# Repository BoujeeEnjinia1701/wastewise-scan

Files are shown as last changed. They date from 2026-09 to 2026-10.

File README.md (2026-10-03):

# WasteWise Scan

     

**Area:** Circular Materials · **TRL:** 3 of 9 (proof of concept on paper) · **Budget:** USD 150 value-engineering target; constructable prototype USD 167.50 in parts · **Difficulty:** 3 of 5

Handheld near-infrared scanner that identifies common plastic resins (PET, HDPE, PP, PS, PVC) in about a second using a low-cost multispectral sensor, shows the result and a local price grade, and logs scans. It pairs with WasteWise-ml for items the spectrum cannot resolve.

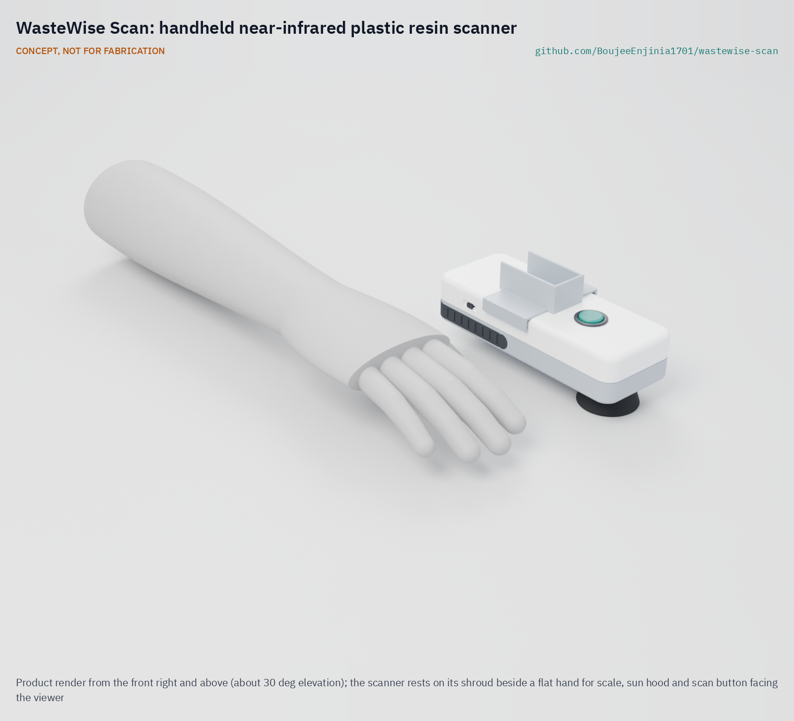
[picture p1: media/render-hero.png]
WasteWise Scan: handheld near-infrared resin scanner, product render


[Exploded render](media/render-exploded.png) · [Interactive 3D model](media/viewer.html) · [Concept blueprint (PDF)](media/concept-blueprint.pdf) · [General arrangement (PDF)](cad/drawings/WSC-DWG-001.pdf) · [Calculations](docs/04-calcs/01-sizing.md) · [Prototype build plan](docs/05-build-plan.md) · [Design decisions](docs/06-design-decisions.md) · [Review note](docs/REVIEW.md)

## Concept rationale

Resin type is a chemical property, so the scanner measures chemistry rather than appearance. Polymers absorb short-wave infrared light at wavelengths set by their C-H bonds, and eight discrete LEDs read against one InGaAs photodiode sample those bands for a small fraction of the cost of a spectrometer. The open Plastic Scanner project from TU Delft showed that this discrete-band approach can separate common resins; WasteWise Scan adds what a waste picker or cooperative needs in the field: a result in a third of a second, a local price grade, a log, and a clear "unknown" when the scanner cannot tell.

The design is open and garage-buildable because the people who would use it most sort plastic far from any service network. Every part is an off-the-shelf module or a 3D print, the price table is edited on the device, and no cloud service is involved. An open design lets cooperatives, universities and repair shops build, fix and adapt it, and lets labeled scan data be shared with Plastic Scanner and WasteWise-ml where licenses allow.

## Burning platform

Only 9 % of plastic waste is successfully recycled worldwide ([OECD, 2022](https://www.oecd.org/en/about/news/press-releases/2022/02/plastic-pollution-is-growing-relentlessly-as-waste-management-and-recycling-fall-short.html)), and the world generated 2.56 billion tonnes of solid waste in 2022, heading for 3.86 billion tonnes by 2050 without action ([World Bank, *What a Waste 3.0*](https://www.worldbank.org/en/publication/what-a-waste)).

Much of the recycling that does happen rests on informal workers. An estimated 15 to 20 million people work as informal waste pickers ([WIEGO, citing ILO data](https://www.wiego.org/informal-economy/occupational-groups/waste-pickers)), and one widely cited model estimates that the informal sector collects about 58 % of the plastic waste collected for recycling worldwide ([Lau et al. 2020, *Science*](https://doi.org/10.1126/science.aba9475), as cited in [ISWA, 2022](https://www.iswa.org/wp-content/uploads/2022/09/A-Seat-at-the-Table.pdf)). These workers sort by eye, touch and burn tests, and a wrong call costs them money or spoils a bale.

## Where it could be used

### By industry

| Industry | Use |
| --- | --- |
| Informal waste picking and cooperatives | Settle doubtful items at the pile and grade them against the local price table |
| Aggregators and small recyclers | Spot-check incoming bales for PVC in PET and other off-resin items before paying |
| Plastic scrap trade and export | Check that a bale is clean, pre-sorted single-polymer scrap before it is declared as such |
| Municipal and extended producer responsibility programs | Audit what collection points and sorting sheds actually recover |
| Training, NGOs and research | Teach resin identification and collect open, labeled spectra for classifiers such as WasteWise-ml |

### By country or region

| Country or region | Why it matters there |
| --- | --- |
| India | A national labour survey counted about 2.2 million waste pickers, as cited by WIEGO ([WIEGO](https://www.wiego.org/informal-economy/occupational-groups/waste-pickers)) |
| Brazil | Over 281,000 people work as waste pickers (catadores), many in cooperatives that grade and sell by material ([WIEGO](https://www.wiego.org/informal-economy/occupational-groups/waste-pickers)) |
| Colombia | Bogotá alone has more than 25,000 waste pickers ([WIEGO](https://www.wiego.org/informal-economy/occupational-groups/waste-pickers)) |
| Sub-Saharan Africa (for example Kenya and Nigeria) | Collection rates are low and waste is mostly disposed of unsafely, so value recovered by informal sorters matters more ([World Bank](https://www.worldbank.org/en/publication/what-a-waste)) |
| European Union | The Packaging and Packaging Waste Regulation, in force since 11 February 2025 and applying from 12 August 2026, aims to raise the use of recycled plastics in packaging, which depends on clean resin streams ([European Commission](https://environment.ec.europa.eu/topics/waste-and-recycling/packaging-waste_en)) |
| United States | Since 1 January 2021 most plastic scrap exports need the importing country's prior written consent unless they are clean, pre-sorted, almost single-polymer scrap ([US EPA](https://www.epa.gov/hwgenerators/new-international-requirements-export-and-import-plastic-recyclables-and-waste)) |

## What sparked the idea

The idea traces back to the Basel Convention's plastic waste amendments, agreed by about 180 governments in Geneva in May 2019 ([UNEP](https://www.unep.org/news-and-stories/press-release/governments-agree-landmark-decisions-protect-people-and-planet)) and in effect from 1 January 2021. Under them, plastic scrap "almost exclusively" of one non-halogenated polymer, or a PE, PP and PET mix destined for separate recycling, that is pre-sorted and clean can move as ordinary scrap (entry B3011), while mixed, contaminated or PVC-containing plastic needs prior written consent (entry Y48) ([US EPA](https://www.epa.gov/hwgenerators/new-international-requirements-export-and-import-plastic-recyclables-and-waste)). The rule turned resin identity into a legal and commercial line, yet the check it relies on happens by eye, at the pile, long before any laboratory. A handheld that tells PET from PP or PVC at the point of sorting is the missing tool that the amendments point at.

## Problem

Cameras cannot reliably tell PET from PP or HDPE, yet resin type sets the price a waste picker or small recycler receives. Commercial near-infrared sorters cost far too much for informal and small-scale operators.

## Concept

Press the soft shroud against an item and press the button. The scanner pulses eight near-infrared bands from 850 to 1,650 nm, reads the reflection with an InGaAs photodiode, and in about 0.33 s (calculated) shows the resin, a confidence mark and the local price grade. Black, dark and low-confidence items read "unknown" and can be passed to WasteWise-ml. A white reference inside the protective cap keeps it calibrated.

The scaffold named an AS7265x-class sensor, but that chip stops at 940 nm, short of the main polymer bands. The design uses discrete LEDs and an InGaAs photodiode instead, following the open Plastic Scanner project (decided by Amish, 2026-09-25).

At TRL 3 the calculations (WSC-CAL-001 v0.4) show the constructable design meets seven of fourteen requirements on paper. The mass requirement (R6, 250 g) is not met since the parts needed to build it were added: about 238 g, 258 g with the cap (8 g over) after the 2.0 mm shell walls decided on 2026-10-02. Following decisions Amish accepted on 2026-09-25 (WSC-DDR-003), clear items in sun are backed with the black calibration cap and the scanner refuses a result when it detects light through an unbacked item, and a clip-on hood shades the screen. Screen legibility in direct sun (R7), resin accuracy near 1,700 nm (R1) and the shared record with WasteWise-ml (R13) are at risk.

Full design precis: [docs/02-concept.md](docs/02-concept.md)

## Key components

- Ring of eight NIR and SWIR LEDs, 850 to 1,650 nm
- InGaAs photodiode with transimpedance amplifier and 24-bit ADC
- ESP32-S3 board with 1.9 in display
- One 18650 Li-ion cell with USB-C charging
- Printed rugged housing with black TPU light shroud
- Black calibration cap with white PTFE reference, also used to back clear items in sun
- Clip-on sun hood over the display
- Printed display frame, cell strap and optical head block; foam gasket and M3 screws into brass inserts

Value-engineering target: USD 150. Estimated cost of the constructable design: USD 167.50 (USD 17.50 over the target), from the priced bill of materials ([bom/bom.csv](bom/bom.csv)).

## Building the prototype

The [prototype build plan](docs/05-build-plan.md) (WSC-BLD-001) shows how to make each of the 21 components and put them together in 13 steps, with a making sketch for every printed or cut part and a picture for every joint and step. Most parts are 3D printed in PETG and TPU; the rest are bought optics, electronics and fixings, joined with M3 screws into brass heat-set inserts. Drawing the plan made the concept physically buildable: the shells, optics, cell and display gained fixings, recorded in [WSC-DDR-004](docs/decisions/0004-design-for-construction.md) for Amish's review. It is a plan; nothing has been built yet.

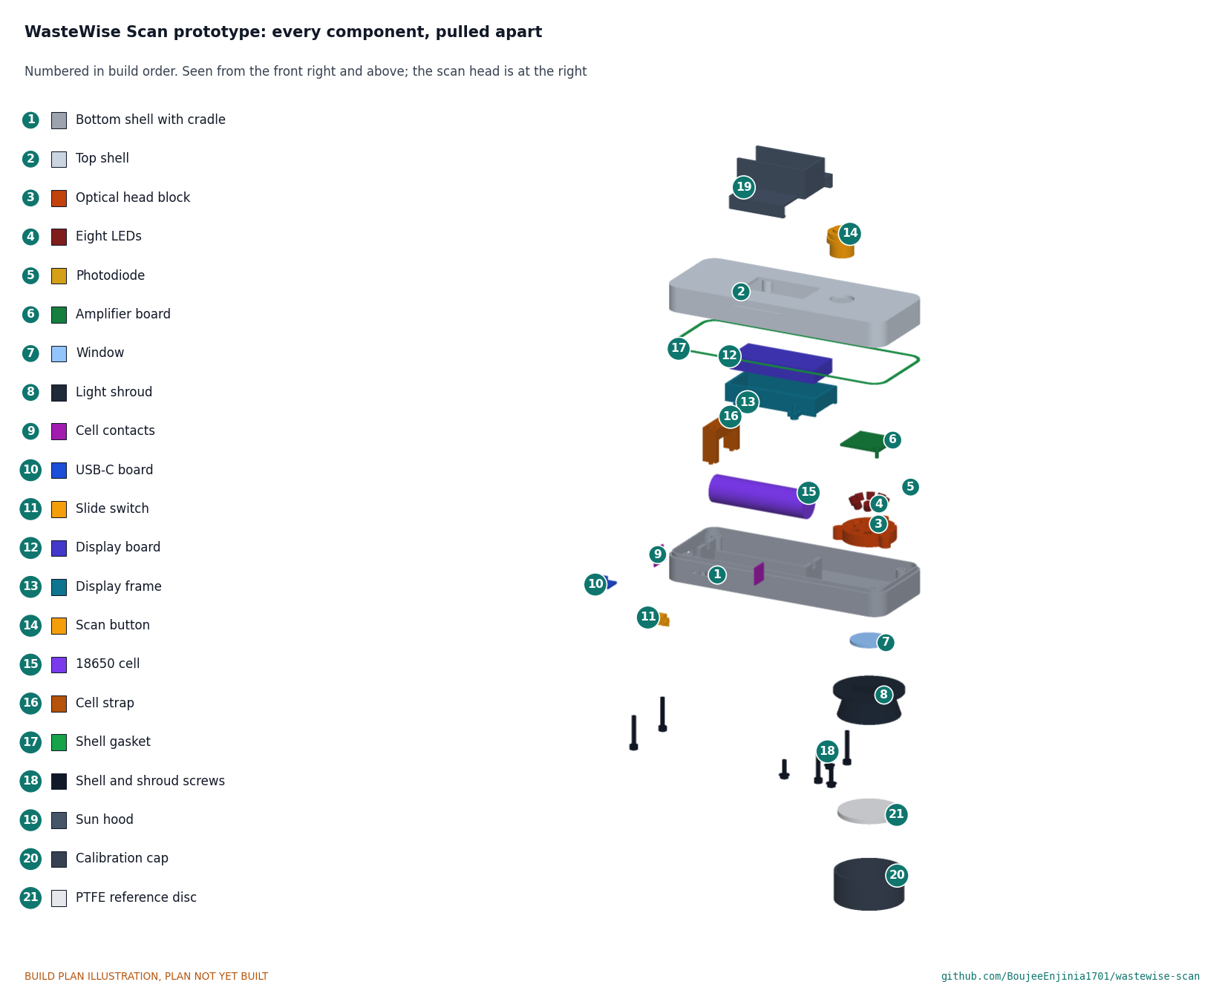
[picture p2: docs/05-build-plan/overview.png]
WasteWise Scan prototype: every component pulled apart and numbered in build order


## Safety

> **Safety:** The scanner identifies plastic resin only. Never use it to judge whether hazardous, medical or chemical waste is safe to handle. Black and dark plastics absorb NIR and read as unknown. The 18650 lithium-ion cell must be a protected cell, charged only with the built-in charger and kept out of heat. The SWIR LEDs are invisible; do not look into the window during a scan, and keep the hardware limit on LED on-time. Do not back sharp, broken or contaminated items with the cap by hand; scan them in shade instead.

## Repository layout

| Folder | Contents |
| --- | --- |
| `docs/` | Problem, concept, requirements, calculations and design decisions |
| `cad/src/` | build123d Python source, the source of truth for all geometry |
| `cad/step/`, `cad/stl/` | Exported models for FreeCAD, other CAD tools and printing |
| `cad/drawings/` | 2D sketches and dimensioned drawings |
| `bom/` | Bill of materials |
| `electronics/` | KiCad schematics and PCB layouts |
| `firmware/` | Microcontroller code |
| `media/` | Renders, perspectives and photos |
| `build-log/` | Dated prototyping notes |

## Documentation

Controlled documents follow the portfolio [documentation standard](.kit/STANDARDS.md). Each carries a document ID (WSC-PRC-001 for the precis), a version and a revision history. Branded PDFs are built with `python .kit/render.py` and attached to GitHub Releases when a document is tagged, for example `WSC-PRC-001/v1.0`.

## Credits

Designed by Amish Chadha. See [CONTRIBUTORS.md](CONTRIBUTORS.md) for roles. To cite this design, use [CITATION.cff](CITATION.cff) (GitHub shows it as "Cite this repository").

AI assistance (Claude) was used to accelerate concept renders, prototype documentation and first-pass sizing calculations. Design direction and all decisions are Amish Chadha's, recorded in this repository's decision records (`docs/decisions/`).

## Licenses

- **Hardware** (CAD, drawings, BOM, electronics): [CERN-OHL-S v2](LICENSE)
- **Software** (firmware, scripts, notebooks): [MIT](LICENSE-SOFTWARE)

A project of the [Design Molecule](https://designmolecule.com) lab.

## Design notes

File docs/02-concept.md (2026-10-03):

---
doc_id: WSC-PRC-001
title: WasteWise Scan design precis
project: WasteWise Scan
doc_type: Design precis
version: "0.7"
status: Draft
date: '2026-10-02'
author: Amish Chadha
license: CERN-OHL-S-2.0
revisions:
- version: "0.1"
  date: '2026-09-24'
  author: Amish Chadha
  change: Initial scaffold
- version: "0.2"
  date: '2026-09-25'
  author: Amish Chadha
  change: Populate to TRL 2 (architecture, first-order numbers, safety, media)
- version: "0.3"
  date: '2026-09-25'
  author: Amish Chadha
  change: TRL 3; decisions of WSC-DDR-001 applied; numbers from WSC-CAL-001; 47 kOhm gain and interleaved dark readings; new findings on sunlight, display and window crosstalk
- version: "0.4"
  date: '2026-09-25'
  author: Amish Chadha
  change: Recommendations accepted by Amish (DDR-002); WSC-DDR-003 applied (black cap as backing, dark-level prompt, sun hood, open-air crosstalk reading, shared record); numbers from WSC-CAL-001 v0.2
- version: "0.5"
  date: '2026-10-02'
  author: Amish Chadha
  change: Constructable design (WSC-DDR-004) and build plan WSC-BLD-001; components, mass and cost from WSC-CAL-001 v0.3; budget as a value-engineering target
- version: "0.6"
  date: '2026-10-02'
  author: Amish Chadha
  change: Open questions answered by Amish's decisions of 2026-10-02 (WSC-DEC-001)
- version: "0.7"
  date: '2026-10-02'
  author: Amish Chadha
  change: Mass restated for 2.0 mm shell walls (238 g, 258 g with cap); paper band study result; numbers from WSC-CAL-001 v0.4
---

# WasteWise Scan design precis

WasteWise Scan is a palm-sized scanner that the user presses against a plastic item. It flashes eight near-infrared bands one after another, reads the reflection with an InGaAs photodiode, and in about 0.33 s shows the resin, a confidence mark and the local price grade. The calculation note WSC-CAL-001 v0.4 shows that it meets the speed, battery, mass, sunlight, logging, calibration, eye-safety and prototype cost requirements on paper. Clear and translucent items are backed with the black calibration cap in sun, and a clip-on sun hood shades the display (decisions accepted by Amish on 2026-09-25, WSC-DDR-003). Direct-sun legibility (R7) is at risk because the hood cannot shade every sun angle, and resin accuracy (R1) remains at risk near 1,700 nm. Value-engineering target: USD 150. Estimated cost of the constructable design: USD 167.50 (USD 17.50 over the target). Since 2026-10-02 the design is constructable (WSC-DDR-004, open for Amish's review): screws, a gasket, an optical head block, a cell cradle and strap, a display frame and clip legs on the hood were added, and the scanner now weighs about 238 g (258 g with the cap) with the 2.0 mm shell walls Amish decided on 2026-10-02, so the 250 g mass requirement (R6) is not met, 8 g over with the cap. The prototype build plan is WSC-BLD-001 ([05-build-plan.md](05-build-plan.md)).

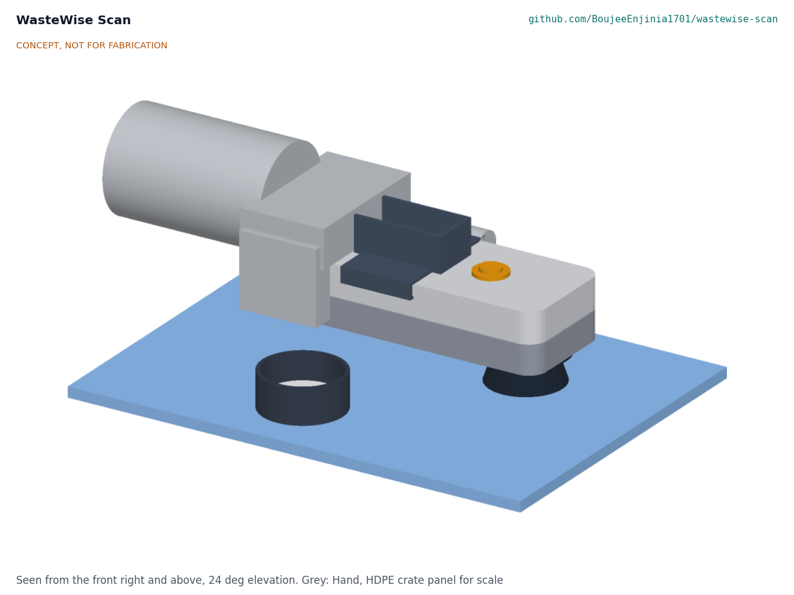
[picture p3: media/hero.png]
Hero render


*Figure 1. Concept render from the parametric model. The grey hand and the blue crate panel are for scale only.*

## The sensor

The scaffold named an 18-channel AS7265x-class sensor. That chip covers about 410 to 940 nm ([SparkFun Triad board](https://www.sparkfun.com/products/15050)), which misses the polymer absorption bands near 1,150 to 1,250 nm and 1,650 to 1,750 nm that NIR sorters rely on (see WSC-PRB-001 and the review by [Neo et al. 2022](https://doi.org/10.1016/j.resconrec.2022.106217)). Amish decided on 2026-09-25 (WSC-DDR-001, D1) to use the approach of the open [Plastic Scanner](https://github.com/Plastic-Scanner) project instead: discrete NIR and short-wave infrared (SWIR) LEDs from 850 to 1,650 nm and one InGaAs photodiode ([Hackaday, 2021](https://hackaday.com/2021/12/13/an-open-source-detector-for-identifying-plastics/)). It is still a low-cost multispectral sensor, so the pitch is unchanged.

## How it works

1. **Press.** The user presses the soft black shroud against a flat or gently curved part of the item. The shroud blocks sunlight falling on the spot and fixes the item 22 mm from the detector.
2. **Illuminate and read.** On a button press the firmware pulses each of eight LEDs in turn (850, 940, 1,050, 1,200, 1,300, 1,450, 1,550 and 1,650 nm; WSC-DDR-001 D4). Each band reading sits between two dark readings, so slow changes in ambient light are subtracted. If the mean dark level exceeds 0.71 times the weakest band reading, which happens when sunlight passes through an unbacked clear item, the scanner shows "shade or back with cap" instead of a result (WSC-DDR-003 D8). The user then holds the black calibration cap behind the item and scans again. A transimpedance amplifier with 47 kΩ feedback and a 24-bit ADC take four conversions per reading. Eight bands and nine darks take about 240 ms.
3. **Normalize.** Readings have the window crosstalk offset from the last open-air reading subtracted (WSC-DDR-003 D11) and are divided by the last white reference taken in the calibration cap, giving a reflectance per band that is independent of LED aging and, to first order, temperature. A board temperature reading flags drift of more than 5 %, which takes about 12.5 °C of change.
4. **Classify.** A small classifier on the ESP32-S3 (linear discriminant analysis or a small decision tree on normalized band ratios; WSC-DDR-001 D5) returns a resin and a confidence. Below the confidence threshold, or when mean reflectance is under about 0.08 (black items), it shows "unknown".
5. **Show and log.** The display shows resin code, name, color and icon, plus the grade from the local price table. Each scan is logged as a 64-byte record for export over USB as CSV or JSON Lines.
6. **Hand off.** Unknown or low-confidence items can be photographed with a phone and passed to WasteWise-ml. The shared record proposed in WSC-DDR-002 lets the two results be joined on a pair ID.

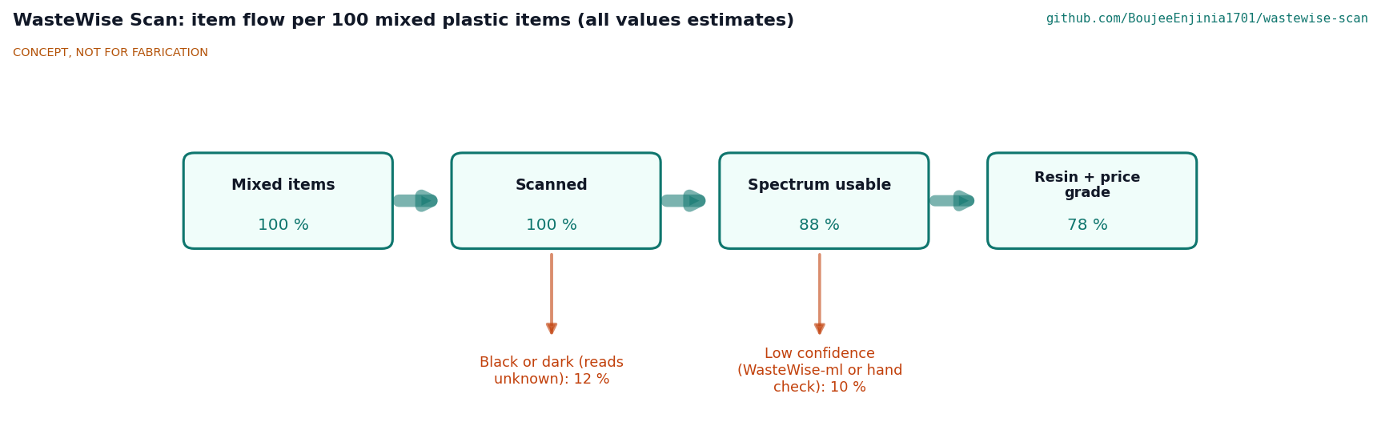
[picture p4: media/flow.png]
Item flow


*Figure 2. Item flow per 100 mixed plastic items. All values are estimates for concept review.*

## Main components

Table 1. Main components. Numbers match the BOM, the exploded view and drawing WSC-DWG-001.

| # | Component | Choice | Notes |
| --- | --- | --- | --- |
| 1 | Top shell | 3D-printed PETG with display window, button hole and eight insert bosses | Four M3 screws from below; foam gasket on the rim; about 51 g |
| 2 | Controller and display | ESP32-S3 board with 1.9 in IPS display and on-board Li-ion charger (LilyGO T-Display-S3 class) | No custom PCB (WSC-DDR-001 D3) |
| 3 | LED ring | Eight LEDs on a 20 mm pitch circle in a printed optical head block, each tilted about 23° so the beams meet on the item | SWIR LEDs dominate cost; the block also seats the photodiode and carries item 5 |
| 4 | Photodiode | InGaAs PIN photodiode, 1 mm, TO-46, about 900 to 1,700 nm, inside a short baffle tube | Standard InGaAs, cutoff near 1,700 nm |
| 5 | Amplifier and ADC | Low-noise op-amp transimpedance stage with 47 kΩ feedback, 24-bit ADC (ADS1220 class), LED switches | On perfboard for the first build |
| 6 | Window | Borosilicate glass disc, 25 mm, 2 mm | Keeps dust out; uncoated |
| 7 | Light shroud | Black TPU cone, 18 mm deep, 42 mm across the rim, 36 mm inside, with a 47 mm clamping flange | Blocks direct light, sets distance; its three screws clamp the window and head block |
| 8 | Battery | One protected 18650 Li-ion cell, 3,000 mAh | WSC-DDR-001 D7 |
| 9 | Cell contacts and USB-C | Spring and flat contacts in a cradle printed with the bottom shell; USB-C power board in the tail wall | A printed strap (item 18) holds the cell against about 550 N on a corner drop |
| 10 | Bottom shell and grip | 3D-printed PETG, textured grip, window hole, cell cradle, screw bosses | About 56 g |
| 11 | Scan button | Large sealed 16 mm push button for gloved hands | |
| 12, 13 | Calibration cap | Printed black PETG cap, 48 mm OD, with a 38 mm white PTFE reference disc; stores over the shroud | White reference (WSC-DDR-001 D6); also the backing for clear items in sun (WSC-DDR-003 D9) |
| 14 | Sun hood | Clip-on printed PETG hood, walls 20 mm high on both sides and at the head end of the display window, open toward the user; legs snap under ribs on the top shell | About 11 g and $1 (WSC-DDR-003 D10, WSC-DDR-004) |
| 17 | Display frame | Printed PETG frame holding the display board under the window | Four M3 screws into the top shell |
| 18 | Cell strap | Printed PETG bridge across the cell | Two M3 screws into floor bosses [J4] |
| 19 | Shell gasket | Closed-cell foam tape on the bottom shell rim | Squeezed to 0.6 mm; the bosses set the squeeze |

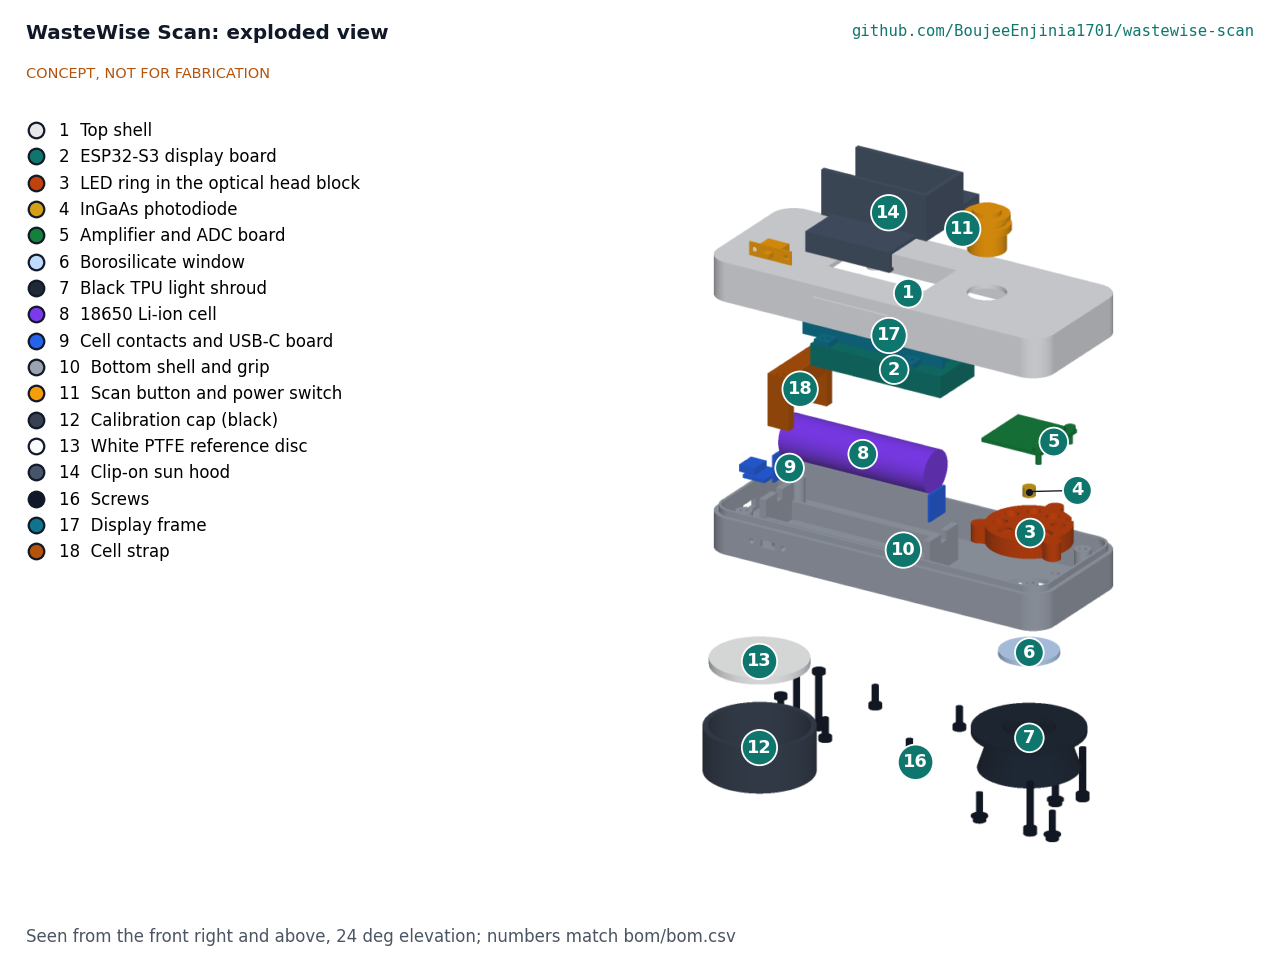
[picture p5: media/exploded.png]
Exploded view


*Figure 3. Exploded view with BOM numbers.*

## Key numbers

All values are from WSC-CAL-001 (tags in brackets) and rest on the assumptions stated there.

Table 2. Key numbers.

| Quantity | Value | Requirement |
| --- | --- | --- |
| Scan time | about 0.33 s [E2] | R2 (1.5 s) met |
| Detected signal on the white reference | 0.35 to 5.2 µW, 10 to 115 mV at 47 kΩ [C2] | |
| Worst signal-to-noise ratio in shade | about 450 (clear item, 1,650 nm) [C4] | R1 needs about 200 |
| Sunlight through a clear item | about 23 µA, about 900 times the weakest signal [D1, D3] | Refused by the dark-level prompt [D7] |
| Ambient error, clear item backed with the cap | 0.36 % of signal [D6] | R4 met by estimate |
| Average power | about 0.39 W [F2] | |
| Battery life | about 22 h [F2] | R5 (8 h) met |
| Log capacity | about 131,000 scans at 64 B [G1] | R9 met |
| Mass | about 238 g, 258 g with cap [A3] | **R6 (250 g) not met**, 8 g over |
| Size | 160 x 62 x 34 mm (6.3 x 2.4 x 1.3 in), 72 mm high with shroud and sun hood, 68 mm wide over the hood legs [A1] | R6 size met |
| Display contrast in 100 klx sun | about 1.6:1 unshaded; 5.2:1 where the hood shades the screen [I1, I3, I4] | **R7 at risk** |
| LED irradiance at 200 mm | 3.9 W/m² against 100 W/m² [H2] | R14 met by estimate |
| Parts cost | USD 167.50 [K2] | USD 17.50 over the USD 150 value-engineering target |

## Key design choices

- **Discrete LEDs and one InGaAs photodiode rather than a spectrometer or a visible-range chip** (WSC-DDR-001 D1). A SWIR spectrometer module costs far more than the budget; a visible-range chip misses the polymer bands. Eight bands are kept: the paper band study (WSC-CAL-001 v0.4, B4) scores a six-band set at 88 % against 89.5 % for eight on approximate reference spectra, which points to the six-band saving, but both are short of 95 % at the assumed item scatter, so the choice waits for measured items.
- **Contact measurement through a shroud.** Pressing on the item fixes the geometry and removes direct light on the spot. It does not stop light passing through clear items, so clear and translucent items in sun are backed with the black cap and the firmware refuses a result when the dark level shows through-light (WSC-DDR-003 D8, D9).
- **Low gain and interleaved darks.** The 47 kΩ gain keeps sunlight through clear items inside the ADC range; interleaved dark readings cancel slow ambient changes. Faster changes are handled by the backing step; LED modulation at 2 kHz was checked on paper and does not remove the need for it (WSC-CAL-001 D8).
- **Say "unknown" rather than guess.** A wrong call can contaminate a bale; the confidence threshold is set for few false results, accepting more unknowns (R3).
- **White reference in the protective cap** (D6). The user calibrates by pressing the scanner into its own cap, at the start of a shift and again when the drift warning shows; the same routine takes an open-air reading to remove window crosstalk. The cap is printed in black so it can also back clear items.
- **Local price table on the device.** Grades are what matter to users, and prices are local and change often. The cooperative edits them; no cloud service is needed.
- **Clip-on sun hood** (WSC-DDR-003 D10). A printed hood shades the display for most sun angles at negligible cost; large color and icon cues stay the primary result.
- **One common 18650 cell** (D7). Available and replaceable in most markets; the board's charger keeps the build simple.

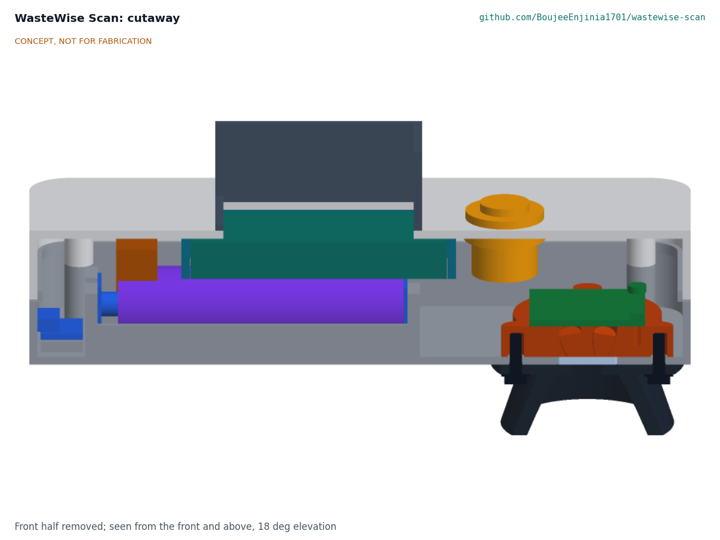
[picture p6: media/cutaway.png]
Cutaway


*Figure 4. Cutaway: LED ring, photodiode, amplifier board and window above the shroud, with the cell and controller behind.*

## Findings from the calculations and decisions taken

- **Clear items in sun (R4, now met by estimate).** Light passing through a clear or translucent item reaches the detector from inside the shroud, and hand movement changes it faster than dark subtraction can follow. Decided (WSC-DDR-003 D8, D9): back such items with the black cap (0.36 % error) and refuse a result when the dark level shows through-light. The classifier needs training data in this backed mode.
- **Display in direct sun (R7, now at risk).** A 400 cd/m² IPS screen washes out in 100 klx sun. Decided (D10): a clip-on sun hood, which gives about 5.2:1 on the shaded part but cannot shade the screen with the sun near its normal or over the open side.
- **Window crosstalk.** LED light reflected by the window's outer surface reaches the detector at about the same level as the item signal. Decided (D11): an open-air reading in the calibration routine subtracts it. Because a 10 % change from window dirt would leave about 10 % error, the fallback of a baffle extended through the glass (option (b)) is probably needed; that needs measurement at TRL 4.
- **PE versus PP (R1 at risk).** The 1,650 nm band is clipped by the detector cutoff and only samples the short edge of the 1,650 to 1,750 nm region. Decided by Amish, 2026-10-02: keep eight bands, and add an extended InGaAs band only if the paper band study shows PE and PP cannot be told apart to R1 with eight (WSC-DEC-001). The study is done: PE against PP is 93 % with eight bands at the assumed item scatter, above 98 % at 1.0 % scatter, so it neither shows nor rules out the problem and the extended band is not added (WSC-CAL-001 v0.4, B5 to B7).

## Safety

> **Safety:** The scanner identifies plastic resin only. It must never be used to judge whether an item is safe to handle, or to classify hazardous, medical, chemical or pesticide containers. Waste handling carries cut, needle-stick and chemical risks: wear gloves and follow local guidance.

> **Safety:** Backing a clear item with the calibration cap puts the user's hand close to the item. Do not back sharp, broken or contaminated items by hand; scan them in shade instead.

> **Safety:** The 18650 lithium-ion cell stores about 11 Wh. Use a protected cell from a known supplier, charge with the board's charger only, do not charge in direct sun or above 45 °C, and stop using a cell that is dented, swollen or wet. The cradle must hold the cell firmly in a drop. Do not leave the device on hot surfaces or in closed vehicles.

> **Safety:** The SWIR LEDs are invisible to the eye, so a user cannot tell when they are on. In normal use they fire for about 14 ms each per scan, which keeps emission far inside the IEC 62471 exempt group by estimate (WSC-CAL-001, H). An LED stuck on at the shroud rim could exceed the corneal limit over long exposures, so the LED drivers need a hardware limit on on-time that firmware cannot override. Do not look into the window during a scan.

- Black and dark items read "unknown". Users must not treat "unknown" as any particular resin.
- The result is advice for sorting, not a certificate of material grade for sale.

## Open questions

1. **First users and region** for co-design and the first price table. Decided by Amish, 2026-10-02: a member-owned waste picker cooperative that already sells sorted plastics to scrap buyers; the first candidate to approach is SWaCH in Pune, India, the partner chosen for WasteWise-ml, with Pune scrap prices as the first price table (WSC-DEC-001).
2. **Who the $150 volume target is for:** decided by Amish, 2026-10-02: cooperatives, buying a shared scanner (WSC-DEC-001).
3. **Extended InGaAs band.** Decided by Amish, 2026-10-02: eight bands; the band study comes first (WSC-DEC-001). The paper band study is done and is inconclusive; the extended band is not added and is raised as a proposal.
4. **Scan record format.** One shared record with a `pair_id` join was decided on this side on 2026-09-25 (WSC-DDR-002 v0.2, WSC-DDR-003 D12); WasteWise-ml has still to adopt it, and the pair ID is shown as a QR code on the scanner screen for the phone to scan, with digits as a fallback (decided by Amish, 2026-10-02, WSC-DEC-001).
5. **Band study.** A paper study on published reference spectra to confirm the band set and whether six bands suffice (WSC-DDR-001 D2, D4). Not yet done.

Concept media: [blueprint sheet](../media/concept-blueprint.pdf), [interactive 3D model](../media/viewer.html). General arrangement: [WSC-DWG-001](../cad/drawings/WSC-DWG-001.pdf).

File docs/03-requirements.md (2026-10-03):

---
doc_id: WSC-REQ-001
title: WasteWise Scan requirements
project: WasteWise Scan
doc_type: Requirements
version: "0.7"
status: Draft
date: '2026-10-02'
author: Amish Chadha
license: CERN-OHL-S-2.0
revisions:
- version: "0.1"
  date: '2026-09-24'
  author: Amish Chadha
  change: Initial scaffold
- version: "0.2"
  date: '2026-09-25'
  author: Amish Chadha
  change: First measurable requirements for TRL 2
- version: "0.3"
  date: '2026-09-25'
  author: Amish Chadha
  change: TRL 3 status from WSC-CAL-001; R12 redefined per WSC-DDR-001 D2; R13 points to the draft record in WSC-DDR-002
- version: "0.4"
  date: '2026-09-25'
  author: Amish Chadha
  change: Recommendations accepted by Amish (DDR-002); R4, R6, R11 and R12 restated per WSC-DDR-003; status from WSC-CAL-001 v0.2
- version: "0.5"
  date: '2026-10-02'
  author: Amish Chadha
  change: Status from WSC-CAL-001 v0.3 for the constructable design (WSC-DDR-004); R6 not met; R12 reported against the value-engineering target
- version: "0.6"
  date: '2026-10-02'
  author: Amish Chadha
  change: R6 and R13 status notes record Amish's decisions of 2026-10-02 (WSC-DEC-001); no status changed
- version: "0.7"
  date: '2026-10-02'
  author: Amish Chadha
  change: R6 restated for 2.0 mm shell walls (238 g, 258 g with cap); R1 note carries the paper band study; no status changed
---

# WasteWise Scan requirements

These are the requirements for the TRL 3 design. Status is from the calculation note WSC-CAL-001 v0.4 (tags in brackets), for the constructable design of WSC-DDR-004. R6 (mass) is not met on paper since the parts needed to build the scanner were added; R1, R7 and R13 are at risk, and R3 and R10 cannot be verified at TRL 3. R12 is reported against the USD 150 value-engineering target. Targets stay proposals for co-design with users. R12 was redefined by Amish's decision of 2026-09-25 (WSC-DDR-001, D2). At this revision R4, R6, R11 and R12 are restated to carry the decisions Amish accepted on 2026-09-25 (WSC-DDR-003): the backing step for clear items, the clip-on sun hood and the open-air calibration reading.

Table 1. Requirements.

| ID | Requirement | Target | Status at TRL 3 (WSC-CAL-001) | Verification (TRL 3 or later) |
| --- | --- | --- | --- | --- |
| R1 | Identify common resins | PET, HDPE, PP, PS and PVC, plus "other" and "unknown"; 95 % or more correct on clean, dry, non-black items of 1 mm wall or more | **At risk.** The 1,650 nm band reaches only the short edge of the 1,650 to 1,750 nm region on standard InGaAs (centroid about 1,628 nm) [B2]; signal-to-noise ratio of 450 or more in shade [C4] | Paper band study on approximate published reference spectra done (WSC-CAL-001 v0.4): 89 % correct with eight bands, 93 % for PE against PP, short of 95 % at the assumed item scatter and sensitive to it [B4 to B7]; a labeled item set of 200 or more settles it |
| R2 | Fast result | 1.5 s or less from button press to result | Met: about 0.33 s [E2] | Timing budget |
| R3 | Fail safe on unreadable items | Black, dark, wet or very thin items read "unknown"; wrong resin shown for 2 % or fewer of all scans | Not verifiable at TRL 3. Black items fall well below the 0.08 reflectance threshold [C6]; the wrong-result rate needs item data | Confidence threshold study; later item test |
| R4 | Work in sunlight | Same result indoors and in direct sun up to 100 klx when the shroud is pressed to the item; clear and translucent items are backed with the calibration cap, and the scanner refuses a result ("shade or back with cap") when its dark level shows light through an unbacked item (WSC-DDR-003 D8, D9) | Met by estimate: ambient error 0.13 % of signal on opaque items [D5] and 0.36 % on backed clear items [D6]; unbacked clear items in sun are refused [D7] | Stray light estimate; later indoor and sun test |
| R5 | Last a shift | 8 h or more at 4 scans per minute on one charge; USB-C charging | Met: about 22 h [F2] | Power budget |
| R6 | One-handed and light | 250 g or less including the sun hood; body no larger than 170 x 65 x 40 mm (6.7 x 2.6 x 1.6 in) plus shroud and clip-on sun hood | **Not met:** about 238 g, 258 g with cap (8 g over), after the parts added for construction (was 209 g) and the 2.0 mm shell walls decided by Amish on 2026-10-02 (254 g and 274 g before); 160 x 62 x 34 mm [A1, A3]. Weighed at TRL 4 (WSC-DEC-001) | Parametric model, then weighing |
| R7 | Readable by anyone | Result as resin code, name, color and icon, legible at arm's length in direct sun; local language; no reading needed to use | **At risk.** With the clip-on sun hood (WSC-DDR-003 D10), about 5.2:1 where the hood shades the screen, fully shaded with the sun 50° or more off the screen normal on a side; about 1.6:1 with the sun near the normal or over the open side [I3, I4] | Contrast estimate; design review with users |
| R8 | Local price grade | Shows a price grade from a table the user or cooperative edits on the device; works offline | Met by design | Design review |
| R9 | Log scans | 10,000 or more scans stored on the device with time, result, confidence and spectrum; export as CSV over USB; no cloud needed | Met: about 131,000 scans in an 8 MB partition [G1] | Storage calculation |
| R10 | Rugged | Survives 1.2 m (4 ft) drop onto concrete; IP54 target; 0 to 45 °C | Not verifiable at TRL 3. Corner drop about 1,200 g; the cell strap holds the cell against about 550 N with a margin of 1.3 [J1, J2, J4]; foam gasket between screwed shells; the drop case with 2.0 mm shell walls is checked at TRL 4 | Design review, later drop and spray tests |
| R11 | Stay calibrated | White reference check and an open-air window-crosstalk reading in 10 s or less using the calibration cap; warns when a check is overdue or drift exceeds 5 % | Met by design; 5 % drift after about 12.5 °C of temperature change [J3]. The crosstalk offset must stay within 0.5 % of itself between checks, which window dirt is likely to exceed [C7] | Design review |
| R12 | Low cost | $150 or less per unit is the volume target; the first prototype is accepted at about $164 in parts (the $163 accepted in WSC-DDR-001 D2 plus the $1 sun hood of WSC-DDR-003 D10); no custom PCB for the first build | USD 167.50 [K2]: USD 17.50 over the USD 150 value-engineering target, USD 3.50 above the prototype figure accepted on 2026-09-25 | Priced BOM |
| R13 | Work with WasteWise-ml | Low-confidence scans hand off to WasteWise-ml; scan records use a shared, documented format | **At risk.** Hand-off designed; one shared record with a `pair_id` join decided on this side (WSC-DDR-002 v0.2, WSC-DDR-003 D12); not yet adopted by WasteWise-ml. Pair ID by QR code on the screen and consented spectra terms decided by Amish, 2026-10-02 (WSC-DEC-001) | Interface note with WasteWise-ml |
| R14 | Eye-safe illumination | LED emission in the IEC 62471 exempt group; LEDs pulse only during a scan | Met by estimate: 3.9 W/m² at 200 mm against 100 W/m²; retinal 3.8 % of the limit [H2, H3] | Emission estimate, then datasheet values |

## Assumptions

- "Clean and dry" means rinsed or wiped items without labels over the scan spot. Real waste is dirtier; the classifier must reject rather than guess.
- About 10 to 15 % of items in a mixed post-consumer stream are black or very dark (estimate; varies strongly by region and should be measured with users).
- The first prototype's accepted cost of about $164 covers one scanner with its cap and sun hood; the $150 volume target assumes quantity prices for LEDs and the photodiode (WSC-DDR-001, D2).
- Four scans per minute is a busy spot-check pace, not every item: most items are sorted by eye and the scanner settles doubtful ones.
- Resin prices vary by city and season; the device stores grades (for example A, B, C, reject) and a local price list, not global prices.

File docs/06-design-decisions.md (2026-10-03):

---
doc_id: WSC-DEC-001
title: WasteWise Scan design decisions register
project: WasteWise Scan
doc_type: Design decisions register
version: "0.3"
status: Draft
date: '2026-10-02'
author: Amish Chadha
license: CERN-OHL-S-2.0
revisions:
- version: "0.1"
  date: '2026-10-02'
  author: Amish Chadha
  change: Register opened with the build plan; budget treated as a value-engineering target
- version: "0.2"
  date: '2026-10-02'
  author: Amish Chadha
  change: Amish approved the recommendations for open items 1 to 7 on 2026-10-02 (WSC-DDR-004 accepted, R6 by thinner walls, SWaCH as first candidate partner, cooperative price, eight bands, QR pair ID, consented spectra terms); moved to decisions made
- version: "0.3"
  date: '2026-10-02'
  author: Amish Chadha
  change: "Decisions carried out: 2.0 mm walls in the model (R6 238 g, 258 g with the cap); paper band study result raised as an open decision on the extended InGaAs band"
---

# WasteWise Scan design decisions register

Every design decision still to be made, and every decision made, in one place. Each decision is argued in full in its decision record under `docs/decisions/`; this register is the index Amish works from. The build plan (`docs/05-build-plan.md`) describes the design as it stands and does not list open decisions.

## Open decisions

| # | Decision | Options | Recommendation | Source |
| --- | --- | --- | --- | --- |
| 1 | Whether to add the extended InGaAs band now. The paper band study (WSC-CAL-001 v0.4, B4 to B7) gave 89.5 % correct with eight bands and 93 % for PE against PP at the assumed item scatter, above 98 % at 1.0 % scatter, so it neither shows nor rules out the problem that would trigger it. | (a) keep eight bands and settle it with the first labeled item set at TRL 4; (b) add a 1,700 to 1,750 nm band and an extended InGaAs photodiode now (extra cost not yet quoted; extended InGaAs photodiodes cost more than the USD 30 standard part). | (a): the result turns on item scatter, which only measured items can fix. | WSC-DDR-001, O3 |

## To confirm when parts are bought

| # | What to confirm | Why it matters | Source |
| --- | --- | --- | --- |
| 1 | The protected cell's length (the cradle allows 69 mm) and the contact pair's thickness and spring travel | The cradle end walls are 75 mm apart for a 69 mm cell, a 1 mm flat contact and a spring compressed to 4 mm plus its 1 mm plate | WSC-DDR-004, P6 |
| 2 | The display board's real outline (about 62 x 26 x 9.5 mm is assumed), its connector positions and its battery input | The display frame and the 0.25 mm gap to the ceiling are set from the assumed outline; the slide switch is wired in the battery lead | WSC-DDR-004, P8 |
| 3 | Whether the board charges the cell with the switch in the battery lead, and from its 5 V pin | Charging needs the switch on; if the board cannot charge through its 5 V pin, the USB-C board wiring changes | Build plan, wiring |
| 4 | The button's bezel (19 mm or less), its depth under the panel (14 mm or less) and its nut (20 mm or less across) | They set the button hole and its clearance to the display frame and the amplifier board | WSC-DDR-004, P9 |
| 5 | The slide switch's mounting hole pitch (15 mm) and body size (10 x 6 x 6 mm) | The wall slot and holes are printed into the bottom shell | WSC-DDR-004, P10 |
| 6 | Each LED's package: TO-46 (5.4 mm) or 5 mm lens LED (5.8 mm rim) | The head block pockets are 5.6 mm, for TO-46 cans | WSC-DDR-004, P4 |
| 7 | The foam gasket squeezes to about 0.6 mm with the bosses touching | The bosses stop the squeeze at 0.6 mm; a harder foam will not seal | WSC-DDR-004, P1 |
| 8 | The photodiode's responsivity curve near 1,700 nm | It decides how much of the 1,650 nm band is seen (R1) | BOM line 4; WSC-CAL-001 B |

## Value engineering

Value-engineering target: USD 150 (a hypothetical control target, not a limit). Estimated cost of the constructable design: USD 167.50 (USD 17.50 over the target). Main cost drivers and savings worth trying:

- The largest lines are the eight LEDs with their drivers (USD 62; the six short-wave infrared LEDs cost about USD 8 to 15 each), the InGaAs photodiode (USD 30) and the display board (USD 20). Optics are 55 % of the cost.
- Making the design constructable added USD 3.50 net: the display frame, cell strap and gasket (lines 17 to 19) and more fixings; the bought cell holder became contacts in a printed cradle, which saved USD 1.
- Savings worth trying: the six-band option (dropping 1,050 and 1,300 nm saves about USD 18) if measured items show six bands suffice (WSC-DDR-001 D2; the paper band study scores six bands at 88 % against 89.5 % for eight, WSC-CAL-001 v0.4 B4); buying the LEDs as a set from one maker; a second source for the photodiode; at volume, a bare ESP32-S3 module and display in place of the display board.

## Decisions made

| Date | Decision | Decided by | Record |
| --- | --- | --- | --- |
| 2026-09-25 | D1 to D7: discrete LEDs with an InGaAs photodiode; USD 150 kept as the volume target with about USD 163 accepted for the prototype; T-Display-S3 class board; the eight-band set; a small on-device classifier with shared data; PTFE white reference in the cap; one protected 18650 cell | Amish: "proceed with all of your recommendations across all batches. Make sure we don't proceed to TRL 4 on any of them." | WSC-DDR-001 |
| 2026-09-25 | D8 to D12: back clear items in sun with the black cap and refuse a result on through-light; black calibration cap; clip-on sun hood; open-air crosstalk reading in calibration; one shared scan record with a pair ID join | Amish: "i accept all your recommendations, go with them across all repos." | WSC-DDR-003, WSC-DDR-002 |
| 2026-09-26 | WasteWise Scan chosen as the pilot for product-grade renders; every drawing names the project and its repository | Amish | `docs/REVIEW.md`, session 2026-09-26 |
| 2026-09-30 | Make the design physically buildable while drawing the build plan; outstanding decisions go in this register, not the build plan | Amish: "If you are realising that the design cannot be built as per concept - fix the design assumptions to match and be physically feasible as you draw the illustrations." | WSC-DDR-004 (changes open for review, item 1 above) |
| 2026-10-01 | `budget_usd` is a value-engineering target, not a limit | Amish: "the budgets are a hypothethical control target to ensure we are thinking along a value engineering lens." | This register, Value engineering |
| 2026-10-02 | Design for construction accepted: the changes P1 to P12 of WSC-DDR-004, as made | Amish: "APPROVED: The open decisions from the last wave (TremorTrace to ZeerBox) came in after the review and aren't on the page either." | WSC-DDR-004, A2 |
| 2026-10-02 | Mass (R6): 2.0 mm shell walls, keeping the bosses and ribs, with the drop case checked at TRL 4; R6 stays not met until the first prototype is weighed (carried into the model 2026-10-02: 238 g, 258 g with the cap, 8 g over, since the shells saved 17 g rather than about 20 g), and the cap stays counted because it is carried for backing clear items | Amish: "APPROVED: The open decisions from the last wave (TremorTrace to ZeerBox) came in after the review and aren't on the page either." | WSC-DDR-004, A1; WSC-CAL-001 [A3] |
| 2026-10-02 | First partner and region: a member-owned waste picker cooperative that already sells sorted plastics to scrap buyers; the first candidate to approach is SWaCH in Pune, India, the partner chosen for WasteWise-ml, with Pune scrap prices as the first price table | Amish: "APPROVED: The open decisions from the last wave (TremorTrace to ZeerBox) came in after the review and aren't on the page either." | WSC-DDR-001, O1 |
| 2026-10-02 | Value-engineering target: the USD 150 value-engineering target is the price a cooperative pays for a shared scanner, not an individual picker | Amish: "APPROVED: The open decisions from the last wave (TremorTrace to ZeerBox) came in after the review and aren't on the page either." | WSC-DDR-001, O2 |
| 2026-10-02 | Extended InGaAs band: eight bands for the prototype; the paper band study on published reference spectra comes first, and the extended InGaAs band is added only if that study shows PE and PP cannot be told apart to R1 with eight | Amish: "APPROVED: The open decisions from the last wave (TremorTrace to ZeerBox) came in after the review and aren't on the page either." | WSC-DDR-001, O3 |
| 2026-10-02 | Pair ID in the field: the scanner creates the pair ID and shows it as a QR code on its screen for the phone to scan, with the same short code in digits as a typed fallback | Amish: "APPROVED: The open decisions from the last wave (TremorTrace to ZeerBox) came in after the review and aren't on the page either." | WSC-DDR-002, question 2 |
| 2026-10-02 | Consented spectra: consented spectra join the WasteWise-ml field dataset on the same terms as field photos: opt-in per scan, co-owned by the pickers' organization, and published under CC BY 4.0 only with that organization's agreement | Amish: "APPROVED: The open decisions from the last wave (TremorTrace to ZeerBox) came in after the review and aren't on the page either." | WSC-DDR-002, question 3 |

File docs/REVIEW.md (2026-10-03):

# Review note: WasteWise Scan

## Session 2026-09-25: /populate to a strong TRL 2 (overnight batch)

### What was done

- `docs/01-problem.md` (WSC-PRB-001 v0.2): problem, prior work (Plastic Scanner, AS7265x, commercial NIR sorters and handhelds, black plastics), users and context, constraints, out of scope, open questions; co-design checklist kept.
- `docs/03-requirements.md` (WSC-REQ-001 v0.2): 14 measurable requirements (R1 to R14) with targets, concept status and planned verification; assumptions.
- `docs/02-concept.md` (WSC-PRC-001 v0.2): key sensor finding, how it works, numbered components, first-order numbers, design choices, safety, open questions.
- `cad/src/concept_media.py`: massing model of the handheld (shells, display board, LED ring, photodiode, amplifier board, window, shroud, 18650 cell, charger, button, calibration cap and PTFE disc), with a hand and an HDPE crate panel as context parts for scale.
- `media/`: `hero.png`, `concept-blueprint.png`, `.pdf` and `.svg`, `cutaway.png` (optical axis), `exploded.png` (callouts 1 to 13 matching the BOM), `flow.png` (item flow per 100 items, all values estimates), `model.glb` and `viewer.html`.
- `bom/bom.csv`: 15 lines with indicative prices, items 1 to 13 numbered to match the exploded view; `bom/bom-notes.md` with cost groups.
- `README.md`: hero image and links line before "## Problem"; Concept, Key components and Safety updated to the proposed concept.
- `docs/pdf/`: branded PDFs of the three controlled documents.

### Key results (estimates, to be checked at TRL 3)

| Quantity | Estimate | Requirement |
| --- | --- | --- |
| Scan time | about 0.6 s | R2 met |
| Battery life, one 3,000 mAh 18650 | about 17 h at about 0.5 W | R5 met |
| Mass | about 170 g (195 g with cap) | R6 met |
| Size | 160 x 62 x 34 mm plus 18 mm shroud | R6 met |
| Log capacity | 10,000 scans under 1 MB | R9 met |
| Items identified per 100 mixed items | about 78 (12 black, 10 low confidence) | R3 intent |
| Parts cost | about $163 | **R12 not met, 9 % over** |

Requirements not met or not shown:

- **R12 (cost) not met:** about $163 against $150. SWIR LEDs (about $62) and the InGaAs photodiode (about $30) are most of the cost.
- **R1 (resin accuracy) not shown:** plausible from Plastic Scanner prior work, but PE versus PP relies on features near 1,700 nm, at the edge of standard InGaAs.
- **R3, R4 on curved items, R7 sunlight legibility, R10 ruggedness: unverified.**

### Proposed, awaiting Amish

1. **Sensor approach (affects the scaffold's component list, not the pitch).** A: discrete NIR and SWIR LEDs with an InGaAs photodiode (covers the polymer bands). B: AS7265x only, as scaffolded (about 410 to 940 nm, misses the main bands, unlikely to meet R1). C: A plus AS7265x for color (about $70 more). Recommendation: A. The pitch still reads true ("low-cost multispectral sensor", "about a second"), so `project.yaml` pitch and problem are unchanged. Decided by Amish, 2026-09-25: go with recommendation. (WSC-DDR-001 D1)
2. **Budget.** (a) Raise `budget_usd` to $175; (b) cut to six bands (drop 1,050 and 1,300 nm, saving about $18, to about $145) at some accuracy risk; (c) keep $150 as a volume target and accept about $163 for the prototype. Recommendation: (c) for now, then (b) if the band study at TRL 3 shows six bands suffice. `budget_usd` is unchanged. Decided by Amish, 2026-09-25: go with recommendation. (WSC-DDR-001 D2)
3. Controller: LilyGO T-Display-S3-class board (no custom PCB) rather than a bare ESP32-S3 with a separate display. Decided by Amish, 2026-09-25: go with recommendation. (D3)
4. Band set: 850, 940, 1,050, 1,200, 1,300, 1,450, 1,550 and 1,650 nm, to be confirmed on reference spectra. Decided by Amish, 2026-09-25: go with recommendation. (D4)
5. Classifier: linear discriminant analysis or a small decision tree on the device first; share labeled data with Plastic Scanner and WasteWise-ml where licenses allow. Decided by Amish, 2026-09-25: go with recommendation. (D5)
6. White PTFE reference in the storage cap as the calibration method. Decided by Amish, 2026-09-25: go with recommendation. (D6)
7. One protected 18650 cell rather than a flat LiPo pouch. Decided by Amish, 2026-09-25: go with recommendation. (D7)
8. First partner and region for co-design and the first price table. No recommendation; still proposed, awaiting Amish.

### Safety concerns

- Misuse on hazardous, medical or chemical waste: the documents say the scanner must never be used to judge safety; keep this in any user-facing material and on the device's start screen.
- 18650 lithium-ion cell (about 11 Wh) used outdoors in heat: protected cell, no charging above 45 °C or in direct sun.
- Invisible SWIR LEDs: low power and short pulses, estimated IEC 62471 exempt group; confirm from datasheets.
- Wrong results can cost users money or contaminate bales: the design prefers "unknown" to a guess.

### Problems and notes

- **Sources were not checked live.** Web search and page fetches were unavailable in this session (search budget exhausted; fetches needed approval), so the inline citations in WSC-PRB-001 and WSC-PRC-001 were written from known references (Lau et al. 2020; Neo et al. 2023; Plastic Scanner; SparkFun AS7265x board; trinamiX; WRAP; WIEGO; ASTM D7611). Check each link and figure before release, especially the 58 % statistic, the trinamiX wavelength range and the ASTM URL.
- SWIR LED prices are the least certain number in the BOM.
- The legacy `cad/src/model.py` placeholder is untouched (TRL 3 work).
- The sibling repos WasteWise-ml and ReflowEconomy were read for context and not modified. The shared scan record format (R13) needs a joint note with WasteWise-ml.
- SwapCell is not used; a handheld does not need a 48 V pack.

### Recommended next step

Review this note and the media, then decide items 1 and 2. If approved, run `/advance-trl3` to select the band set on published reference spectra, estimate signal-to-noise and stray light, confirm the power and eye-safety numbers by calculation, and produce the parametric model and drawing sheet.

## Session 2026-09-25: TRL 3

Amish approved all TRL 2 recommendations on 2026-09-25 ("proceed with all of your recommendations across all batches. Make sure we don't proceed to TRL 4 on any of them."). This session advanced WasteWise Scan to TRL 3 and stopped there.

### What was done

- `docs/decisions/0001-trl2-review-decisions.md` (WSC-DDR-001 v0.1): D1 to D7 recorded as "Decided by Amish, 2026-09-25: go with recommendation"; O1 to O4 left open.
- `docs/decisions/0002-scan-record-format.md` (WSC-DDR-002 v0.1): proposed shared scan record for joint review with WasteWise-ml (field list, CSV and JSON Lines export, 64-byte on-device record). Written in this repo only; WasteWise-ml was read, not modified.
- `docs/01-problem.md`, `docs/02-concept.md`, `docs/03-requirements.md` revised to v0.3: cost constraint and R12 redefined per D2, design choices no longer "proposed", numbers replaced by WSC-CAL-001 values, citations corrected.
- `docs/04-calcs/01-sizing.md` (WSC-CAL-001 v0.1) and `docs/04-calcs/sizing.py`: mass, band coverage, signal and noise, window crosstalk, sunlight, timing, power, logging, eye safety, display contrast, drop and drift, cost; a status for every requirement. The script imports the model and reads the BOM and budget.
- `cad/src/model.py`: parametric build123d model (shells, shroud, window, LED holder with eight tilted LEDs, photodiode and baffle, amplifier board, display board, cell and cradle, button, calibration cap) exporting `cad/step/wastewise-scan-{assembly,top-shell,bottom-shell,shroud,led-holder,cal-cap}.step` and matching STL files for the printed parts.
- `cad/src/sheets.py` and `cad/drawings/WSC-DWG-001.{svg,pdf,png}`: general arrangement at Rev P1 (top and front views at 1:1, section A-A on the optical axis at 2:1, isometric, interface notes), marked "CONCEPT, NOT FOR FABRICATION" and "PRELIMINARY, NOT FOR FABRICATION". The concept sheet stays WSC-DWG-010, so DWG-001 was free.
- `bom/bom.csv`: 15 lines, all priced with a supplier or supplier type; item 5 now specifies the 47 kΩ gain. `bom/bom-notes.md` updated. Total $163.00 against `budget_usd` $150 (volume target).
- `cad/src/concept_media.py` now builds from `model.py`; all media re-rendered and checked (hero, blueprint, cutaway, exploded, flow, GLB and viewer). No `_views` folders remain.
- `project.yaml`: `trl: 3`, `trl_target: 3`, `trl_evidence` lists the docs, DDRs, CAL note and script, model, STEP and STL, drawing and BOM. Pitch and problem unchanged (REVIEW item 1 recommended no change). `README.md` matches.

### Requirements at TRL 3 (WSC-CAL-001, Table 2)

Two not met, two at risk, two not verifiable at TRL 3, eight met.

| Status | Requirements |
| --- | --- |
| Not met | **R4** (sunlight through clear or translucent items reaches the detector at about 900 times the weakest band signal; a 1 % change in ambient per 10 ms from hand movement leaves about 7.5 mV of error against 1.14 mV of signal; opaque items are fine at 0.13 %); **R7** (about 1.6:1 display contrast in 100 klx sun against about 3:1 needed; 5.2:1 shaded) |
| At risk | R1 (1,650 nm band clipped by the InGaAs cutoff: centroid about 1,628 nm, 31 % of its signal at 1,650 nm or above; PE versus PP unproven); R13 (record format drafted, not agreed) |
| Not verifiable at TRL 3 | R3 (wrong-result rate needs item data; black items fall well below the threshold); R10 (drop, IP54, temperature; corner drop about 1,200 g, cell cradle needs about 550 N) |
| Met | R2 (0.33 s), R5 (22.1 h), R6 (202 g, 222 g with cap), R8, R9 (about 131,000 scans), R11, R12 ($163.00 prototype), R14 (3.9 W/m² at 200 mm) |

Key numbers: signal-to-noise ratio 450 or more in shade on every band; 0.39 W average draw; 42 mJ of LED energy per scan; window crosstalk of the same order as the signal.

Changes forced by the calculations: transimpedance gain from 1 MΩ to 47 kΩ (sunlight through clear items would saturate 1 MΩ at about 23 V); each band reading between two dark readings; a short baffle tube around the photodiode. Mass rose from about 170 g to 202 g (shells from model volumes); scan time fell from about 0.6 s to 0.33 s; battery life rose from about 17 h to 22 h.

### Decisions recorded

D1 to D7 in WSC-DDR-001: discrete LEDs with an InGaAs photodiode (sensor option A); budget option (c), `budget_usd` kept at $150 as the volume target with about $163 accepted for the prototype and R12 redefined (six bands only if a band study shows they suffice; not yet shown, so eight bands stay); T-Display-S3 class controller; eight-band set; LDA or small decision tree classifier with shared data; PTFE white reference in the cap; one protected 18650 cell. The SwapCell interface v0.3 items and shared-pack pricing do not apply: WasteWise Scan uses no SwapCell pack.

### Proposed, awaiting Amish

1. **First partner and region (O1).** No recommendation; partners are picked per area later.
2. **Who the $150 volume target is for (O2).** No recommendation.
3. **Extended InGaAs band for PE versus PP (O3).** No recommendation yet; the next step is a band study on published reference spectra.
4. **Shared scan record (O4, WSC-DDR-002).** Recommendation: one shared record with a `pair_id` join; needs a joint review with the WasteWise-ml side. Decided by Amish, 2026-09-25: go with recommendation. (WSC-DDR-003 D12; WasteWise-ml adoption is a cross-repo action)
5. **Clear items in sun (R4, new).** Options: (a) modulate the LEDs at about 2 kHz and demodulate synchronously, which rejects ambient changes but needs a faster ADC or an analog demodulator (a few dollars more); (b) instruct users to back clear items with the calibration cap or scan them in shade; (c) restate R4 to cover opaque items only. Recommendation: (b) for the first prototype and (a) studied on paper before any build; (c) only if (a) fails. This changes the R4 target or the user workflow, so it is Amish's. Decided by Amish, 2026-09-25: go with recommendation. (WSC-DDR-003 D8, D9)
6. **Display in direct sun (R7, new).** Options: (a) a printed visor over the display (about 5.2:1 when shaded, negligible cost); (b) a sunlight-readable reflective display such as a memory LCD (about $20 to $40 more, over budget); (c) restate R7 to "legible when shaded by the hand or visor". Recommendation: (a), keeping large color and icon cues. Decided by Amish, 2026-09-25: go with recommendation. (WSC-DDR-003 D10)
7. **Window crosstalk (new).** Options: (a) an open-air reading in the calibration routine to subtract the crosstalk offset (firmware only); (b) extend the baffle through the glass with separate LED and detector windows (mechanical change); (c) an anti-reflection coated window (cost). Recommendation: (a) now, and (b) if the offset proves unstable with window dirt. Decided by Amish, 2026-09-25: go with recommendation. (WSC-DDR-003 D11)

### Safety concerns

- Misuse on hazardous, medical or chemical waste: the scanner identifies resin only; keep this on the start screen and in all user material.
- 18650 lithium-ion cell (about 11 Wh) outdoors in heat, and about 550 N on the cell in a corner drop: protected cell, a firm cradle, no charging above 45 °C or in direct sun.
- Invisible SWIR LEDs: exempt by a wide margin in normal use (3.9 W/m² at 200 mm), but a stuck LED at the shroud rim could exceed 100 W/m² over long exposures; a hardware on-time limit is required.
- Wrong results can cost users money or contaminate bales, especially on clear items in sun (R4): the design prefers "unknown" to a guess.

### Other notes

- **Citations checked** with web search and fetch in this session: Lau et al. 2020 58 % figure confirmed through the ISWA report that cites it (the primary text was not readable); Neo et al. is 2022, not 2023 (corrected); the WIEGO page does not say waste pickers are "among the lowest-paid", so the sentence was reworded to what the page says; the ASTM link now points to the store page and the title was confirmed; the WRAP link returned 404 and was replaced by a WRAP page confirming that carbon black prevents NIR sorting; the trinamiX 1,450 to 2,450 nm range was confirmed from a fact sheet (its price level is still an estimate); Plastic Scanner's LED range, InGaAs detector and TU Delft origin were confirmed. The polymer band positions (1,150 to 1,250 and 1,650 to 1,750 nm) were not confirmed from Neo et al., which is paywalled; they remain to be checked against a reference spectrum source.
- LED powers, detector responsivity, display brightness and item reflectances are assumptions; they drive R1, R4 and R7.
- No existing TRL 4 material was found: `build-log/` holds only its README, and `electronics/` and `firmware/` are empty. Nothing was added to them.

### Recommended next step

Decide items 5 to 7 above, and name a partner and region when ready. Then a paper-only follow-up within TRL 3: a band study on published reference spectra (R1, O3, and whether six bands suffice) and the joint review of WSC-DDR-002 with WasteWise-ml. **TRL 4 is on hold by Amish's instruction**, and no TRL 4 work was started. For reference only, TRL 4 would need: measured LED spectra and powers and the photodiode's responsivity curve; a lab test article of the optical head scanning labeled resin chips, indoors and in sun; a display legibility check outdoors; a drop and spray check of printed shells; a test report (TST, `environment: lab`) and build log entries.

## Session 2026-09-25: recommendations accepted

On 2026-09-25 Amish wrote: "i accept all your recommendations, go with them across all repos." Every open item that carried a recommendation is now "Decided by Amish, 2026-09-25: go with recommendation". The record is `docs/decisions/0003-recommendations-accepted.md` (WSC-DDR-003 v0.1). It is numbered 0003, not 0002, because WSC-DDR-002 was already the shared scan record.

### Decisions applied and what changed

| # | Decision | Before | After |
| --- | --- | --- | --- |
| D8 | Clear items in sun: back them with the cap or scan in shade; LED modulation checked on paper | R4 not met; error 6.6 times the 1,650 nm signal on a clear item in sun | R4 met by estimate: 0.36 % of signal on backed clear items, 0.13 % on opaque items; firmware prompt "shade or back with cap" when the dark level exceeds 0.71 times the weakest band reading. Modulation at 2 kHz still leaves 23 % on an unbacked clear item, so it does not replace the backing step |
| D9 | Calibration cap printed in black PETG so it can back clear items | White-reference cap only | BOM item 12 respecified, cost unchanged; safety note on backing sharp items added |
| D10 | Clip-on sun hood over the display | R7 not met, 1.6:1 in direct sun; mass 202 g; parts $163.00 | R7 at risk: 5.2:1 where the hood shades the screen (fully shaded with the sun 50° or more off the normal on a side, 67° on the head end); 1.6:1 with the sun near the normal or over the open side. Mass 209 g (229 g with cap); parts $164.00; new BOM item 14 at $1.00 |
| D11 | Open-air crosstalk reading in the calibration routine; extended baffle if unstable | Crosstalk about equal to the signal, not handled | Offset subtracted at each calibration; WSC-CAL-001 C7 shows it must stay within 0.5 % of itself, so the extended baffle is probably needed (proof needs measurement, TRL 4) |
| D12 | One shared scan record with a `pair_id` join (WSC-DDR-002 option 1) | Proposed | Decided for WasteWise Scan; R13 stays at risk until WasteWise-ml adopts it |

Budget: `budget_usd` stays $150 (volume target, WSC-DDR-001 D2). The accepted prototype figure moves from about $163 to about $164 with the hood; R12 text updated.

Files changed: WSC-PRC-001 v0.3 to v0.4, WSC-REQ-001 v0.3 to v0.4 (R4, R6, R11, R12 restated; R7 and R13 status), WSC-CAL-001 v0.1 to v0.2 and `docs/04-calcs/sizing.py` (new lines C7, D6 to D8, I3, I4), WSC-DDR-001 v0.1 to v0.2 (O4 decided), WSC-DDR-002 v0.1 to v0.2, new WSC-DDR-003 v0.1; `cad/src/model.py` (sun hood; STEP and STL for it exported), `cad/src/sheets.py` and WSC-DWG-001 Rev P1 to P2; `cad/src/concept_media.py` and all media regenerated (hood is callout 14); `bom/bom.csv` (16 lines) and `bom/bom-notes.md`; `project.yaml` (DDR-003 in `trl_evidence`; pitch, problem and budget unchanged); `README.md` (Concept rationale, Burning platform, Where it could be used, What sparked the idea; budget, concept, components and safety updated). All PDFs re-rendered with the designmolecule.com footer.

The new "What sparked the idea" section traces the design to the Basel Convention plastic waste amendments (May 2019, in effect 1 January 2021), which split clean single-polymer scrap (B3011) from mixed or PVC-containing plastic (Y48). Sources checked by web fetch: UNEP press release, US EPA overview, OECD 2022 press release, World Bank *What a Waste 3.0* page, WIEGO waste pickers page, European Commission packaging page.

### Requirement status (WSC-CAL-001 v0.2)

| Status | Requirements |
| --- | --- |
| Not met | None (R4 and R7 were not met before this session) |
| At risk | R1 (1,650 nm band clipped by the InGaAs cutoff), R7 (hood cannot shade every sun angle), R13 (record not yet adopted by WasteWise-ml) |
| Not verifiable at TRL 3 | R3, R10 |
| Met | R2, R4 (estimate), R5, R6, R8, R9, R11, R12, R14 |

### Still awaiting Amish (no recommendation was made)

1. First partner and region for co-design and the first price table (O1).
2. Who the $150 volume target is for (O2).
3. Extended InGaAs band for PE versus PP (O3); a paper band study on published reference spectra comes first.
4. How `pair_id` is created in the field (WSC-DDR-002, question 2).
5. Whether consented spectra join the WasteWise-ml dataset, and on what terms (WSC-DDR-002, question 3).

### Cross-repo actions

- **WasteWise-ml:** adopt the shared scan record fields and the `pair_id` join of WSC-DDR-002 v0.2 in its own repo (D12). Not edited from here.

### Safety

- New: backing a clear item with the cap puts the hand near the item; sharp, broken or contaminated items are to be scanned in shade instead. Added to WSC-PRC-001 and the README.
- Unchanged: resin only, never a safety judgment; protected 18650 cell; hardware limit on LED on-time.

### TRL 4

TRL 4 remains on hold by Amish's instruction. Decided but on hold: measuring cap opacity and window crosstalk stability, an indoor and sun test of the backing step, an outdoor legibility check of the hood, the extended baffle if needed, and firmware beyond a sketch. `trl: 3` and `trl_target: 3` are unchanged.

## Session 2026-09-26: product appearance model and photoreal renders (pilot)

Amish chose WasteWise Scan as the pilot for product-grade renders on 2026-09-26 and asked that every drawing name the project and its repository.

### What was done

- `cad/src/product_model.py` (new): appearance model for renders only. It adds filleted two-part shells with a parting groove, a TPU grip overmold with ribs, a recessed display with cover glass and a lit screen, the 16 mm scan button with a collar, a slide power switch, a USB-C port, four M3 screw heads, a lanyard tab, the shroud, window, LED ring and photodiode, the internals (18650 cell, cradle, ESP32-S3 board, amplifier and ADC board) and the calibration cap and PTFE disc as accessories. All main dimensions come from `cad/src/model.py`; the design model, BOM and calculation note are unchanged.
- `media/render-hero.png` and `media/render-exploded.png` (new): Blender Cycles renders from `.kit/photoreal.py` in product-studio mode, captioned with the project, the repository and the viewing direction. The README now leads with the hero render.
- `cad/src/sheets.py`: the title names the device ("Handheld near-infrared resin scanner: general arrangement"); each view label states its scale and viewing direction; the isometric line view is replaced by a product render inset (`media/render-hero-plain.png`); the duplicate "PRELIMINARY" line is removed (the concept label stays).
- Kit 1.4.0: every sheet and render names the project and `github.com/BoujeeEnjinia1701/wastewise-scan` (from `repo:` in `project.yaml`).

### Differences between the appearance model and model.py (for review, not yet in the design model)

- Button hole 16.8 mm in the appearance model so the 16 mm cap clears the shell; model.py has 13 mm, which makes the cap overlap the shell. Proposed, awaiting Amish: carry 16.8 mm into model.py.
- USB-C socket block 6 mm long, inside the tail wall; in model.py it overlaps the tail wall. Proposed, awaiting Amish: move it in model.py.
- Screw bosses at (±68, ±20) mm and a shroud mounting flange are appearance details only.

### TRL

Appearance detail only; no fabrication detail, tolerances or TRL 4 work. `trl: 3` and `trl_target: 3` are unchanged. TRL 4 remains on hold.

## Session 2026-09-27: kit 1.5.0 and image quality

- Kit 1.5.0 synced: STANDARDS v1.5 (sections 12 to 15: product renders, storefront images and image quality, public release, authorship and signing), `.kit/cards.py`, `.kit/image_qc.py`, `.kit/release_gate.py`, issue templates, and the `/render-product` and `/release` commands. `CLAUDE.md` now matches `.kit/CLAUDE.md`.
- Every `media/render-*.png` recaptioned from its original render with the new layout: the title, concept label and repository sit in a band above the render and the view note in a band below it, each line wrapped to the image width, so no text overlaps other text or the render or runs off the image. `media/card.png` and `media/social-preview.png` regenerated with the same rules.
- `python .kit/image_qc.py` and `python .kit/release_gate.py` pass. trl stays 3.

## Session 2026-10-02: kit 1.7.0, constructable design and build plan

Amish approved the build plan format on 2026-09-30 and asked for it in every repo, with outstanding decisions kept in a separate design decisions register. This session installed kit 1.7.0 and followed `/build-plan` and STANDARDS section 18 for WasteWise Scan. Nothing was built; `trl: 3` is unchanged.

### What was done

- Kit 1.7.0 installed (`.kit/`, `.claude/commands/`); `CLAUDE.md` now matches `.kit/CLAUDE.md`.
- `cad/src/model.py` made constructable and given `python cad/src/model.py --check`: 312 constructability checks (no overlaps among 25 components, 25 required contacts, 11 clearances), all passing. STEP and STL regenerated in `cad/step/` and `cad/stl/` (new: display frame and cell strap).
- `docs/decisions/0004-design-for-construction.md` (WSC-DDR-004 v0.1, Draft): every change, made under Amish's 2026-09-30 instruction to make the design physically buildable; open for his review.
- `docs/05-build-plan.md` (WSC-BLD-001 v0.1) with pictures from `cad/src/build_plan_media.py`: overview, 9 making sketches (`cad/drawings/WSC-DWG-101` to `109`), 8 joint close-ups, 13 step pictures and a wiring diagram in `docs/05-build-plan/`.
- `docs/06-design-decisions.md` (WSC-DEC-001 v0.1): 7 open decisions, 8 items to confirm when parts are bought, value engineering, and the decisions made.
- WSC-CAL-001 v0.3 and `docs/04-calcs/sizing.py` (masses from the new model, 25 g fixings allowance, new J4 cell strap check, K2 cost against the value-engineering target); WSC-REQ-001 v0.5; WSC-PRC-001 v0.5; `bom/bom.csv` (19 lines) and `bom/bom-notes.md`; WSC-DWG-001 Rev P4 (`cad/src/sheets.py`); concept media regenerated (`media/hero.png`, `concept-blueprint`, `cutaway.png`, `exploded.png` now with callouts 16 to 18, `flow.png`, `model.glb`, `viewer.html`).
- `project.yaml`: `design_state: constructable`; WSC-DDR-004, the build plan, the register and `cad/src/build_plan_media.py` in `trl_evidence`. `README.md`: links line, budget line, "Building the prototype" section with the overview picture.

### Design changes made for construction (WSC-DDR-004)

1. Shells: four M3 screws from below into heat-set inserts; bosses that meet and stop the squeeze; 1.5 mm foam gasket squeezed to 0.6 mm (top shell rim raised 0.6 mm, body still 34 mm); 1.2 mm locating tongue.
2. Window: pinched between the shroud flange lip and the baffle tube (it had no seat).
3. Shroud: 47 mm flange with three M3 screws into the head block (it had no fixing); now a replaceable wear part.
4. Optical head block replaces the floating LED holder: stands on the floor, carries LEDs, photodiode and amplifier board (which also floated); three insert lugs, two board screws.
5. Photodiode seat: a step and 4 mm aperture (the 5.6 mm baffle bore let the 5.4 mm can fall through); detector plane unchanged.
6. Cell: cradle printed with the bottom shell for a 69 mm protected cell (was sized for 65 mm, with no contacts or retention); spring and flat contacts in the end walls; printed strap on two M3 screws (38 MPa, margin 1.3, [J4]); cell moved 6 mm toward the head.
7. USB-C: power board on a printed seat (the socket overlapped the tail wall; noted 2026-09-26).
8. Display board: printed frame with lips and four M3 screws (it had no fixing).
9. Button hole 16.2 mm for a panel-mount 16 mm button with nut (was 13 mm; noted 2026-09-26).
10. Slide power switch added to the model in the right-hand wall (it was only in the BOM).
11. Sun hood: clip legs that snap under ribs on the top shell (it had nothing to clip to); width over the legs 68.4 mm.
12. Calibration cap: 41.6 mm bore that grips the rim, 20 mm tall, 41 mm PTFE disc, so the rim rests on the disc (the cap was loose and the rim never touched the disc).

### Key results and requirements

- Mass 254 g, 274 g with the cap (was 209 g and 229 g). **R6 (250 g) is now not met**, 24 g over with the cap.
- Value-engineering target: USD 150. Estimated cost of the constructable design: USD 167.50 (USD 17.50 over the target; USD 3.50 added for construction).
- Requirement status (WSC-CAL-001 v0.3): 1 not met (R6), 3 at risk (R1, R7, R13), 2 not verifiable at TRL 3 (R3, R10), 7 met; R12 reported against the value-engineering target. Optics, power, timing, sunlight and display results unchanged.

### Proposed, awaiting Amish

1. Accept the design-for-construction changes 1 to 12 (WSC-DDR-004, A2). Recommendation: accept.
2. R6 mass (WSC-DDR-004, A1): (a) 2.0 mm shell walls, about 20 g lighter, drop case checked at TRL 4; (b) count R6 without the cap; (c) accept about 275 g. Recommendation: (a).
3. Still open from earlier records: O1 partner and region, O2 who the USD 150 target is for, O3 extended InGaAs band, and the two WSC-DDR-002 field questions. All are in WSC-DEC-001.

### Safety

- New hazards in the build: a 230 °C iron for heat-set inserts; the build plan safety stops S1 to S6 cover the cell, first power, the LED on-time limit, first charge and scanning real waste.
- Unchanged: resin only, never a safety judgment; protected 18650 cell; hardware limit on LED on-time.

### Stale images (to regenerate on Amish's Mac)

`media/render-hero.png`, `media/render-exploded.png`, `media/render-hero-plain.png` (none are in this cloud copy), `media/card.png` and `media/social-preview.png` are to be made again on Amish's Mac from the render scenes exported on 2026-10-02 (see "Approved follow-ups carried out" below); `cad/src/product_model.py` now takes the hood, ribs, cap and shell walls from `model.py`.

### Recommended next step

Amish reviews WSC-DDR-004 and the register, decides the R6 option, and the photoreal renders are regenerated. TRL 4 (building to this plan) stays on hold.

## Session 2026-10-02: open decisions decided

Amish, 2026-10-02: "APPROVED: The open decisions from the last wave (TremorTrace to ZeerBox) came in after the review and aren't on the page either." This approves the recommendation written for each open decision in the design decisions register (WSC-DEC-001), as he did for the other 555 open decisions ("i approve your recommendations for all 555 open decisions."). trl stays 3; no build or test work was done, and the model, BOM quantities and prices, and pictures are unchanged.

### Decisions recorded

Seven decisions, all moved to Decisions made in WSC-DEC-001, dated 2026-10-02:

1. Design for construction accepted: the changes P1 to P12 of WSC-DDR-004, as made.
2. Mass (R6): 2.0 mm shell walls, keeping the bosses and ribs, with the drop case checked at TRL 4; R6 stays not met (about 254 g with the cap, 4 g over) until the first prototype is weighed, and the cap stays counted because it is carried for backing clear items.
3. First partner and region: a member-owned waste picker cooperative that already sells sorted plastics to scrap buyers; the first candidate to approach is SWaCH in Pune, India, the partner chosen for WasteWise-ml, with Pune scrap prices as the first price table.
4. Value-engineering target: the USD 150 value-engineering target is the price a cooperative pays for a shared scanner, not an individual picker.
5. Extended InGaAs band: eight bands for the prototype; the paper band study on published reference spectra comes first, and the extended InGaAs band is added only if that study shows PE and PP cannot be told apart to R1 with eight.
6. Pair ID in the field: the scanner creates the pair ID and shows it as a QR code on its screen for the phone to scan, with the same short code in digits as a typed fallback.
7. Consented spectra: consented spectra join the WasteWise-ml field dataset on the same terms as field photos: opt-in per scan, co-owned by the pickers' organization, and published under CC BY 4.0 only with that organization's agreement.

### Documents changed

- `docs/06-design-decisions.md` (WSC-DEC-001 v0.2): open decisions moved to Decisions made.
- `docs/decisions/0004-design-for-construction.md` (WSC-DDR-004 v0.2): acceptance recorded in the status line; A1 and A2 decided (record stays Draft).
- `docs/decisions/0001-trl2-review-decisions.md` (WSC-DDR-001 v0.3): O1 to O3 recorded as decided.
- `docs/decisions/0002-scan-record-format.md` (WSC-DDR-002 v0.3): field questions 2 and 3 recorded as decided.
- `docs/decisions/0003-recommendations-accepted.md` (WSC-DDR-003 v0.2): open items recorded as decided.
- `docs/01-problem.md` (WSC-PRB-001 v0.4): partner, region and price-target questions answered.
- `docs/02-concept.md` (WSC-PRC-001 v0.6): open questions and the PE versus PP note answered.
- `docs/03-requirements.md` (WSC-REQ-001 v0.6): R6 and R13 notes record the decisions; no status changed.

### Follow-up actions to carry approved decisions into the design

1. Decision 2 (model): Set both shell walls to 2.0 mm in the model, keeping the bosses, ribs and tongue, rerun the constructability checks and regenerate STEP and STL.
2. Decision 2 (drawings): Revise WSC-DWG-001 and the making sketches of both shells for the 2.0 mm walls.
3. Decision 2 (calculations): Recompute the shell masses and R6 in WSC-CAL-001 (expected about 234 g, 254 g with the cap) and note the drop case R10 for TRL 4.
4. Decision 2 (pictures): Regenerate the build plan pictures of the shells if the wall change is visible.
5. Decision 5 (calculations): Run the paper band study on published PE and PP reference spectra and report whether eight bands meet R1.
6. Decision 6 (docs): Add the QR pair ID screen and its digit fallback to the firmware sketch notes and the WSC-DDR-002 record fields.
7. Decisions 3, 4 and 7 (docs): Approach SWaCH in Pune, jointly with WasteWise-ml, for the price table, the cooperative price and the consent terms for spectra.

### Points found in the review

- Option (a) for R6 saves about 20 g, which leaves the scanner at about 254 g with the cap, still 4 g over 250 g; the register's recommendation implied (a) would meet R6 but it does not on its own.
- WSC-DDR-004's status line says 'proposed' while the record is Draft; the acceptance should be recorded with the record kept Draft.

## Session 2026-10-02: approved follow-ups carried out

Amish approved on 2026-10-02 that every follow-up action from the open-decision sign-off be carried out. `trl: 3` is unchanged; no build or test work was done.

### Follow-ups

1. Done. Decision 2, model: both shell walls 2.0 mm in `cad/src/model.py`; bosses, ribs, tongue kept; two new checks (wall at least 1.6 mm, tongue fits inside it), 314 constructability checks, 0 failed; STEP and STL regenerated in `cad/step/` and `cad/stl/`.
2. Done. Decision 2, drawings: WSC-DWG-001 Rev P5 (revision row, mass 238 g and 258 g with the cap, section callouts moved clear of the longer revision table); making sketches WSC-DWG-101 to 109 regenerated (101 and 102 name 2.0 mm walls and five perimeters; 105 shows the 12 mm frame).
3. Done. Decision 2, calculations: WSC-CAL-001 v0.4 and `sizing.py`. Shell masses 42 g and 47 g (were 51 g and 56 g); scanner 238 g, 258 g with the cap. R6 stays **not met**, 8 g over, not the 4 g the decision expected: the shells saved 17 g, not about 20 g, and the head block, frame and strap gained about 1 g. Drop energy 2.8 J; the cell load (about 550 N) is unchanged, and the thinner shell corners are noted for the drop test at TRL 4 (R10, not verifiable at TRL 3).
4. Done. Decision 2, pictures: overview, 8 joint pictures and 13 step pictures regenerated from the model; concept media regenerated (`media/hero.png`, concept blueprint, cutaway, exploded, flow, `model.glb`, `viewer.html`).
5. Done. Decision 5, band study: `sizing.py` B4 to B7 and WSC-CAL-001 section B. Reference spectra are built from published near-infrared band positions with approximate depths (not digitized spectra), so this is an indication only. Eight bands: 89.5 % correct on five resins, PE against PP 93 %; without the 1,650 nm band 72 %; six bands 88 %. At 1.0 % band scatter eight bands reach 96.7 %. Result: eight bands do not meet 95 % at the assumed scatter, and the study cannot show they never will. The decision adds the extended InGaAs band only if the study shows PE and PP cannot be told apart, which is not shown either way, so it is **not added**.
6. Done. Decision 6, docs: WSC-DDR-002 v0.4 has the QR pair ID screen and its digit fallback (nine digits, QR text, screen size check, `pair_via` field). The repo has no firmware sketch (TRL cap), so the firmware notes live in that record.
7. Not done: decisions 3, 4 and 7, approach SWaCH in Pune with WasteWise-ml for the price table, cooperative price and consent terms; this is outreach by Amish.

### Other changes

- BOM: lines 1 and 10 respecified (2.0 mm walls, about 33 cm3 and 37 cm3, about 42 g and 47 g); prices unchanged at USD 3.00 and USD 5.00 because filament (about USD 1 a shell at about USD 25 per kg) is a small part of each line. Total USD 167.50.
- Value-engineering target: USD 150. Estimated cost of the constructable design: USD 167.50 (USD 17.50 over the target). `budget_usd` unchanged.
- Requirement status changes: none (R6 still not met at 258 g with the cap; R1 still at risk).
- Appearance model (`cad/src/product_model.py`): it already took walls from `model.py`; added the missing `TITLE` and `RENDER_VIEWS` (hero, exploded, detail), the hood clip ribs, and a clay hand for scale in the hero view. Render scenes exported to `/home/claude/renders/wastewise-scan` (hero, exploded, detail, with `wastewise-scan__jobs.json`). Photoreal renders, `media/card.png` and `media/social-preview.png` are for Amish's Mac.

### Proposed, awaiting Amish

- Extended InGaAs band now or after the first labeled item set (WSC-DEC-001, open decision 1). Recommendation: after the item set.
- R6 remains 8 g over. Options if it matters before the prototype is weighed: count R6 without the cap (238 g) or thin the display frame and head block; neither is done.

### Cross-repo actions

- WasteWise-ml: adopt the QR pair ID (nine digits, `WWS1-<digits>-<device_id>` text, `pair_via` field) and the consented spectra terms in WSC-DDR-002; WasteWise-ml and SWaCH outreach is Amish's.

### Documents changed

WSC-CAL-001 v0.4, WSC-REQ-001 v0.7, WSC-PRC-001 v0.7, WSC-DDR-001 v0.4, WSC-DDR-002 v0.4, WSC-DDR-004 v0.3, WSC-DEC-001 v0.3, WSC-BLD-001 v0.2, README, `bom/bom.csv`, `bom/bom-notes.md`, WSC-DWG-001 Rev P5.

## 2026-10-02: photoreal renders redone on the constructable design

Rendered with Blender Cycles on Amish's Mac from the updated appearance model; captioned with `.kit/photo_caption.py`; `media/card.png` and `media/social-preview.png` regenerated with `.kit/cards.py`. Views: hero, exploded, detail. image_qc passes. Appearance deviations are those logged above as proposed, awaiting Amish.

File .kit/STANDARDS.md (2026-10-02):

---
doc_id: OHP-STD-001
title: Documentation and drawing standard
project: Open Hardware Portfolio
doc_type: Standard
version: "1.7"
status: Released
date: 2026-09-30
author: Amish Chadha
license: CC-BY-SA-4.0
revisions:
  - version: "1.0"
    date: 2026-09-24
    author: Amish Chadha
    change: First release of the standard
  - version: "1.1"
    date: 2026-09-24
    author: Amish Chadha
    change: Adopt Technology Readiness Levels (section 9) for project maturity
  - version: "1.2"
    date: 2026-09-24
    author: Amish Chadha
    change: Portfolio phase cap (section 10), concept media standard (section 11), CLAUDE.md guardrails
  - version: "1.3"
    date: 2026-09-24
    author: Amish Chadha
    change: Scale figure, interactive 3D viewer and flow diagrams added to concept media; session slash commands
  - version: "1.4"
    date: 2026-09-26
    author: Amish Chadha
    change: Every sheet and render names the project and its GitHub repository; overall dimensions, ISO centre lines and 300 dpi PNG on sheets; titles name the device and view labels state the viewing direction; optional photoreal renders with Blender
  - version: "1.5"
    date: 2026-09-27
    author: Amish Chadha
    change: Product renders (section 12), storefront images and image quality check (section 13), public release and release gate (section 14), authorship, citation and commit signing (section 15)
  - version: "1.6"
    date: 2026-09-29
    author: Amish Chadha
    change: Licensing metadata with REUSE (section 16), Zenodo DOI and Software Heritage archiving (section 17), release gate checks REUSE and a single CITATION.cff license, archive.py
  - version: "1.7"
    date: 2026-09-30
    author: Amish Chadha
    change: Concept and constructable design states; design decisions register (DEC) kept apart from the build plan; prototype build plan (BLD, section 18) with pictures by component is required TRL 3 evidence; every repo targets TRL 3 during the populate phase; build_views.py; /to-trl3 and /build-plan commands
---

# Documentation and drawing standard

Every project in the portfolio uses this standard, so that each precis, write-up and sketch looks the same and carries its own version history. The standard ships as a kit in each repo's `.kit/` folder. The kit version is in `.kit/KIT_VERSION`.

## 1. Document types and IDs

Every controlled document has a unique ID in the form `PRJ-TYP-NNN`.

- `PRJ` is the three-letter project code listed in section 7.
- `TYP` is the document type code from the table below.
- `NNN` is a sequence number within that project and type, starting at 001.

| Code | Type | Typical file |
| --- | --- | --- |
| PRC | Design precis | `docs/02-concept.md` |
| PRB | Problem statement | `docs/01-problem.md` |
| REQ | Requirements | `docs/03-requirements.md` |
| CAL | Calculation or sizing note | `docs/04-calcs/*.md` |
| DDR | Design decision record | `docs/decisions/*.md` |
| BOM | Bill of materials | `bom/bom.csv` |
| DWG | Drawing or sketch sheet | `cad/drawings/*.svg` |
| BLD | Prototype build plan (section 18) | `docs/05-build-plan.md` |
| DEC | Design decisions register (section 18) | `docs/06-design-decisions.md` |
| TST | Test plan or test report (front matter adds `environment: lab` or `relevant`) | `docs/05-tests/*.md` |

Example: `TBK-PRC-001` is the ThermaBrick design precis.

## 2. Revision scheme

| Artifact | While in draft | When released | Change after release |
| --- | --- | --- | --- |
| Documents | 0.1, 0.2, 0.3 ... | 1.0 | 1.1 for minor edits, 2.0 for a design change |
| Drawings | Rev P1, P2 ... (preliminary) | Rev A | Rev B, C ... |

- Every change to a controlled document adds a row to its revision history before the commit.
- The `version` field in front matter always equals the newest row in `revisions`. The renderer rejects a document where they differ.
- Status is one of `Draft`, `In review`, `Released` or `Superseded`. Draft and In review documents print with a status band on every page.
- Every release is tagged in Git as `<doc_id>/v<version>`, for example `TBK-PRC-001/v1.0`. Drawings are tagged `TBK-DWG-001/revA`.
- Git history is the full audit trail. The in-document revision table is the human-readable summary.

## 3. Document front matter

Every Markdown document under version control starts with this block:

```yaml
---
doc_id: TBK-PRC-001
title: ThermaBrick design precis
project: ThermaBrick
doc_type: Precis
version: "0.1"
status: Draft
date: 2026-09-24
author: Amish Chadha
license: CERN-OHL-S-2.0
revisions:
  - version: "0.1"
    date: 2026-09-24
    author: Amish Chadha
    change: Initial draft
---
```

Quote version numbers so YAML keeps `1.0` as text instead of turning it into a number. List revisions newest last.

## 4. Writing style

- Chicago Manual of Style.
- No em dashes. Restructure the sentence instead.
- Lead each section with its conclusion, then support it.
- SI units throughout, in the form `12 kW`, `450 °C`, `3.2 m`. Imperial values may follow in parentheses.
- Number every figure and table ("Figure 2", "Table 1") and give each a caption.
- State every assumption in the calculation that depends on it.
- Put safety notes in a blockquote starting with **Safety:**.

## 5. Visual identity

| Element | Specification |
| --- | --- |
| Typeface | IBM Plex Sans for text, IBM Plex Mono for code and values (SIL Open Font License, bundled in `.kit/fonts`) |
| Ink | `#111827` |
| Secondary text | `#4B5563` |
| Rules and grid | `#D1D5DB` |
| Accent (one only) | `#0F766E` teal |
| Document page | US Letter, 20 mm margins |
| Drawing sheet | ANSI B landscape (431.8 x 279.4 mm) |
| Footer | Document ID, version, status, license and designmolecule.com on every page |

## 6. Drawing and sketch conventions

- Units are millimeters unless the title block says otherwise.
- Third-angle projection, marked with the symbol in the title block.
- Line weights: visible outlines 0.5 mm, hidden lines 0.25 mm dashed, center lines 0.18 mm chain.
- The title block contains the project, title, drawing number, revision, scale, units, projection, sheet, author, date, material or notes, and license.
- Every sheet and every render names the project and its GitHub repository (from `repo:` in `project.yaml`), at the top of the sheet and in the title block, so a printed or forwarded sheet is never anonymous.
- The drawing title names the device, not only the drawing type (for example "Handheld near-infrared resin scanner: general arrangement").
- Every view label states its scale and viewing direction (for example "Scale 1:1; side elevation looking along +Y"), and every isometric or render states where it is seen from.
- Orthographic views generated with `add_ortho` carry overall dimensions (length and depth on the top view, height on the front view) and ISO 128 centre lines on cylinders; hidden lines are dashed. Tolerances are not shown before TRL 4.
- Sheets are exported as SVG, PDF and a 300 dpi PNG.
- The revision table in the top right of the sheet lists every revision.
- Concept sketches use the same sheet and title block and carry the label "CONCEPT, NOT FOR FABRICATION".
- Geometry comes from `cad/src/*.py` (build123d). Sheets are generated by `.kit/drawing.py` and never edited by hand.

## 7. Project codes

| Code | Project | Code | Project | Code | Project |
| --- | --- | --- | --- | --- | --- |
| TBK | ThermaBrick | PCF | PicoFlow | HLT | HelioLite |
| CCB | CharCube | DRN | DustRunner | TRT | TremorTrace |
| STC | StepCue | FXH | FlexHand | CPD | ColdPod |
| SCL | SunClave | STR | SteamRoot | GGD | GrainGuard |
| SDL | SeedLine | ZBX | ZeerBox | RMS | RootMesh |
| DWD | DewDrive | SSK | StillStack | PPR | PotPress |
| WWT | WaterWatch | LMF | LumaFlow | FCL | FieldCell |
| CNP | ConePro | CVC | CulvertCrawl | EGD | EmberGuard |
| SNF | SnapFrame | CGM | CargoMule | SCM | StepClimber |
| SWC | SwapCell | PLP | PalletPilot | FTK | FlatTrike |
| WWK | WaterWalker | GRR | GrowRider | SSP | SunSpoke |
| SGN | StepGen | PBX | PowerBox | WML | WasteWise-ml |
| WSC | WasteWise Scan | RFE | ReflowEconomy | | |
| OHP | Portfolio-wide | | | | |

## 8. Build and publish

- `python .kit/render.py` checks every controlled document and renders it to `docs/pdf/<doc_id>_v<version>.pdf`.
- `python .kit/drawing.py` (called from each project's `cad/src/sheets.py`) builds drawing sheets as SVG and PDF in `cad/drawings/`.
- The GitHub Action in `.github/workflows/docs.yml` runs the checks on every push and attaches PDFs to a GitHub Release whenever a release tag is pushed.
- Public releases follow section 14: `python .kit/release_gate.py` must pass, and the release tag is `v0.<TRL>.0` (for example `v0.3.0` at TRL 3).

## 9. Technology Readiness Level (TRL)

Each project states its maturity as a Technology Readiness Level on the NASA and US DOE 1 to 9 scale. The TRL rates this specific design, not the underlying technology. A sand battery is commercial elsewhere, but a new sand battery design starts at TRL 2 until evidence shows otherwise.

| TRL | Definition | Evidence the repo must contain |
| --- | --- | --- |
| 1 | Basic principles observed | Problem statement (PRB) |
| 2 | Technology concept formulated | Draft precis (PRC) and requirements (REQ) |
| 3 | Analytical or experimental proof of concept | Calculation note (CAL), working build123d model with STEP export, drawing sheet (DWG), priced BOM with every unit cost filled in, prototype build plan (BLD) with pictures, `design_state: constructable` |
| 4 | Components validated in the lab | Test report (TST) with `environment: lab`, build log entries |
| 5 | Validated in a relevant environment | Test report (TST) with `environment: relevant` |
| 6 | System prototype demonstrated in a relevant environment | Precis at version 1.0 or later with status Released, a drawing at a lettered revision (Rev A or later), and a system-level TST with `environment: relevant` |
| 7 to 9 | Operational demonstration through proven in service | Beyond portfolio scope; claim only with a named deployment partner and evidence |

Rules:

- `project.yaml` records `trl` (current level), `trl_target` (the level the current effort aims for) and `trl_evidence` (the files that support the claim).
- `python .kit/render.py --check` fails if the evidence for the claimed TRL is missing. CI runs this check on every push.
- Documentation alone cannot go past TRL 3. TRL 4 and above require hardware and a test report.
- TRL and visibility are independent. A repo can be public at TRL 3 as a documented design ready to build.
- A change of TRL is recorded in the build log with the date and the evidence that justified it.

## 10. Portfolio phase and TRL cap

`.kit/PHASE.yaml` sets the current phase. During the **populate** phase every repo is capped at **TRL 3**: `trl` and `trl_target` may not exceed 3, and the check fails if they do. Every repo targets the cap: `trl_target` must equal 3, so a new repo is taken all the way to TRL 3 (scaffold, populate and advance, see `/to-trl3`). Work that belongs to TRL 4 or later (building or testing hardware, test articles, test plans and reports, build-log entries, purchasing lists, PCB layouts) must not be started. The prototype build plan (BLD, section 18) is TRL 3 paper work and is required. Where it already exists it is kept, flagged in the check output, and not extended. Only Amish changes `PHASE.yaml`.

Every repo carries a `CLAUDE.md` with the working rules for AI sessions: the TRL cap, decision rights (nothing is recorded as decided unless Amish decided it), one step per session, and a mandatory `docs/REVIEW.md` before stopping.

## 11. Concept media

Every repo at TRL 2 or above explains its idea visually. Media are generated from a build123d massing model with `.kit/concept.py`, never drawn by hand, so they stay in step with the design.

| File | Required | Purpose |
| --- | --- | --- |
| `media/hero.png` | TRL 2+ | Shaded isometric render with a 1.75 m person for scale; the website card image |
| `media/concept-blueprint.png` and `.pdf` | TRL 2+ | Blueprint concept sheet: orthographic and isometric views, scale, key figures, title block |
| `media/model.glb` and `media/viewer.html` | TRL 2+ | Interactive 3D viewer (glTF plus model-viewer) for the website |
| `media/cutaway.png` | When the inside matters | Section view showing internal parts |
| `media/exploded.png` | Recommended | Exploded view with numbered callouts matching the BOM |
| `media/flow.png` | When energy or material moves | System, energy or material flow diagram with losses |

Session commands in `.claude/commands/` (`/populate`, `/advance-trl3`, `/rein-in`, `/refresh-media`) carry the standard prompts, so every Claude Code session starts from the same instructions.

At TRL 2 a massing model is enough: correct overall proportions and main components. All concept media carry "CONCEPT, NOT FOR FABRICATION". The check warns when required media are missing at TRL 2 and fails at TRL 3.

## 12. Product renders

Every repo at TRL 3 shows the product as it would look, not only as a massing model.

- `cad/src/product_model.py` is the appearance model. It defines `product_parts()` (named parts with a shape and a material), `TITLE` ("Name: what it is") and `RENDER_VIEWS`. It is for renders only: every main dimension comes from `cad/src/model.py`, never typed in again.
- Where the appearance model departs from `model.py` (a chamfer, a label, a fastener drawn for realism), record the deviation in `docs/REVIEW.md` as "Proposed, awaiting Amish".
- Scale comes from context, not from a floating figure: a hand or forearm for handheld objects, and the posed mannequin (`mannequin()` in `.kit/context_parts.py`: stand, walk, push, ride, sit, reach) for anything a person uses at body scale.
- Renders are made with `.kit/export_views.py` (one scene per view) and `.kit/photoreal.py` (Blender Cycles), then captioned with `.kit/photo_caption.py`. Files are `media/render-<view>.png`; `media/render-hero.png` is required.
- Every caption names the project, the repository and the viewing direction, and carries "CONCEPT, NOT FOR FABRICATION".
- Captions never sit on the render. `.kit/photo_caption.py` adds a header band (title, concept label, repository) above the render and a footer band (view note) below it, wraps every line to the image width, and steps the font down to a floor before adding a line.
- The README opens with `media/render-hero.png`.
- Software-only and scene repositories (no single product) may use a scene render as the hero instead of a product model.

## 13. Storefront images

Two images, both made from `media/render-hero.png` by `python .kit/cards.py .`:

| File | Size | Purpose |
| --- | --- | --- |
| `media/card.png` | 800 x 800 | Square thumbnail for the organization profile page |
| `media/social-preview.png` | 1280 x 640, under 1 MB | GitHub social preview, shown when a repository link is shared |

- The social preview shows the area, name, one-line description, the first sentence of the pitch, the brand line and the repository address. Design Molecule repos read "Design Molecule · open hardware concept, TRL n"; OpenRatio repos read "OpenRatio · research and educational prototype, TRL n".
- GitHub has no API for the social preview. Upload it under the repository's Settings, Social preview, on release day.
- Regenerate both images whenever `render-hero.png` changes.

### Image quality

Every render, card and social preview must be clear and readable. `python .kit/image_qc.py` checks each one, and the release gate blocks on any failure:

| Check | Rule |
| --- | --- |
| Layout | Made by the current `photo_caption.py` or `cards.py`, which store the text layout in the PNG |
| Text inside the image | Every line at least 1.2 % of the image width from each edge; nothing runs off the side |
| No overlap | No line of text touches another line, and no caption text sits on the render |
| Text size | Render captions at least 1.05 % of the image width in pixel height (17 px at 1600 px); social preview text at least 16 px |
| Resolution | Renders at least 1200 px wide; card 800 x 800; social preview 1280 x 640 and under 1 MB |
| Sharpness | The render is not blurred or upscaled (edge sharpness at least 15 on the `image_qc.py` scale) |

Long titles and notes wrap to more lines rather than shrinking below the floor. The social preview shortens the pitch sentence with an ellipsis only if it cannot fit at the smallest size.

## 14. Public release

A repository goes public only when Amish approves it, and only after `python .kit/release_gate.py` passes. The gate checks:

1. `render.py --check` passes (document control, TRL cap, concept media).
2. Storefront: hero render, card, social preview under 1 MB, README leading with the hero, and every image passing the image quality check (section 13).
3. Issue templates in `.github/ISSUE_TEMPLATE/`: question, build report, design suggestion. The build report template restates that the design is a TRL 3 concept, not released for fabrication (OpenRatio: a research and educational prototype, not a medical device).
4. `CITATION.cff` valid, with an author ORCID.
5. License files match `project.yaml`.
6. No em dashes in the repository's own text.
7. BioMedical and OpenRatio repos use soft, non-clinical wording: "research and educational prototype, not a medical device".
8. No secrets anywhere in the history (gitleaks).
9. No links to sibling repositories that are still private.
10. REUSE files present (`REUSE.toml`, `LICENSES/`, `.github/workflows/reuse.yml`) and `reuse lint` passes (section 16).
11. `CITATION.cff` names exactly one license, because Zenodo rejects a list (section 17).

It warns, without blocking, when the README lacks a Safety heading or a "not for fabrication" statement, when `CITATION.cff` has no DOI yet, and when the README lacks the Zenodo DOI, REUSE or Software Heritage badge, so a person can confirm.

On release day, per repository:

- A signed, annotated tag `v0.<TRL>.0` on `main`.
- A GitHub release with short notes (what it is, TRL, status, licenses, how to cite) and a design pack, `<repo>-v0.<TRL>.0-design-pack.zip`, holding `cad/step`, `cad/drawings`, `docs/pdf`, `bom`, README, licenses and `CITATION.cff`.
- Description from the first sentences of `pitch` (350 characters at most), website `https://designmolecule.com` (OpenRatio: `https://openratio.ai`), topics from `project.yaml`.
- Before the first release, the repository is switched on in Zenodo (section 17), so the release is archived and gets a DOI.
- Visibility switched to public last, after the release exists.
- The social preview uploaded and the organization profile updated with the new cards.
- After the release: the concept DOI written to `CITATION.cff` and a Software Heritage save requested (section 17).

The internal working files (`CLAUDE.md`, `.kit/CLAUDE.md`, `.claude/commands/`, `docs/REVIEW.md`) stay public, and open "Proposed, awaiting Amish" items stay visible as open questions (Amish, 2026-09-27).

## 15. Authorship, citation and signing

- Amish Chadha is the author of every design, ORCID 0009-0000-8079-7141. Commits are authored as Amish Chadha <amish@designmolecule.com>.
- `CITATION.cff` lists Amish (with ORCID) first, then any credited contributors; `CONTRIBUTORS.md` and the README Credits section agree with it.
- `CITATION.cff` names one license: the hardware license (CERN-OHL-S-2.0), or the software license in a software-only repository. The full split between hardware and software licenses lives in `REUSE.toml` and the README. Once the repository is archived, `CITATION.cff` carries the concept DOI in `doi:`.
- Work done with Claude carries the trailer `Co-Authored-By: Claude <noreply@anthropic.com>` (with the model name), and the README Credits section says designs are developed with AI assistance.
- Every commit and tag pushed to GitHub is signed with Amish's SSH signing key, so GitHub shows it as Verified. Commits prepared elsewhere are re-signed on Amish's Mac before they are pushed.
- Once a repository is public, its history is never rewritten.

## 16. Licensing metadata (REUSE)

Every file states its copyright and license in a machine-readable way, following the REUSE Specification 3.3 (https://reuse.software). A repository is set up with:

```
python .kit/archive.py reuse
```

This writes three things and adds the REUSE and Software Heritage badges to the README badge line:

- `REUSE.toml`, built from the licenses in `project.yaml`. Everything is under the hardware license by default. Scripts, firmware, notebooks, web viewers, workflows and agent commands are under the software license. `cad/` and `electronics/` stay under the hardware license even where they are written as Python. The bundled IBM Plex fonts are OFL-1.1 (IBM Corp.). Copyright is "<first commit year> Amish Chadha".
- `LICENSES/`, with the full text of each license used (`reuse download`). The root `LICENSE` and `LICENSE-SOFTWARE` files stay for GitHub's license detection.
- `.github/workflows/reuse.yml`, which runs the REUSE check (fsfe/reuse-action) on every push and drives the README badge.

A new kind of file that falls outside these rules gets a new annotation in `REUSE.toml` rather than a header comment. `reuse lint` must pass before every commit that adds files, and the release gate enforces it.

## 17. Archiving and DOI (Zenodo and Software Heritage)

Every public repository is archived twice, so the design stays citable and retrievable if GitHub changes.

Zenodo (a citable DOI for each release):

1. Amish's Zenodo account is linked to GitHub. Before the first release, Amish switches the repository on in Zenodo (Account, GitHub). Only Amish changes Zenodo or GitHub settings.
2. Run `python .kit/archive.py zenodo`: it makes sure `CITATION.cff` names one license and adds the Zenodo DOI badge, which uses the GitHub repository ID and always points at the latest version. Zenodo reads its metadata (title, authors with ORCID, license, keywords) from `CITATION.cff`, and rejects the whole archive when that file lists several licenses.
3. Publish the GitHub release (section 14). Zenodo archives it within minutes and mints two DOIs: a version DOI for that release and a concept DOI that stands for all versions.
4. Check the Zenodo record: title, author and ORCID, license, keywords. If Zenodo shows "Citation metadata load failed", fix `CITATION.cff`, validate it with cffconvert and publish a new patch release (for example `v0.3.2`); a failed release is never re-used.
5. Run `python .kit/archive.py zenodo --doi <concept DOI>` and commit, so GitHub's "Cite this repository" and every future archive carry the concept DOI. Every later release gets its own version DOI automatically; the concept DOI never changes.

Software Heritage (permanent source archive):

1. After the repository is public, request a save at https://archive.softwareheritage.org/save/ (origin type git, the repository URL). Anonymous requests are limited to about ten an hour, so batches are spread out.
2. The Software Heritage badge on the README resolves once the save is accepted and ingested. Later pushes are picked up by its regular crawl.

OpenRatio repositories follow the same steps when Amish approves their release.

## 18. Prototype build plan (BLD) and the constructable design

### Two design states

A design moves through two states, recorded as `design_state` in `project.yaml`:

- **Concept**: the design shows what the product does and that it works on paper (TRL 2 and the calculations of TRL 3). Parts may be simplified shapes that have never been checked for how they are made or how they join.
- **Constructable**: every part can be made with the stated process and material, and every part fits and fastens to the parts next to it. Nothing is left as a shape that cannot be cut, cast, bent, printed, machined or bought.

A repo reaches TRL 3 only when its design is constructable and its build plan shows how. Writing the build plan is how the design is made constructable: when a part cannot be made or cannot fit as modelled, change the model so it can (Amish, 2026-09-30: "fix the design assumptions to match and be physically feasible"), keep what the concept does, and record every change in a decision record "Design for construction" (DDR) and in the plan. Changes that alter what the product does, its pitch or its safety case are proposed, not made.

### What the build plan is

`docs/05-build-plan.md` (`PRJ-BLD-001`) tells a capable maker how to build the first proof-of-concept prototype, in order, component by component, and shows it in pictures. It is written before anything is built, states "Plan, not yet built" under the title and never claims results. Building and testing to it is TRL 4 work.

### Writing rules

- **Plain English.** Say "the steel plate the jack stands on", not a model parameter or variable name. No code identifiers, function names, parameter names or file paths in the body of the plan. Give sizes as numbers with units ("a 62 mm hole, centred 100 mm up from the bottom edge"). The only place file names appear is the closing "Where the numbers come from" list.
- **Pictures first.** Every component and every assembly step has a picture. A reader should be able to build from the pictures, with the words explaining what the pictures cannot show (order, force, tolerance, checks).
- **By component, in build order.** Each component is made and checked before the step that needs it.
- **Cost is not the focus.** One line in the overview may state the parts cost from the BOM; there is no cost or time section.

### Sections, in order

1. **What you are building**: the overview picture (every component pulled apart and numbered in build order) and one short paragraph.
2. **What changed to make it buildable**: a table of each change from the concept (what the concept had, what the constructable design has, why), with a picture where the change is visible. "None" if nothing changed.
3. **Making the components**: one subsection per made component, in build order, each with:
   - its making sketch (three views with overall sizes, a 3D view, where it goes, making notes), `cad/drawings/PRJ-DWG-1NN`;
   - what it is and what it is made from (material, stock size);
   - how to make it, as numbered steps (mark out, cut, drill, bend, weld, cast, print, machine, finish), with the sizes that matter;
   - how it fits the parts next to it: a close-up picture of the joint, which faces touch, what holds them (bolt, weld, pin, clip, glue), the gap or fit needed, and which side goes where;
   - the check before moving on.
   Bought components get a short subsection: what to buy (specification, not brand), and what to do to it (drill, trim, fit).
4. **Putting it together**: numbered assembly steps, each with a step picture (parts already fitted in grey, the part being fitted in colour with an arrow showing the way it goes in), the fasteners, and any hold point.
5. **First checks**: fit, movement, first power or first load, each tied to a requirement ID with a pass criterion. The plan lists them; a TRL 4 test report records them.
6. **Safety stops**: points where work stops (before energising, pressurising, loading, lifting or operating) and what must be true to carry on.
7. **Tools, skills and workspace.**
8. **Where the numbers come from**: the model, drawings, calculation note and BOM, by file name.
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

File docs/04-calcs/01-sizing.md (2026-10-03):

---
doc_id: WSC-CAL-001
title: WasteWise Scan sizing calculations
project: WasteWise Scan
doc_type: Calculation
version: "0.4"
status: Draft
date: '2026-10-02'
author: Amish Chadha
license: CERN-OHL-S-2.0
revisions:
- version: "0.1"
  date: '2026-09-25'
  author: Amish Chadha
  change: First issue for TRL 3 (mass, band coverage, signal and noise, sunlight, timing, power, logging, eye safety, display, drop and drift, cost)
- version: "0.2"
  date: '2026-09-25'
  author: Amish Chadha
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

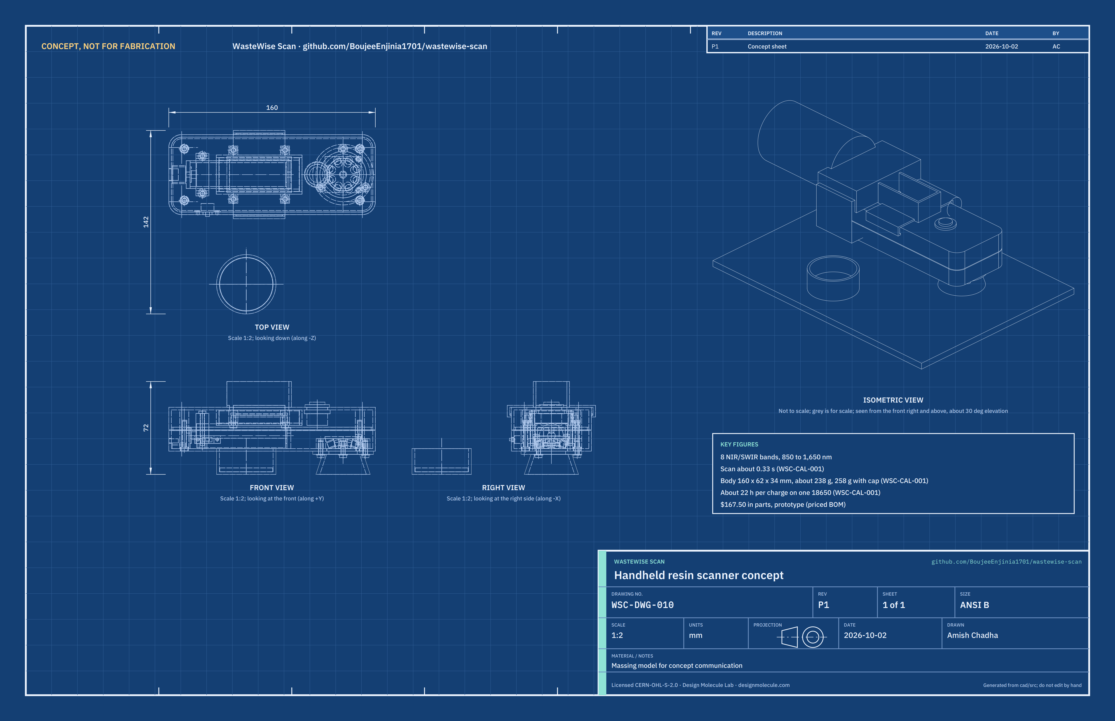
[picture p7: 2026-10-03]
media/concept-blueprint.png

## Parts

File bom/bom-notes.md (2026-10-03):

# BOM notes

Every line of `bom/bom.csv` is priced (TRL 3). Prices are catalog-level estimates with a supplier or supplier type; no quotes have been requested. Items 1 to 14 and 16 to 18 match the numbered callouts in `media/exploded.png`; items 15 and 19 are not shown there. `docs/04-calcs/sizing.py` reads the BOM and prints the total (WSC-CAL-001, K1).

| Group | Items | Cost |
| --- | --- | --- |
| Optics (LEDs and photodiode) | 3, 4 | $92.00 |
| Electronics and power | 2, 5, 8, 9, 11 | $43.00 |
| Housing, window, shroud, hood, calibration and construction parts | 1, 6, 7, 10, 12, 13, 14, 15, 17, 18, 19 | $26.50 |
| Hardware and consumables | 16 | $6.00 |
| **Total** | 1 to 19 | **$167.50** |

Value-engineering target: USD 150 (`budget_usd`, a hypothetical control target, not a limit; Amish, 2026-10-01). Estimated cost of the constructable design: USD 167.50 (USD 17.50 over the target). The SWIR LEDs are the largest and least certain cost. Cost drivers and savings worth trying are in the design decisions register (`docs/06-design-decisions.md`).

Changes for construction (2026-10-02, WSC-DDR-004, open for Amish's review): lines 1, 3, 7, 10 to 14 and 16 respecified; line 9 is now cell contacts and a USB-C board ($3.00, the cradle is printed with the bottom shell); line 10 repriced to $5.00 and line 16 to $6.00; lines 17 (display frame), 18 (cell strap) and 19 (shell gasket) added. Items 17 to 19 are modeled; the exploded view shows 16 (screws), 17 and 18.

Shell walls 2.0 mm (2026-10-02, decision on R6): lines 1 and 10 now print about 33 cm3 (42 g) and 37 cm3 (47 g), together 17 g lighter, and their prices stay at $3.00 and $5.00 because filament is a small share of each line; the total stays $167.50. Scanner mass is 238 g, 258 g with the cap (WSC-CAL-001 A3).

Changes at TRL 3: item 5 specifies a 47 kOhm transimpedance gain (set by the sunlight calculation). On 2026-09-25 (WSC-DDR-003) item 14, the sun hood, was added; the calibration cap (item 12) is now printed in black PETG so it can back clear items in sun; the resin reference chips and the hardware lines moved from 14 and 15 to 15 and 16.

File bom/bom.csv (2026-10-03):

item | qty | spec | supplier | unit_cost_usd | make_buy | notes
1 Top shell | 1 | 3D-printed PETG, display window, 16.2 mm button hole, four shell-screw bosses and four display-frame bosses with M3 heat-set inserts, two clip ribs for the sun hood; 2.0 mm walls; about 33 cm3 | Self (PETG filament from any filament supplier) | 3.00 | make | Material cost only; about 42 g (WSC-CAL-001 A2); price unchanged by the 2.0 mm walls because filament is a small part of the line (about USD 1 of filament at about USD 25 per kg; the rest of the line is print consumables and waste)
2 ESP32-S3 display board | 1 | ESP32-S3, 16 MB flash, 1.9 in 170 x 320 IPS display, on-board Li-ion charger (LilyGO T-Display-S3 class) | LilyGO via electronics distributor or online retailer | 20.00 | buy | Catalog-level price; board chosen by Amish 2026-09-25 (WSC-DDR-001 D3)
3 LED ring (8 bands) | 1 | LEDs at 850, 940, 1050, 1200, 1300, 1450, 1550 and 1650 nm (TO-46 or 5 mm) in a printed PETG optical head block (36 mm, three M3 insert lugs, baffle tube onto the window, photodiode bore), constant-current drivers | Specialist LED distributor (Marktech Optoelectronics or Roithner LaserTechnik type) | 62.00 | buy | Least certain price: SWIR LEDs about $8 to $15 each; 850 and 940 nm about $1 each; holder printed
4 InGaAs photodiode | 1 | InGaAs PIN, 1 mm active area, about 900 to 1700 nm, TO-46 | Photonics distributor (Hamamatsu or Marktech type) | 30.00 | buy | Indicative price; confirm responsivity curve near 1700 nm (WSC-CAL-001 B)
5 Amplifier and ADC board | 1 | Low-noise op-amp transimpedance stage with 47 kOhm feedback, 24-bit ADC (ADS1220 class), LED switches, perfboard | Electronics distributor (Digi-Key or Mouser type) | 10.00 | buy | Gain set by WSC-CAL-001 D2 (was 1 MOhm)
6 Borosilicate window | 1 | 25 mm diameter, 2 mm thick, uncoated | Optics or glass supplier (stock window) | 4.00 | buy | Indicative price; an AR coating would cut crosstalk (WSC-CAL-001 C5) at higher cost
7 Light shroud | 1 | 3D-printed black TPU cone, 18 mm deep, 42 mm rim, 3 mm wall, with a 47 mm x 2.5 mm clamping flange whose 22 mm lip holds the window; three M3 screws and washers; replaceable wear part | Self (TPU filament) | 2.00 | make | Material cost only; flange added for construction (WSC-DDR-004)
8 18650 Li-ion cell | 1 | 3000 mAh, 3.6 V nominal, protected, from a named cell maker | Reputable battery distributor | 8.00 | buy | Avoid unbranded cells; about 47 g
9 Cell contacts and USB-C board | 1 | 18650 spring and flat contact pair with solder tabs (fits the printed cradle in the bottom shell); USB-C 2-pin power breakout board 10 x 12 mm; protection wiring to the board charger | Electronics distributor or online retailer | 3.00 | buy | Cradle is printed with the bottom shell; the cradle and the cell strap must hold the cell against about 550 N on a corner drop (WSC-CAL-001 J2, J4); repriced (WSC-DDR-004)
10 Bottom shell and grip | 1 | 3D-printed PETG, textured grip, window hole, cell cradle with contact end walls, locating tongue, four counterbored shell-screw bosses, two strap bosses, USB-C board seat, switch slot; 2.0 mm walls; about 37 cm3 | Self (PETG filament) | 5.00 | make | Material cost only; cradle, bosses and tongue added for construction (WSC-DDR-004); about 47 g (WSC-CAL-001 A2); price unchanged by the 2.0 mm walls (filament is a small part of the line)
11 Scan button | 1 | Sealed 16 mm panel-mount push button (M16 thread, nut inside), plus a panel slide power switch with two M2 mounting holes 15 mm apart | Electronics distributor | 2.00 | buy | Catalog-level price
12 Calibration cap | 1 | 3D-printed black PETG cap, 46 mm OD x 20 mm, 41.6 mm bore that grips the shroud rim; stores over the shroud with the rim on the PTFE disc; also backs clear items in sun | Self (PETG filament) | 2.00 | make | Material cost only; black so it blocks light through clear items when used as a backing (WSC-DDR-003 D9); resized so the rim rests on the disc (WSC-DDR-004)
13 White PTFE reference disc | 1 | 41 mm disc cut from 3 mm PTFE sheet, sanded matte | Plastics stockist | 5.00 | buy | Not a certified reflectance standard
14 Sun hood | 1 | 3D-printed PETG clip-on hood, walls 20 mm high on both sides and the head end of the display window, open toward the user; two clip legs that snap under ribs on the top shell sides; about 9 cm3 | Self (PETG filament) | 1.00 | make | Material cost only; about 11 g (WSC-CAL-001 A2, I3); decided by Amish 2026-09-25 (WSC-DDR-003 D10); clip legs added (WSC-DDR-004)
15 Resin reference chips | 1 | Set of labeled PET, HDPE, PVC, LDPE, PP and PS pieces from known items | Self (collected items) | 2.00 | make | Not modeled; for checks and training
16 Hardware and consumables | 1 | 4 x M3 x 20 pan head (shell); 3 x M3 x 10 pan head with washers (shroud and head block); 4 x M3 x 8 pan head (display frame); 2 x M3 x 25 low head (cell strap); 2 x M2.5 x 6 (amplifier board); 2 x M2 x 6 with nuts (switch); 13 M3 and 2 M2.5 heat-set inserts; wire, adhesive | Hardware store or electronics distributor | 6.00 | buy | Modeled as screws; inserts are the holes in the bosses; repriced (WSC-DDR-004)
17 Display frame | 1 | 3D-printed PETG frame around the display board, lips under its long edges, four ears for M3 screws into the top shell; 0.5 mm foam tape on the lips | Self (PETG filament) | 1.00 | make | Material cost only; added for construction (WSC-DDR-004)
18 Cell strap | 1 | 3D-printed PETG bridge 10 x 8 mm across the cell, two M3 x 25 screws into inserts in floor bosses | Self (PETG filament) | 0.50 | make | Material cost only; added for construction (WSC-DDR-004); stress check WSC-CAL-001 J4
19 Shell gasket | 1 | Closed-cell EPDM foam tape 2.5 mm wide, 1.5 mm thick, about 0.45 m, squeezed to 0.6 mm between the shells | Hardware store or online retailer | 1.00 | buy | Added for construction (WSC-DDR-004); IP54 still to be shown (R10)

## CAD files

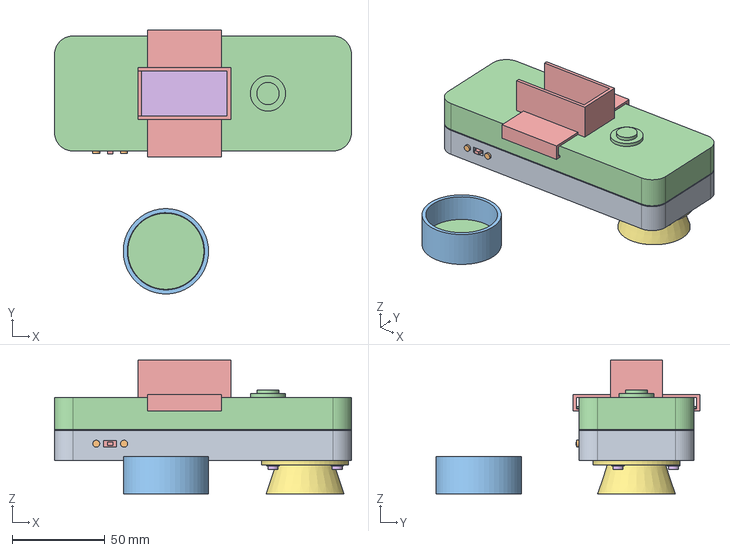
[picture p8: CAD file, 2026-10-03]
cad/step/wastewise-scan-assembly.step
160.0 x 142.2 x 72.0 mm

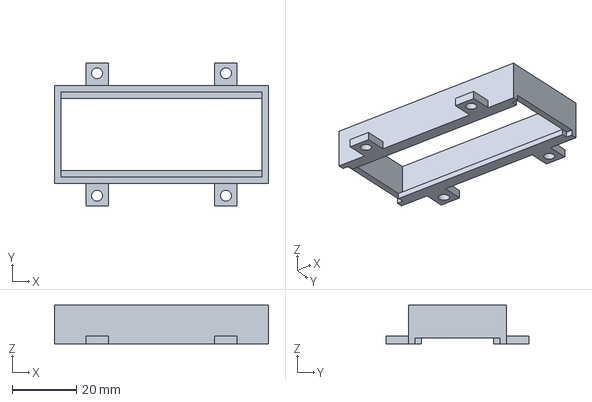
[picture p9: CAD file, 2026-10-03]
cad/step/wastewise-scan-display-frame.step
66.4 x 44.4 x 12.0 mm

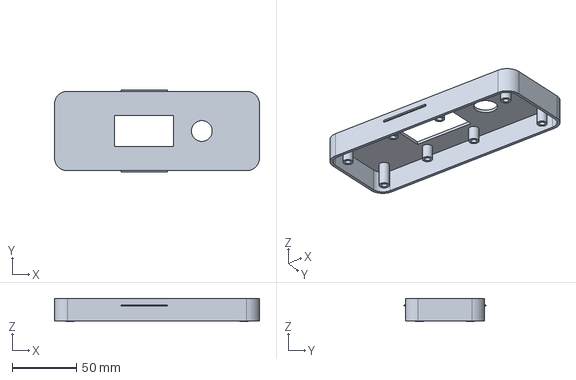
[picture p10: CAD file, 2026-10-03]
cad/step/wastewise-scan-top-shell.step
160.0 x 64.0 x 18.0 mm

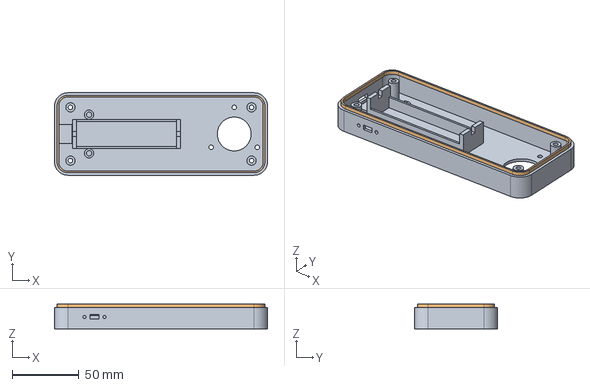
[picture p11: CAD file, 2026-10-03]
cad/step/wastewise-scan-bottom-shell.step
160.0 x 62.0 x 18.6 mm

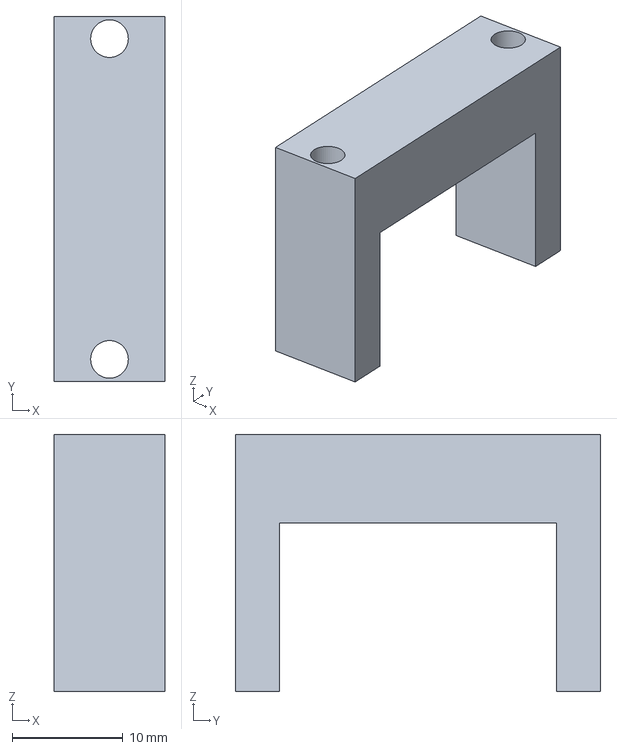
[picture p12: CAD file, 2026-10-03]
cad/step/wastewise-scan-cell-strap.step
10.0 x 33.0 x 23.2 mm

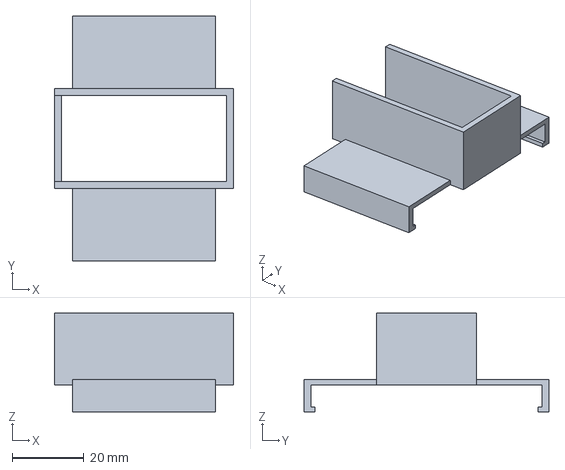
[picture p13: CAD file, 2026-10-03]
cad/step/wastewise-scan-sun-hood.step
50.0 x 68.4 x 27.5 mm

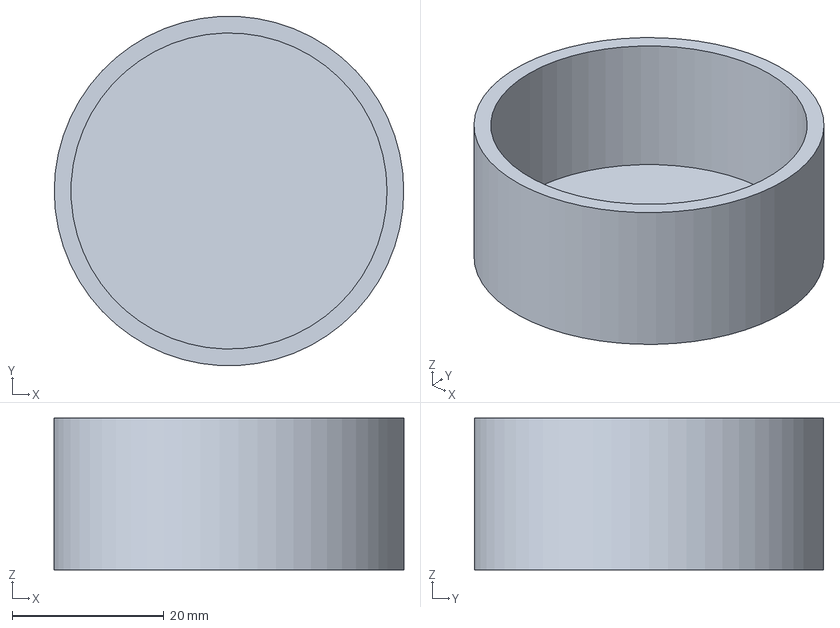
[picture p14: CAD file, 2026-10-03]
cad/step/wastewise-scan-cal-cap.step
46.0 x 45.9 x 20.0 mm

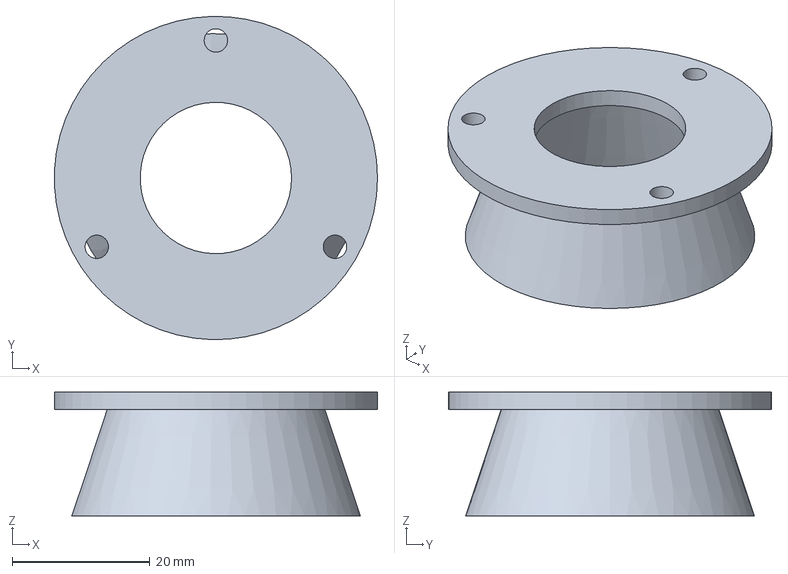
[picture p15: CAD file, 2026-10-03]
cad/step/wastewise-scan-shroud.step
47.0 x 47.0 x 18.0 mm

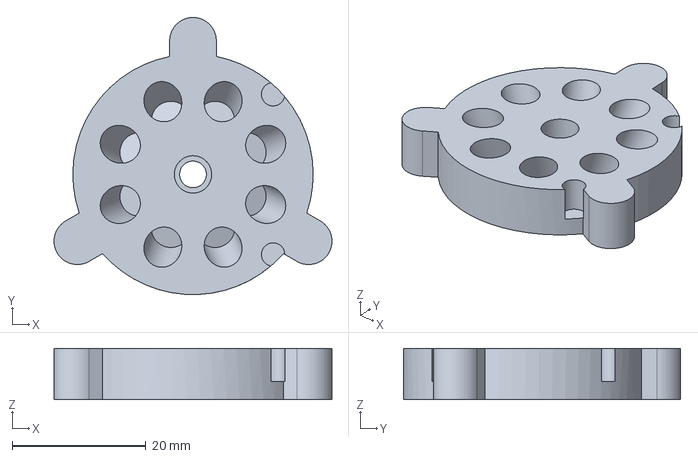
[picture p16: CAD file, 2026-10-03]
cad/step/wastewise-scan-led-holder.step
41.6 x 41.5 x 7.70 mm

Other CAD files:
cad/stl/wastewise-scan-bottom-shell.stl
cad/stl/wastewise-scan-cal-cap.stl
cad/stl/wastewise-scan-cell-strap.stl
cad/stl/wastewise-scan-display-frame.stl
cad/stl/wastewise-scan-led-holder.stl
cad/stl/wastewise-scan-shroud.stl
cad/stl/wastewise-scan-sun-hood.stl
cad/stl/wastewise-scan-top-shell.stl

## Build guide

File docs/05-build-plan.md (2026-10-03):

---
doc_id: WSC-BLD-001
title: WasteWise Scan prototype build plan
project: WasteWise Scan
doc_type: Build plan
version: "0.2"
status: Draft
date: '2026-10-02'
author: Amish Chadha
license: CERN-OHL-S-2.0
revisions:
  - version: "0.1"
    date: '2026-10-02'
    author: Amish Chadha
    change: First build plan, with pictures by component and step; design made constructable (WSC-DDR-004)
  - version: "0.2"
    date: '2026-10-02'
    author: Amish Chadha
    change: Shell walls 2.0 mm (five perimeters); mass estimate 238 g and 258 g; pictures of the shells, display frame and sections regenerated
---

# WasteWise Scan prototype build plan

**Plan, not yet built.** How to build the first proof-of-concept prototype, component by component. Building and testing to it is TRL 4 work. Decisions still to be made are kept in the design decisions register ([docs/06-design-decisions.md](06-design-decisions.md)), not here.

## 1. What you are building

Figure 1. Every component, pulled apart and numbered in build order

*Figure 1. Every component pulled apart and numbered in build order.*

The prototype is one handheld scanner about the size of a large phone, 160 x 62 x 34 mm, with a soft black cone underneath at the head end that is pressed against a plastic item. Inside, eight infrared LEDs and one photodiode sit in a printed block above a glass window; a small hand-built amplifier board reads the photodiode; a bought display board shows the result; one 18650 cell powers it all. Figure 1 shows the 21 components in the order you fit them. Eight are 3D printed (the two shells, the optical head block, the light shroud, the display frame, the cell strap, the sun hood and the calibration cap), one is cut from PTFE sheet and one is cut and drilled from perfboard. Everything else is bought: the window, LEDs, photodiode, cell and its contacts, display board, USB-C board, button, switch, foam gasket and screws. The work is 3D printing in PETG and TPU, pressing brass inserts in with a soldering iron, through-hole soldering and small screws. The parts cost about USD 168 from the bill of materials.

> **Safety:** The prototype holds a lithium-ion cell of about 11 Wh. Keep the cell out of the scanner until the stops in section 6 are passed, never charge it in direct sun or above 45 °C, and never leave a first build charging unattended. The infrared LEDs are invisible: never look into the window while the scanner is powered. A soldering iron at 230 °C is used to set inserts; use a stand and keep the work clamped. The scanner identifies plastic resin only; it must never be used to judge whether waste is safe to handle.

## 2. What changed to make it buildable

The concept showed what the scanner does; most of its parts had no fixing, and a few could not do their job as drawn. Each change below keeps what the scanner does: the body size, the optical layout and distances, the electronics and the calibration method are unchanged. All of them are recorded in decision record WSC-DDR-004, open for Amish's review.

*Table 1. Changes from the concept.*

| Component | The concept had | The buildable design has | Why |
| --- | --- | --- | --- |
| Shells | Two halves touching, with no screws, seal or location | Four screws from below into brass inserts; bosses that meet; a foam gasket on the rim; a tongue that lines up the halves (Figure 5) | The halves close square and sealed, and the gasket cannot be over-squeezed |
| Window | A loose disc in a hole through the floor | Pinched between the shroud flange below and the baffle tube of the head block above (Figure 8) | One clamp holds the window, the shroud and the head block |
| Light shroud | A cone touching the underside, not fixed | A flange with three screws into the head block (Figures 8 and 11) | Held firm, and replaceable when it wears |
| LED holder and amplifier board | A ring floating above the floor, and a board floating above it | An optical head block from the floor to the board, which carries the LEDs, the photodiode and the board (Figure 7) | Every optical part is located by one printed part |
| Cell holder | An open trough for an unprotected cell, with no contacts and nothing holding the cell | A cradle printed with the bottom shell, with contacts for a protected cell and a printed strap over the cell (Figure 15) | The cell stays put in a drop and the contacts have somewhere to sit |
| Display board | No fixing | A printed frame with lips under the board, screwed into the top shell (Figure 13) | The board has no mounting holes of its own |
| Scan button | A hole too small for the button | A 16.2 mm hole for a panel-mount button, nut inside (Figure 6) | Standard fitting with its own seal |
| USB-C socket and switch | Socket overlapping the tail wall; no switch in the model | A USB-C board on a printed seat; a slide switch in the right-hand wall (Figure 3) | Both are reachable and fixed |
| Sun hood | Called clip-on, with nothing to clip to | Two clip legs that snap under ribs on the top shell sides (Figure 17) | No tools; the shading walls are unchanged |
| Calibration cap | Loose on the shroud, too deep for the rim to touch the white disc | A tighter bore that grips the rim, a shorter cap and a wider disc, so the rim rests on the disc (Figure 19) | The white reference is read at the same distance as an item |

## 3. Making the components

Make and check each component before the assembly step that needs it. Sizes are in millimetres. "Head end" is the end with the window and cone; "tail" is the end with the USB-C socket; "left" and "right" are as seen holding the scanner with the display up and the head end pointing away from you. Print in PETG unless a section says otherwise. Workshop tolerance is 0.2 mm on printed parts and 0.5 mm elsewhere; drawings do not carry tolerances before TRL 4.

### 3.1 Bottom shell, with its cradle

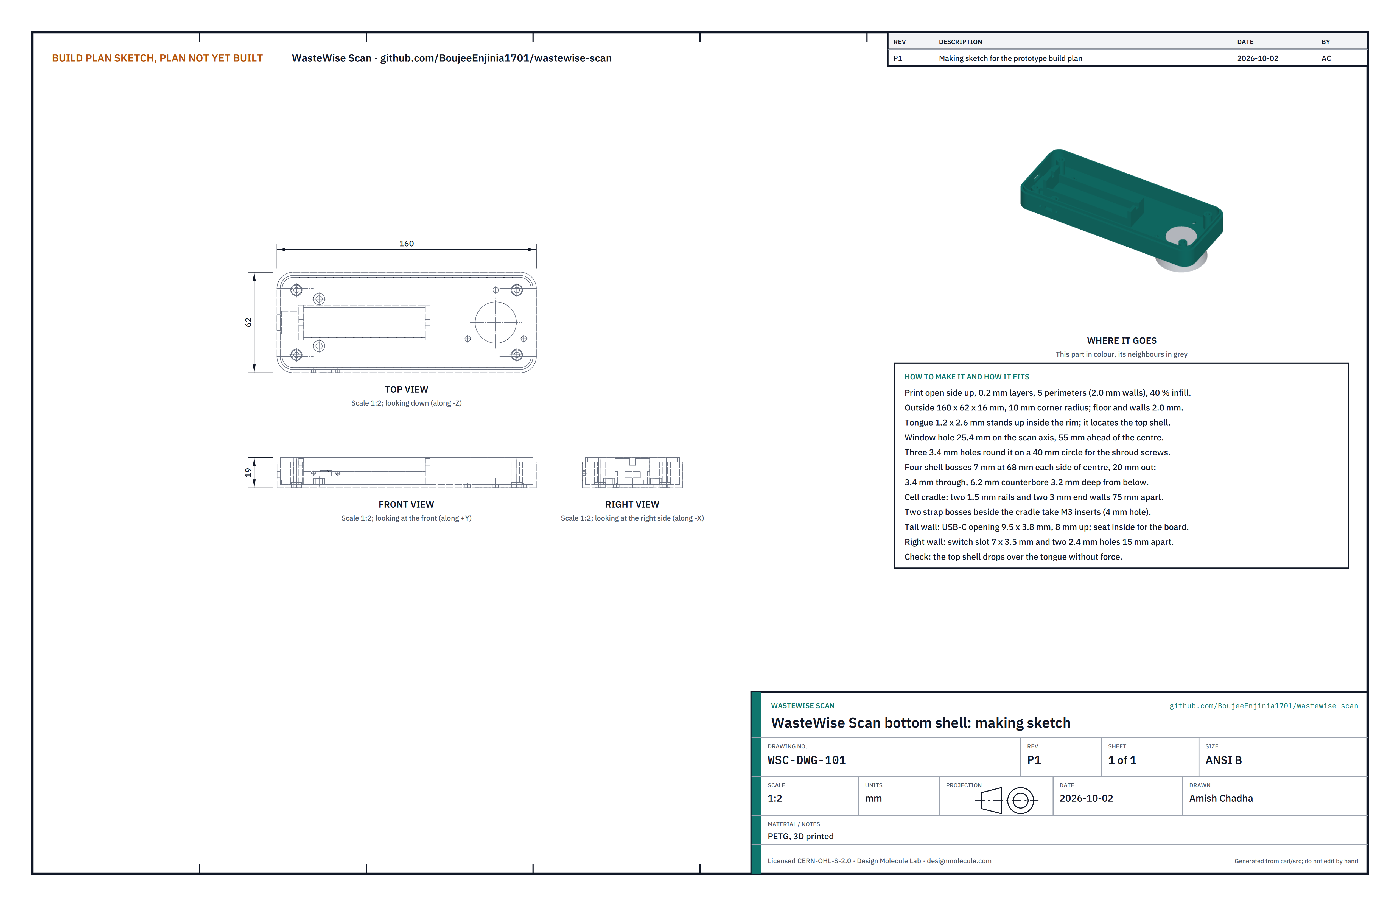
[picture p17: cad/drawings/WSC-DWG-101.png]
Figure 2. Making sketch of the bottom shell


*Figure 2. Bottom shell making sketch (WSC-DWG-101).*

**What it is and what it is made from.** The lower half of the body and the grip, with the cell cradle, the screw bosses and the window hole printed in. PETG, printed open side up.

**How to make it.**

1. Print open side up with 0.2 mm layers, five perimeters (so the 2.0 mm walls are solid) and 40 % infill. Support is needed only under the USB-C opening.
2. Check the window hole: a 25.4 mm hole through the floor, 55 mm ahead of the body centre on the centre line. The window must drop in with a little play.
3. Clear the three 3.4 mm holes round the window hole (on a 40 mm circle) and the four 3.4 mm holes through the corner bosses with a drill by hand.
4. Check the four counterbores on the underside: 6.2 mm across and 3.2 mm deep, so the screw heads sit below the surface.
5. Press an M3 heat-set insert into each of the two small bosses beside the cradle, with the iron at about 230 °C, square and flush.
6. Clear the slot in the right-hand wall (7 x 3.5 mm) and its two 2.4 mm screw holes, and the USB-C opening in the tail wall (9.5 x 3.8 mm).

**How it fits the parts next to it.** The cradle takes the cell and its contacts; the head block stands on the floor over the window hole; the shroud screws to the underside; the top shell drops over the tongue on the rim. At the tail, the USB-C board sits on its seat with its socket in the opening, and the switch sits against the inside of the right-hand wall:

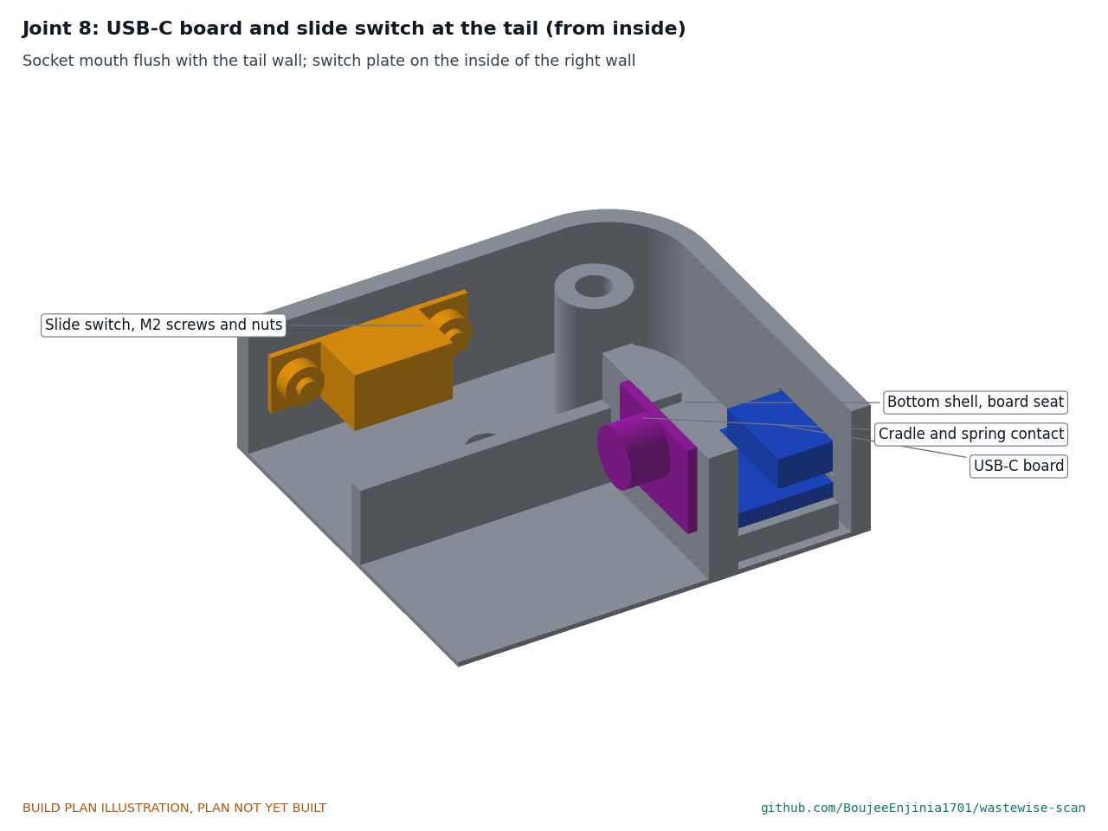
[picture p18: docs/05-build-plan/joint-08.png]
Figure 3. Joint 8: USB-C board and slide switch at the tail


*Figure 3. Joint 8: the USB-C board on its seat and the slide switch on the inside of the right-hand wall, seen from inside.*

**Check before moving on.** The floor is flat within 0.3 mm (the head block must sit on it without rocking); a 69 mm cell drops into the cradle between the end walls with about 6 mm to spare for the contacts.

### 3.2 Top shell

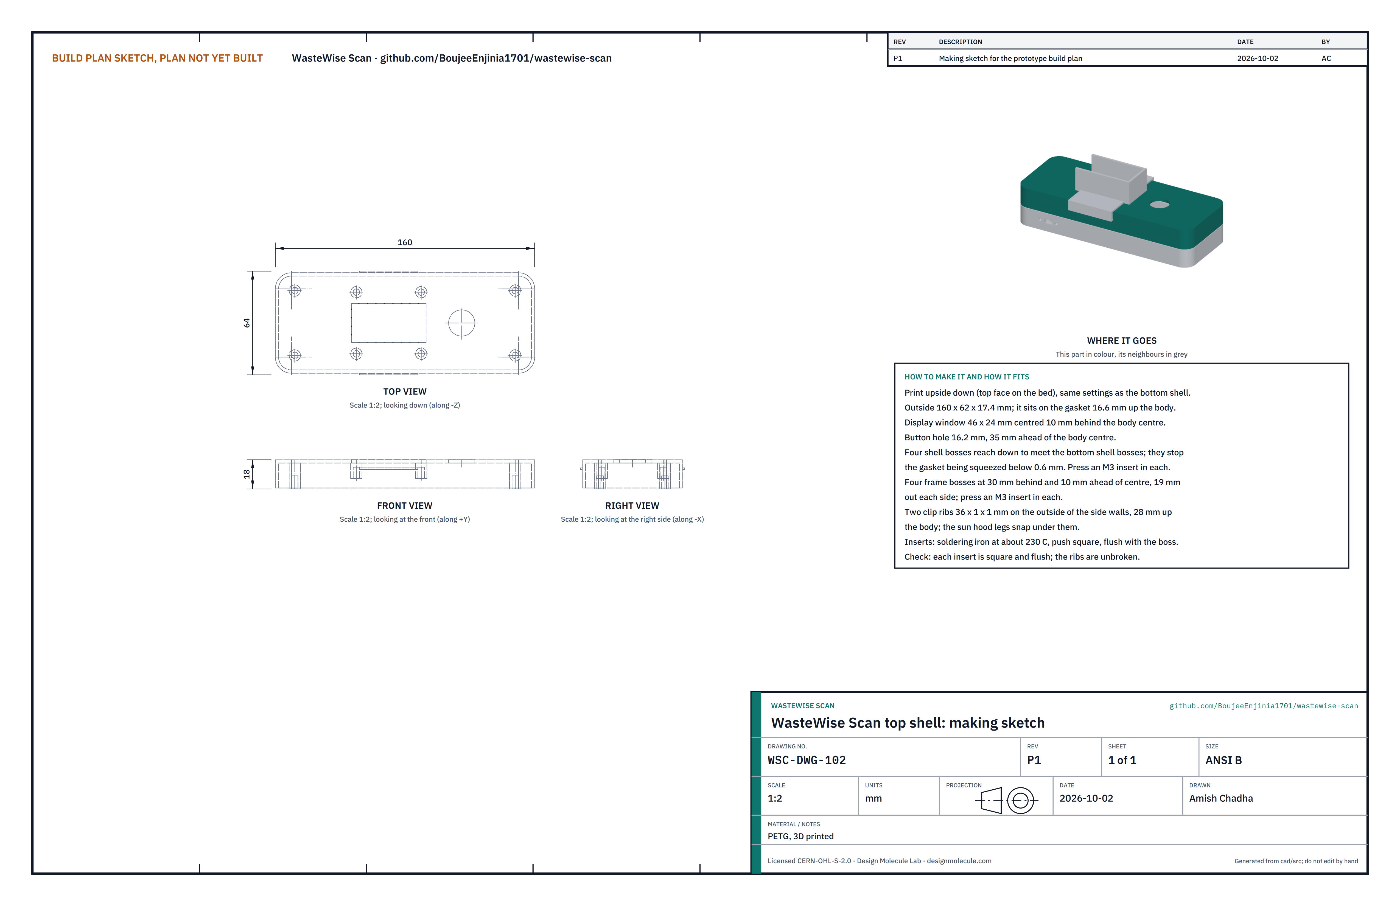
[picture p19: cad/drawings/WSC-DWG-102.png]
Figure 4. Making sketch of the top shell


*Figure 4. Top shell making sketch (WSC-DWG-102).*

**What it is and what it is made from.** The upper half of the body, with the display window, the button hole, eight bosses for inserts and the two ribs the sun hood clips under. PETG, printed upside down (top face on the bed).

**How to make it.**

1. Print top face down, with the same settings as the bottom shell. The bosses grow up from the ceiling and need no support.
2. Check the display window (46 x 24 mm) and the button hole (16.2 mm, 35 mm ahead of the body centre).
3. Press an M3 heat-set insert into each of the eight bosses: four at the corners for the shell screws, four near the display for the frame screws.
4. Check the two ribs on the outside of the side walls are whole along their 36 mm length.

**How it fits the parts next to it.** The corner bosses reach down past the rim and meet the bottom shell's bosses face to face, which sets the gasket squeeze; the rim sits on the gasket; the tongue of the bottom shell sits just inside its walls:

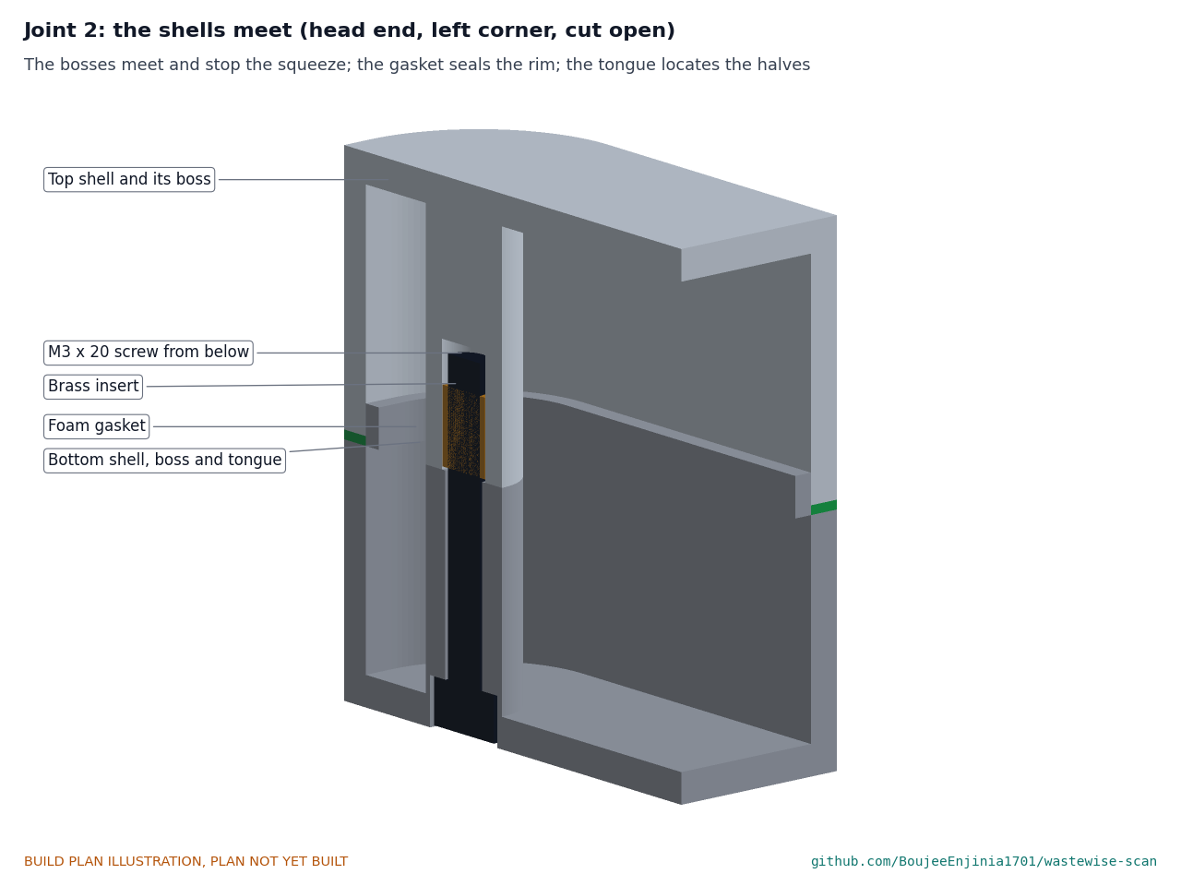
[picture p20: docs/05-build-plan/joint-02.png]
Figure 5. Joint 2: the shells meet


*Figure 5. Joint 2: the screw comes up through the bottom shell boss into the insert in the top shell boss; the bosses meet; the gasket is squeezed to 0.6 mm between the rims; the tongue lines the halves up.*

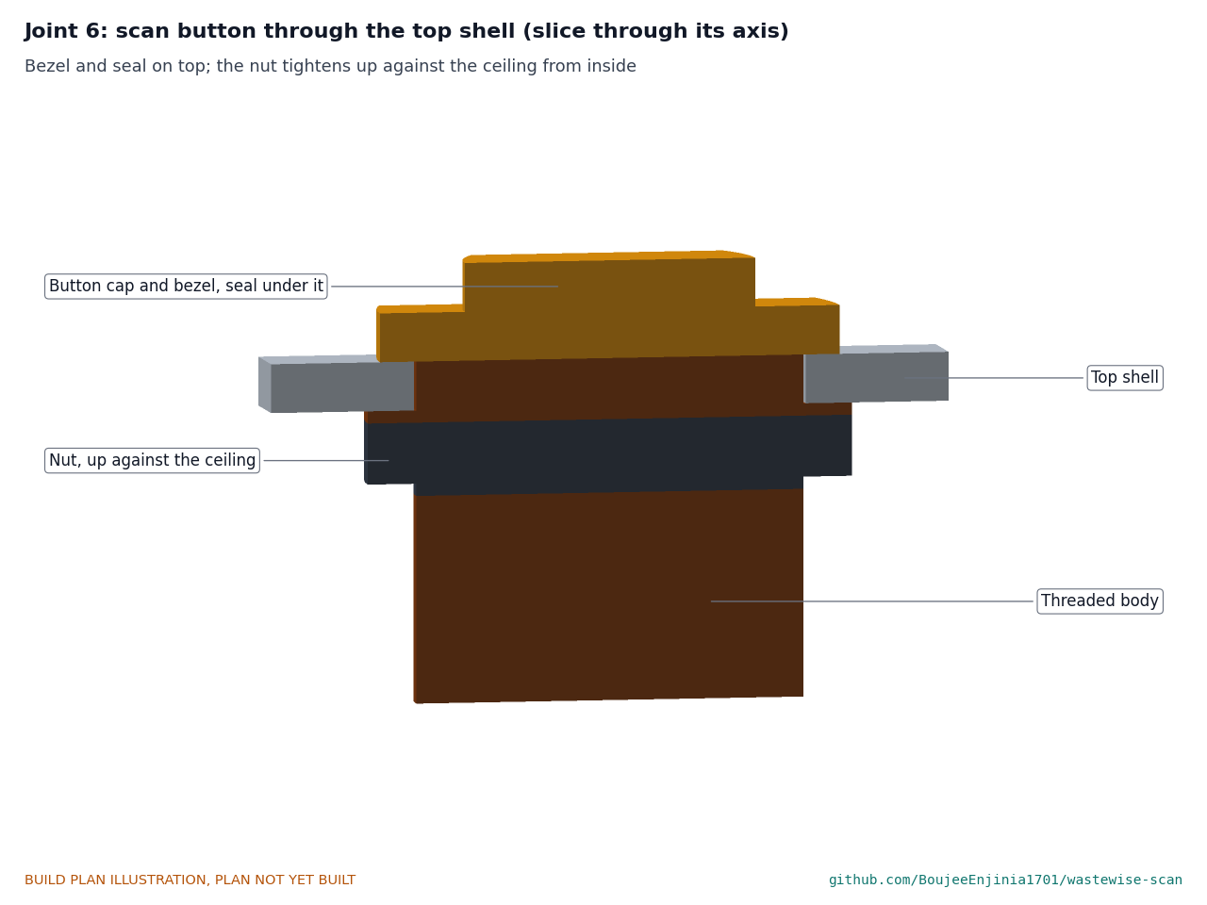
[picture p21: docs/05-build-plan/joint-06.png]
Figure 6. Joint 6: scan button through the top shell


*Figure 6. Joint 6: the button goes in from outside with its seal under the bezel, and its nut tightens up against the ceiling from inside.*

**Check before moving on.** The top shell sits on the bottom shell over the tongue, without the gasket, with the corner bosses touching and the rims about 0.6 mm apart all round.

### 3.3 Optical head block, with its LEDs and photodiode

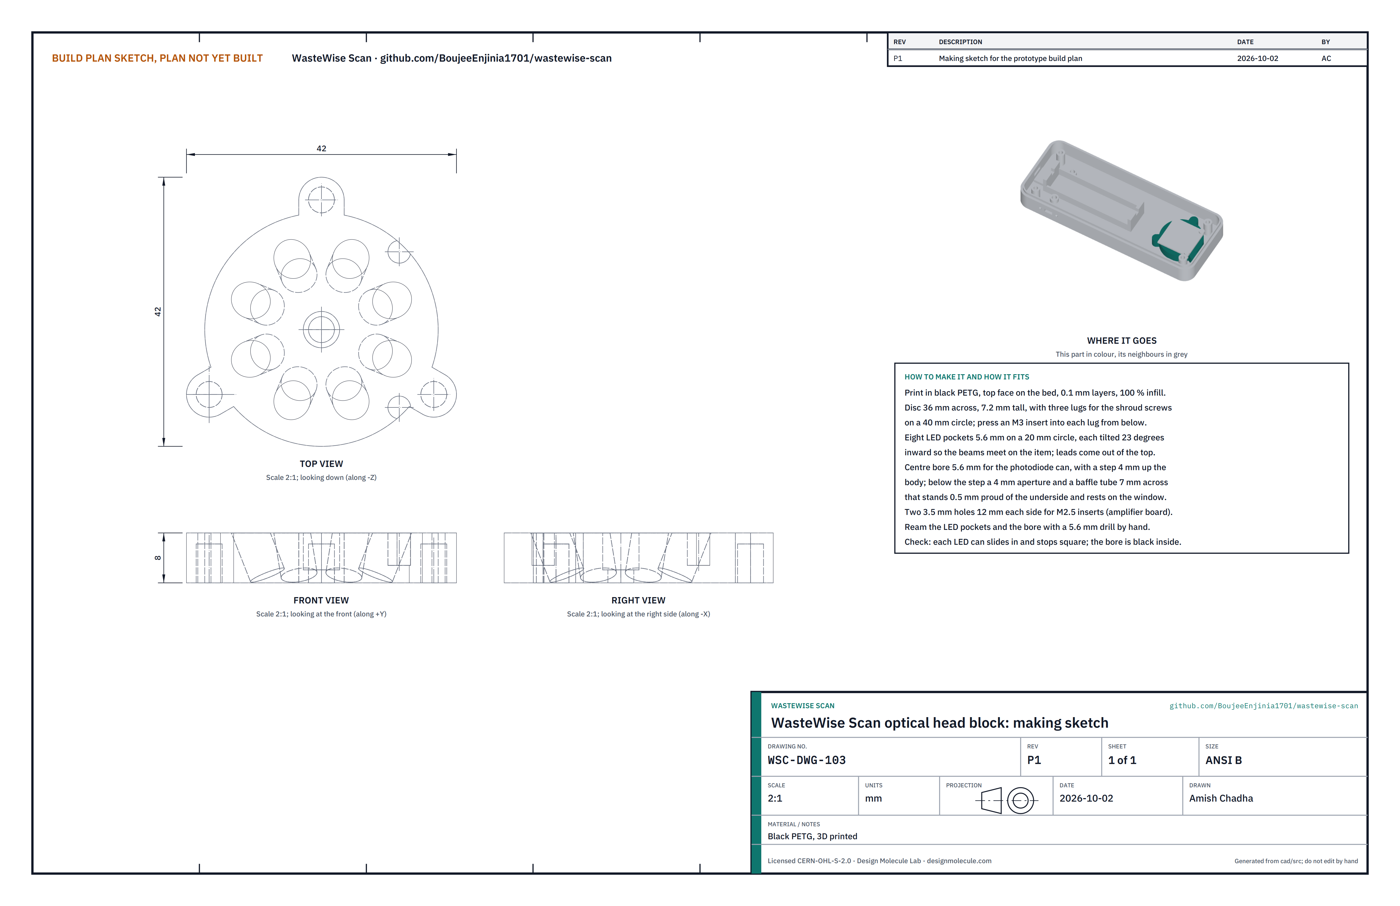
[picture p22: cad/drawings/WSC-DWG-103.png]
Figure 7. Making sketch of the optical head block


*Figure 7. Optical head block making sketch (WSC-DWG-103).*

**What it is and what it is made from.** The printed block that holds the eight LEDs at the right angle, holds the photodiode above the window, keeps stray light away from it, and carries the amplifier board. Black PETG, 100 % infill.

**How to make it.**

1. Print in black PETG with its top face on the bed, 0.1 mm layers, 100 % infill.
2. Ream the eight LED pockets and the centre bore by hand with a 5.6 mm drill held in a pin vice.
3. Press an M3 insert into each of the three lugs from the underside, and an M2.5 insert into each of the two holes on the top face nearest the head end.
4. Push each LED can into its pocket from the top until it stops square (the pocket is a close fit), and the photodiode can into the centre bore until it sits on the step. Fit the bands in a fixed order round the ring and mark it on the block.

**How it fits the parts next to it.** The block stands on the floor of the bottom shell with its three lugs over the three holes round the window. Its baffle tube stands 0.5 mm below its underside and rests on the window, so light from the LEDs cannot reach the photodiode through the glass without going out to the item first. The amplifier board sits on its top face:

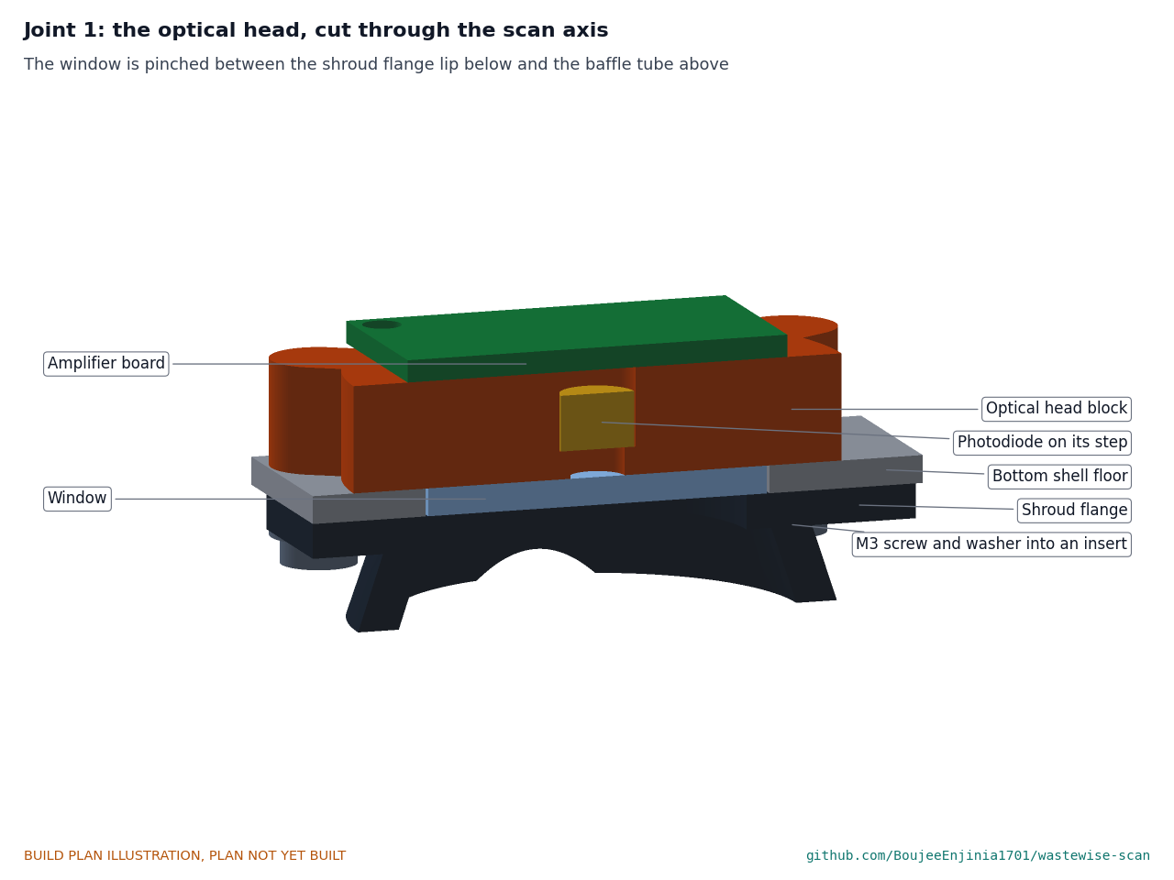
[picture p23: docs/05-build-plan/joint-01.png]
Figure 8. Joint 1: the optical head, cut through the scan axis


*Figure 8. Joint 1: the shroud flange lip holds the window up from below and the baffle tube holds it down from above; three screws through the flange and the floor pull the shroud, window and head block together.*

**Check before moving on.** Every can is seated square; the block stands on a flat surface without rocking; looking down the centre bore you see light only through the 4 mm aperture.

### 3.4 Amplifier board

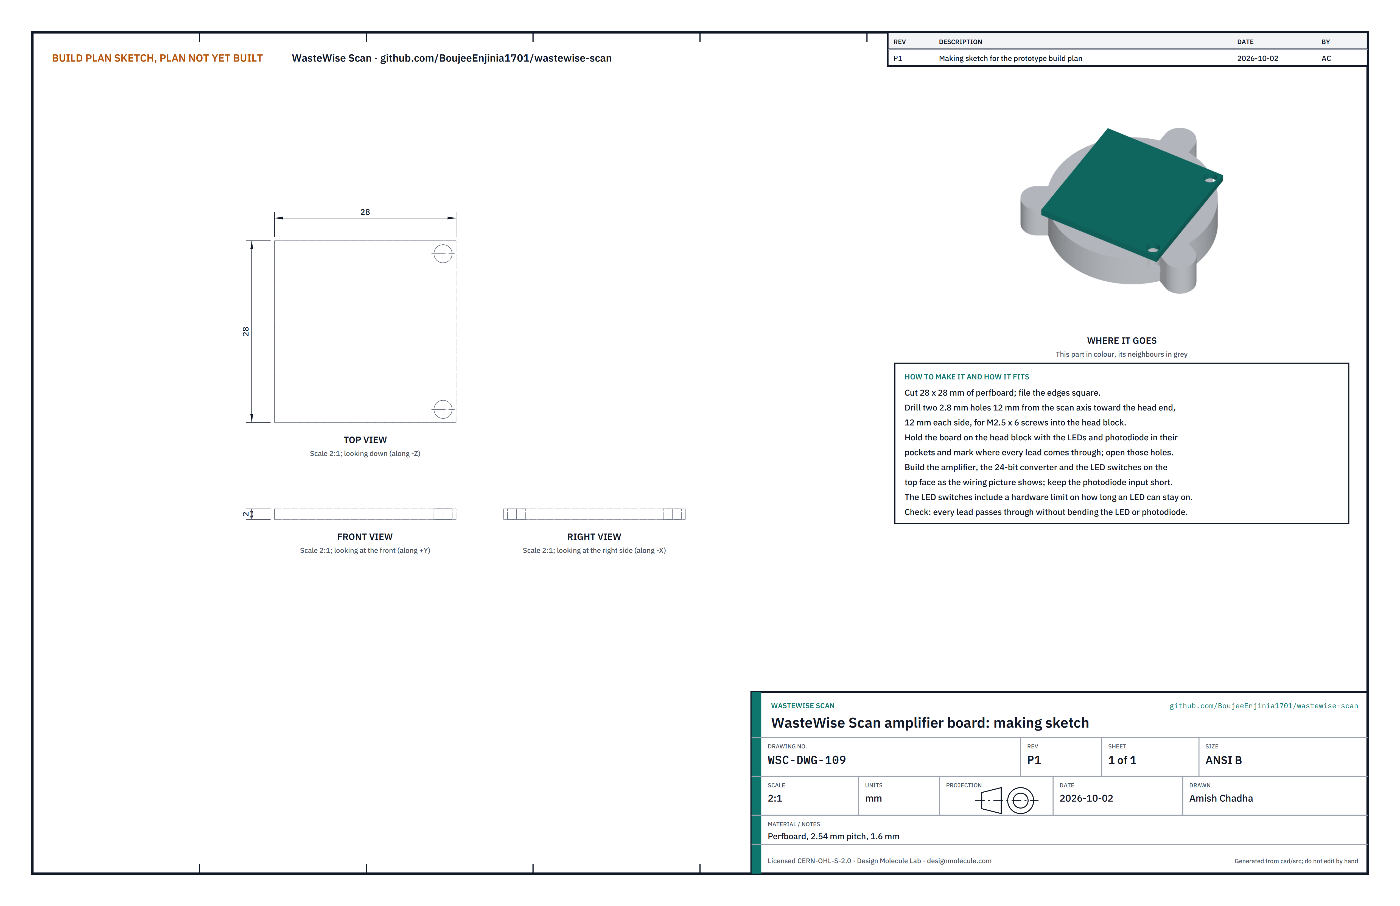
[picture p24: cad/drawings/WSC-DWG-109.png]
Figure 9. Making sketch of the amplifier board


*Figure 9. Amplifier board making sketch (WSC-DWG-109).*

**What it is and what it is made from.** A 28 x 28 mm square of perfboard carrying the photodiode amplifier, the 24-bit converter and the LED switches, sitting on top of the head block so the photodiode leads are as short as possible. Perfboard with 2.54 mm pitch, 1.6 mm thick.

**How to make it.**

1. Cut the square and file the edges.
2. Drill two 2.8 mm holes 12 mm toward the head end from the scan axis and 12 mm each side of it.
3. Hold the board on the head block with the LEDs and photodiode in place, mark where each lead comes up, and open those holes.
4. Build the circuit on the top face as Figure 10 shows: the photodiode amplifier with a 47 kΩ feedback resistor, the 24-bit converter, and one constant-current switch per LED with a hardware limit on how long any LED can stay on.

#### 3.4.1 Wiring

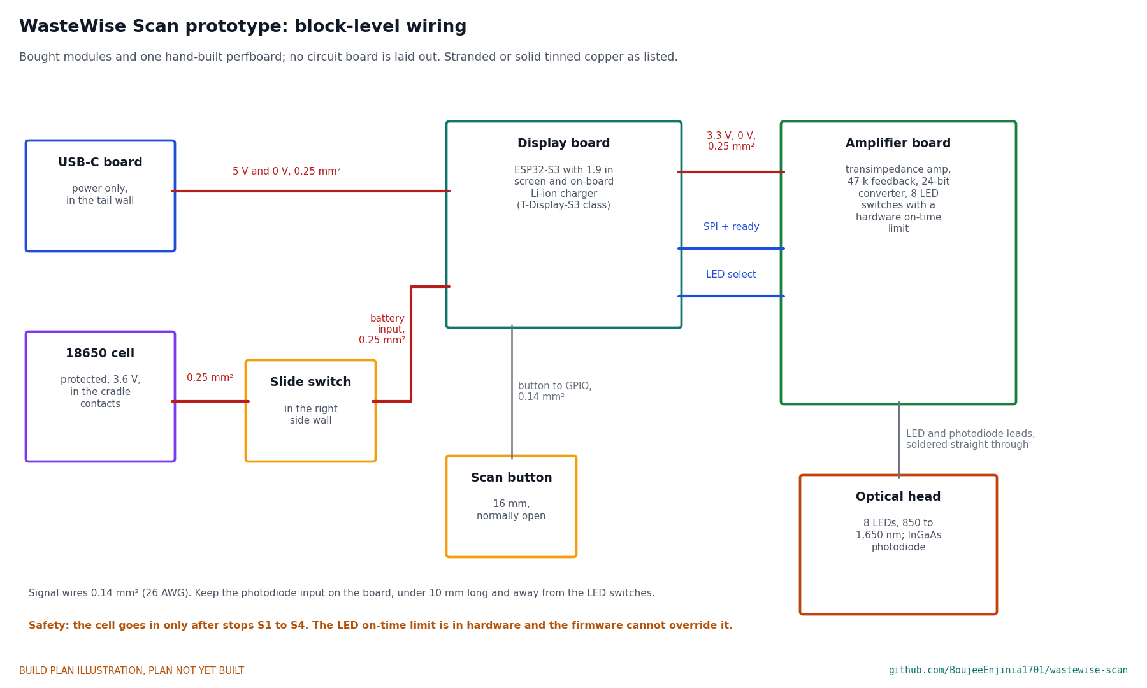
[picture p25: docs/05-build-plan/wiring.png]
Figure 10. Block-level wiring


*Figure 10. Block-level wiring with wire sizes. No circuit board is laid out at this stage.*

Wire it like this:

1. USB-C board to the display board's 5 V and 0 V pins, so the board's own charger charges the cell: 0.25 mm² (24 AWG).
2. Cell contacts to the slide switch, and the switch to the display board's battery input: 0.25 mm². Charging needs the switch on.
3. Display board 3.3 V and 0 V to the amplifier board: 0.25 mm².
4. Display board to the converter (four data wires and a ready line) and to the LED select lines: 0.14 mm² (26 AWG), twisted with a 0 V wire where possible.
5. Scan button to a free input pin and 0 V: 0.14 mm².
6. LED and photodiode leads go straight through the amplifier board and are soldered there; keep the photodiode input under 10 mm long and away from the LED switches.

Leave every lead about 60 mm long so the two shells can lie side by side while you work.

**Check before moving on.** Every wire continues end to end; with no cell fitted, the cell contacts read open to every other node; every LED lights on a camera without an infrared filter (an old phone camera) when its switch is driven from a bench supply through a 100 Ω resistor.

### 3.5 Light shroud

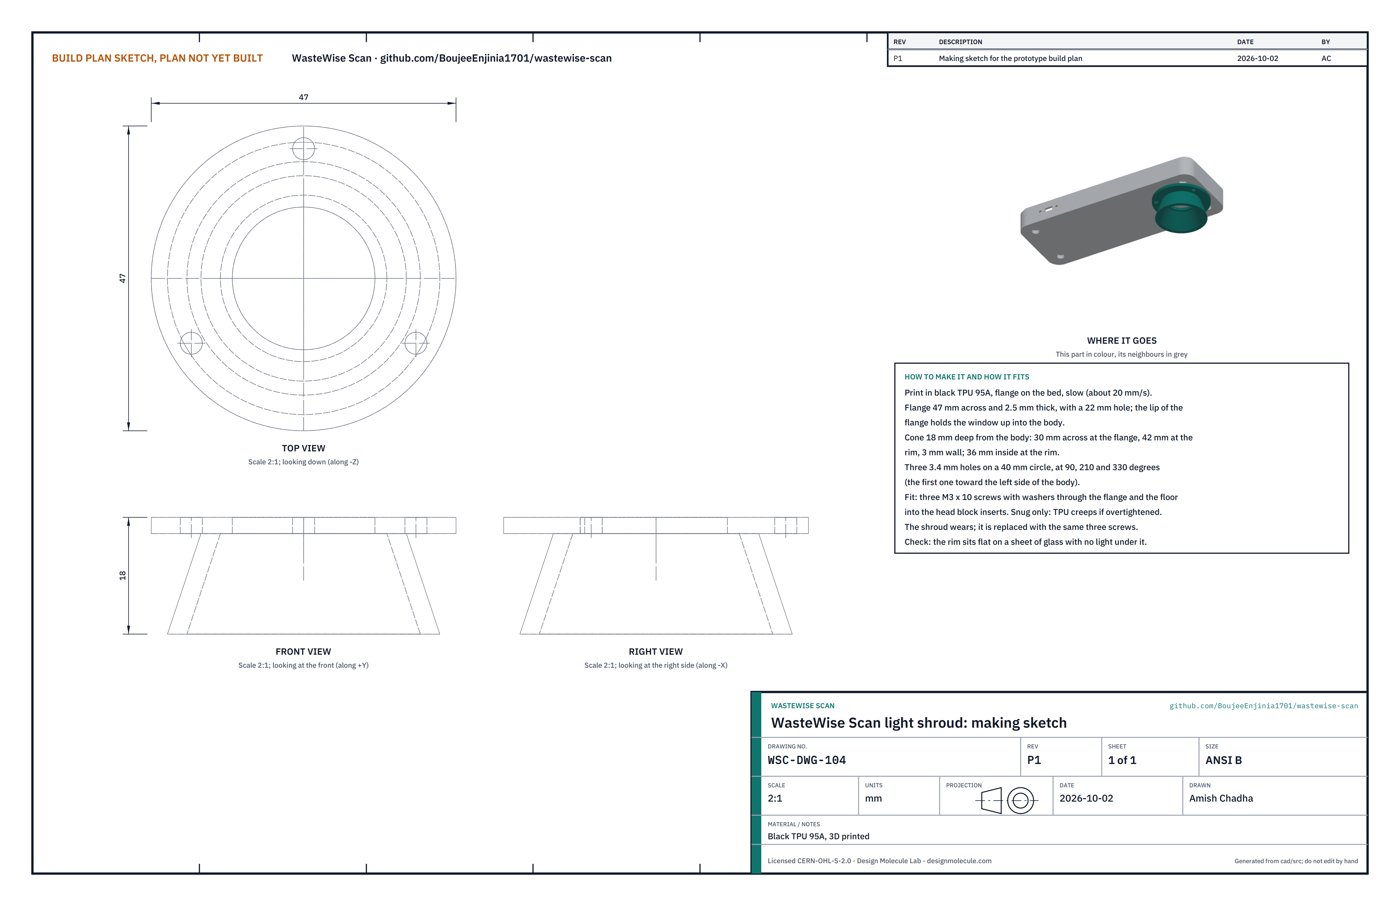
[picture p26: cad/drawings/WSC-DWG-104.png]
Figure 11. Making sketch of the light shroud


*Figure 11. Light shroud making sketch (WSC-DWG-104).*

**What it is and what it is made from.** The soft black cone pressed against the item. It blocks direct light, sets the distance from the detector to the item at 22 mm, and its flange holds the window. Black TPU 95A.

**How to make it.**

1. Print in black TPU, flange on the bed, slowly (about 20 mm/s), 100 % infill.
2. Check the flange: 47 mm across, 2.5 mm thick, with a 22 mm hole in the middle and three 3.4 mm holes on a 40 mm circle.
3. Check the cone: 18 mm deep from the underside of the body, 42 mm across the rim with a 3 mm wall.

**How it fits the parts next to it.** The flange lies flat on the underside of the body round the window hole; its lip covers the outer 1.5 mm of the window (Figure 8). Three M3 x 10 screws with washers go through the flange and the floor into the head block's inserts. Tighten them only until the flange is flat: TPU creeps if overtightened.

**Check before moving on.** Pressed on a sheet of glass over a bright lamp, no light shows under the rim.

### 3.6 Display frame

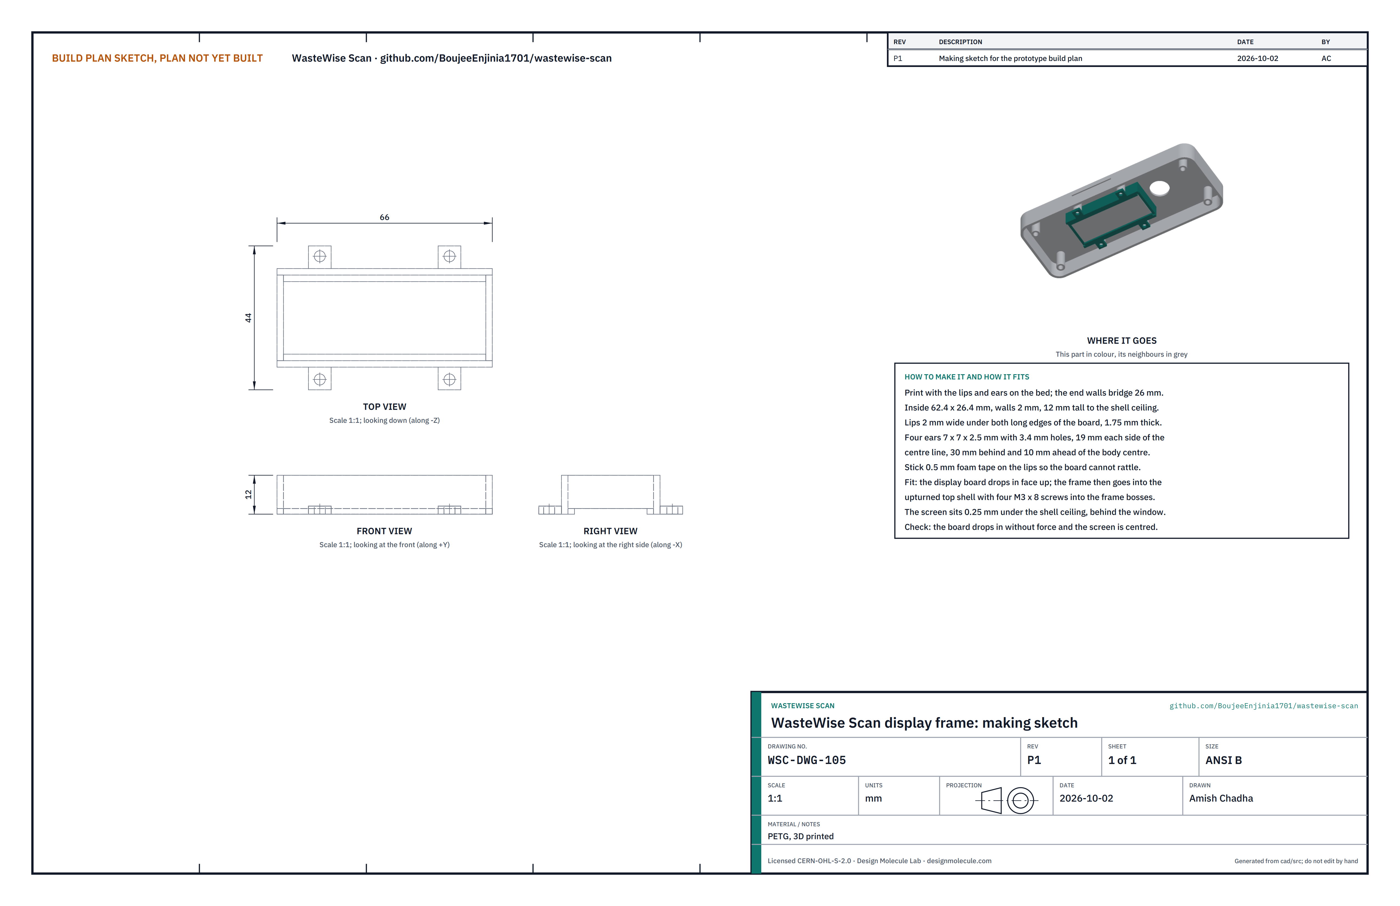
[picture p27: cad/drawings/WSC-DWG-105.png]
Figure 12. Making sketch of the display frame


*Figure 12. Display frame making sketch (WSC-DWG-105).*

**What it is and what it is made from.** A printed frame that holds the bought display board under the display window. PETG.

**How to make it.**

1. Print with the lips and ears on the bed; the two short end walls bridge across 26 mm.
2. Check the inside is 62.4 x 26.4 mm and the board drops in.
3. Stick 0.5 mm foam tape on top of both lips.

**How it fits the parts next to it.**

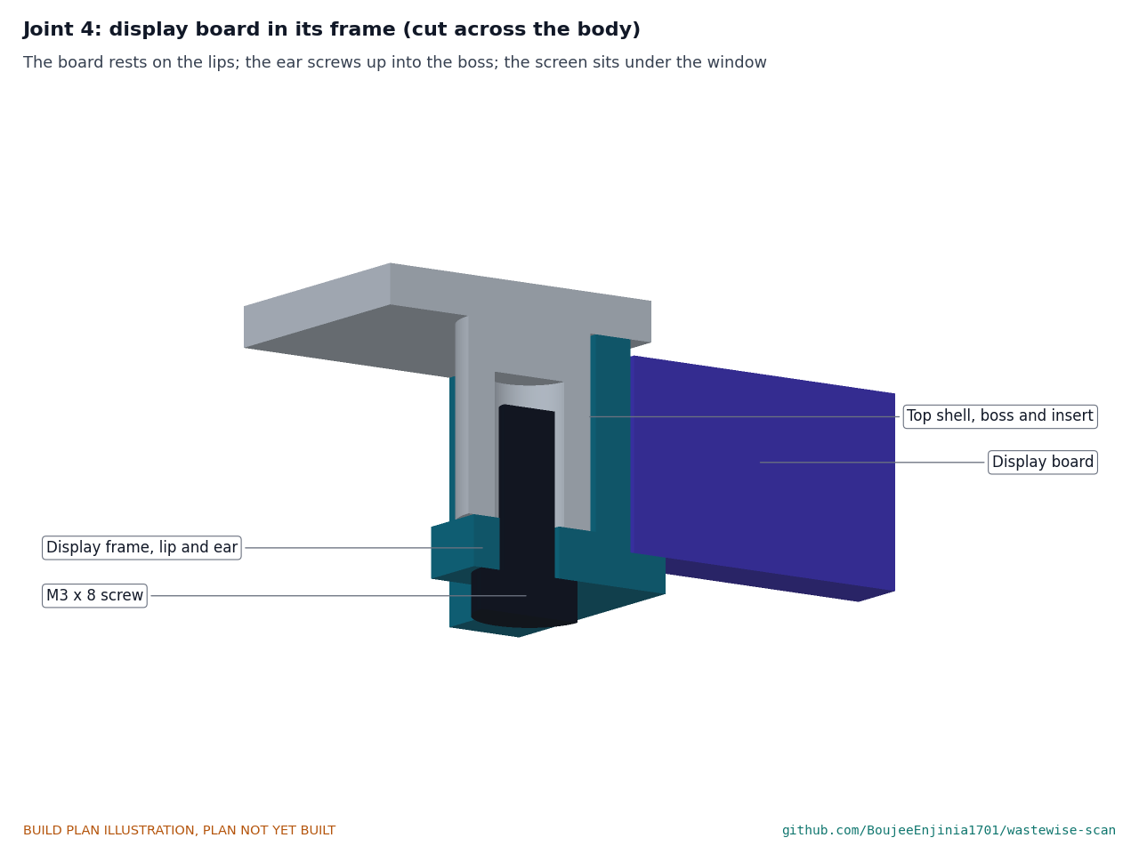
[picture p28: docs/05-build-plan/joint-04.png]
Figure 13. Joint 4: display board in its frame


*Figure 13. Joint 4: the board rests on the lips; each ear takes an M3 x 8 screw up into an insert in the top shell boss; the screen sits 0.25 mm under the ceiling, behind the window.*

**Check before moving on.** With the board in, the screen sits centred in the display window when the frame is held in place.

### 3.7 Cell strap

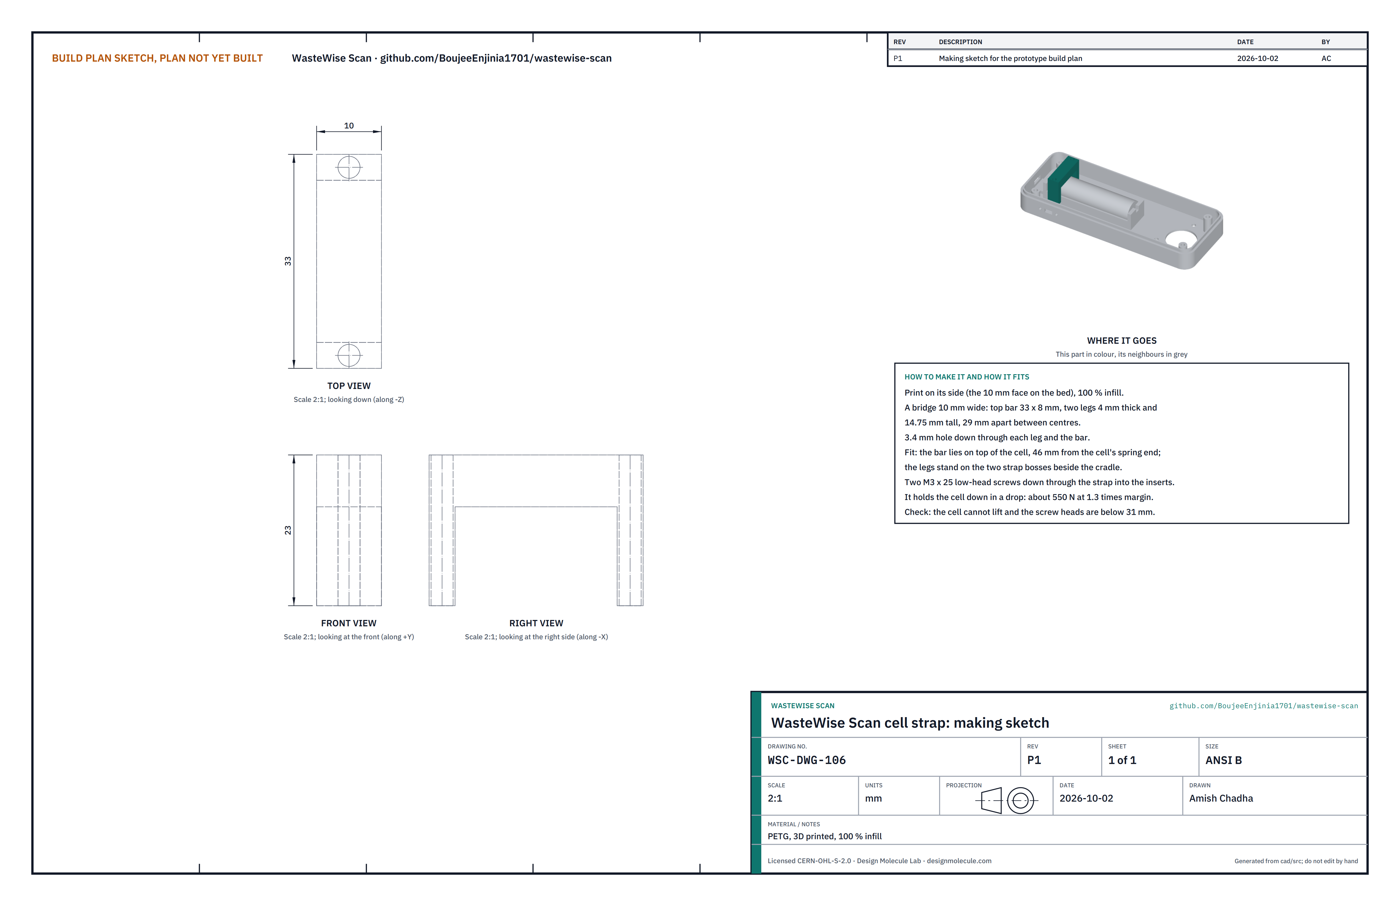
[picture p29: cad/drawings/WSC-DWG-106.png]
Figure 14. Making sketch of the cell strap


*Figure 14. Cell strap making sketch (WSC-DWG-106).*

**What it is and what it is made from.** A printed bridge across the cell that stops it lifting out of the cradle in a drop. PETG, 100 % infill.

**How to make it.**

1. Print on its side (the 10 mm face on the bed), 100 % infill, so the layers run along the bar.
2. Clear the 3.4 mm hole down through each leg.

**How it fits the parts next to it.**

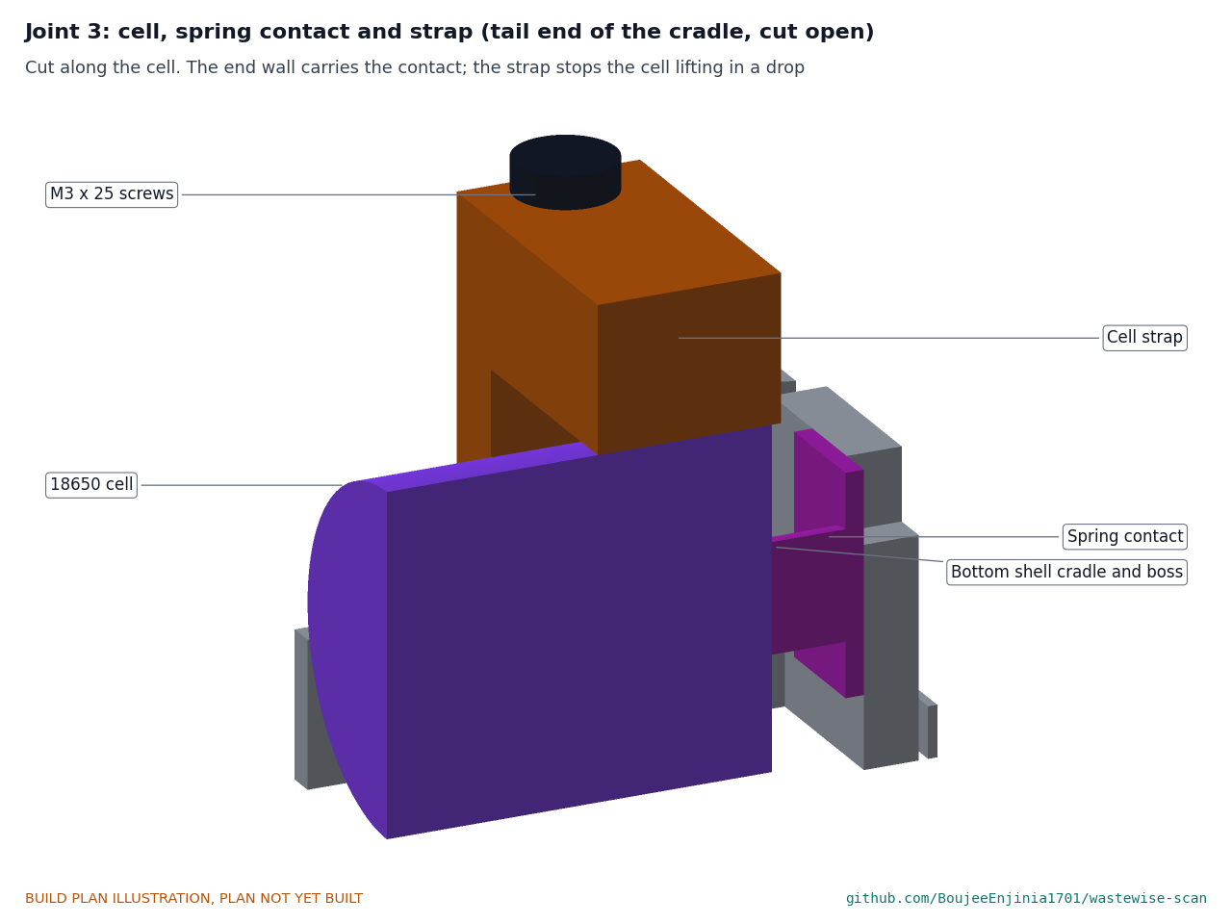
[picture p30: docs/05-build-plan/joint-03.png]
Figure 15. Joint 3: cell, spring contact and strap


*Figure 15. Joint 3: the spring contact sits in the tail end wall of the cradle; the strap bar lies on the cell and its legs stand on the two bosses beside the cradle.*

The bar lies on top of the cell near its tail end; two M3 x 25 low-head screws go down through the legs into the inserts in the floor bosses. Their heads stay below the top shell ceiling.

**Check before moving on.** With the strap screwed down, the cell cannot be lifted and does not rattle.

### 3.8 Sun hood

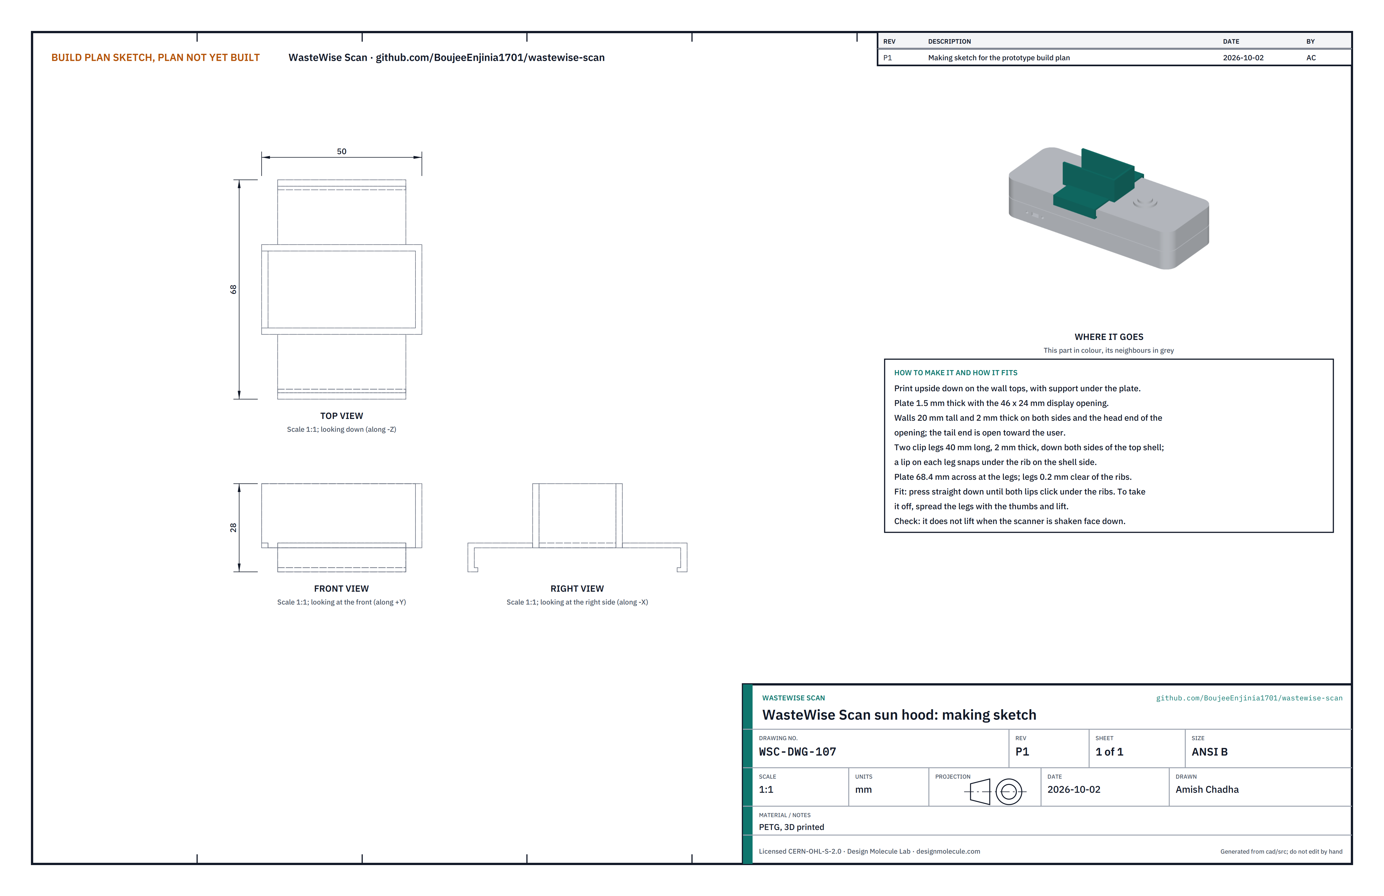
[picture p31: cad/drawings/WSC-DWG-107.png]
Figure 16. Making sketch of the sun hood


*Figure 16. Sun hood making sketch (WSC-DWG-107).*

**What it is and what it is made from.** A clip-on hood that shades the display from the sun on both sides and at the head end, open toward the user. PETG.

**How to make it.**

1. Print upside down, standing on the top edges of its walls, with support under the plate.
2. Remove the support and file the plate's underside flat.
3. Check the lips at the bottom of the two legs are whole.

**How it fits the parts next to it.**

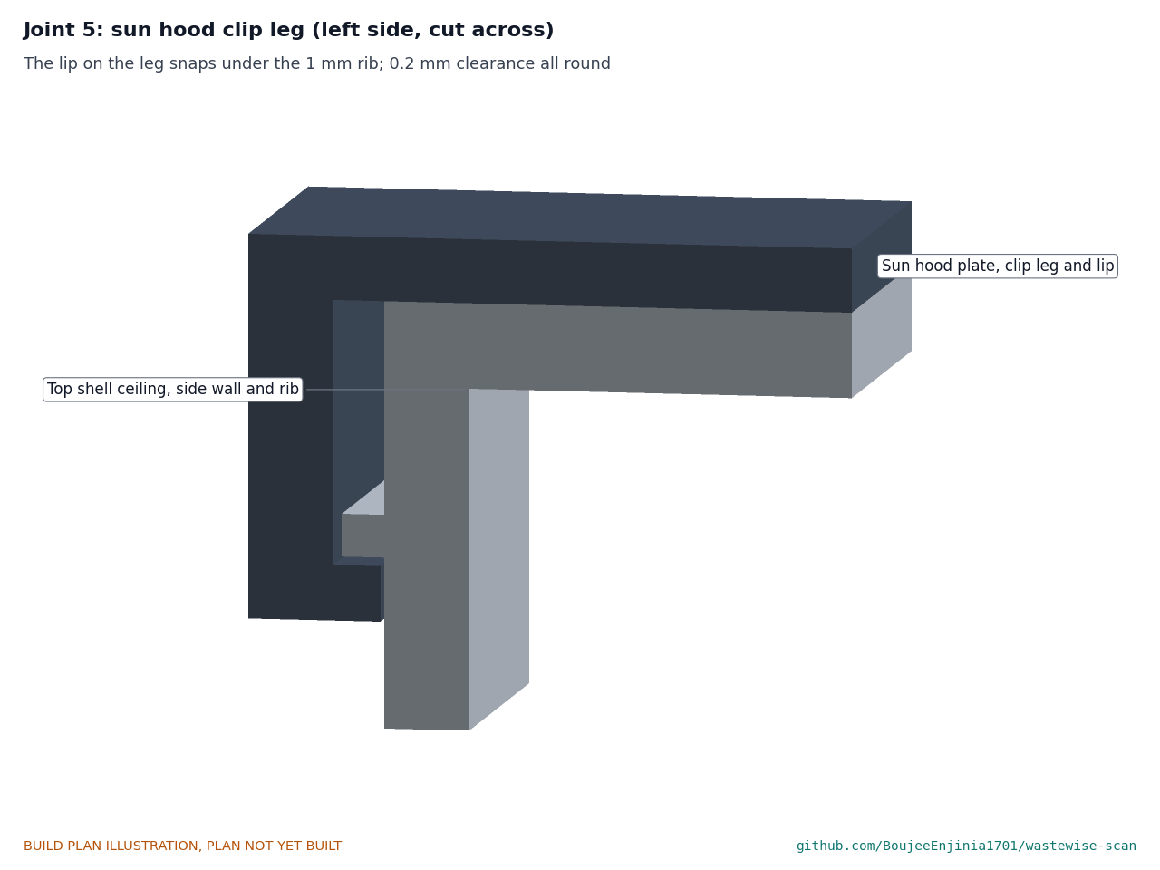
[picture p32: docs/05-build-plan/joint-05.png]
Figure 17. Joint 5: sun hood clip leg


*Figure 17. Joint 5: the plate sits on the top shell; the lip at the bottom of each leg snaps under the rib on the shell side, with 0.2 mm clearance.*

**Check before moving on.** It clicks on and off by hand and does not lift when the scanner is shaken face down.

### 3.9 Calibration cap and PTFE disc

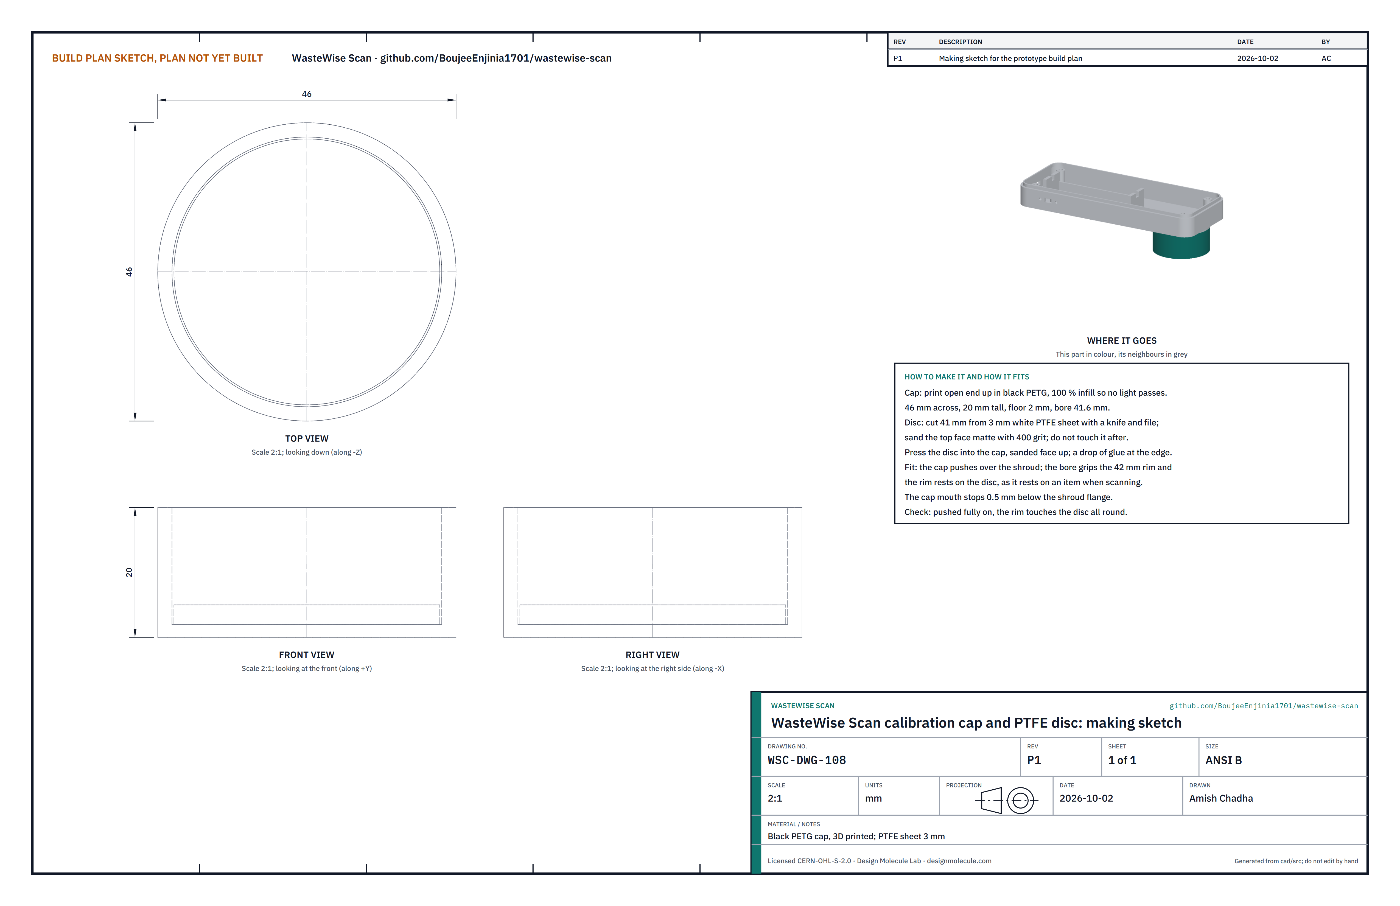
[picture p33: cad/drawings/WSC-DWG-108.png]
Figure 18. Making sketch of the calibration cap and disc


*Figure 18. Calibration cap and PTFE disc making sketch (WSC-DWG-108).*

**What it is and what it is made from.** A black cap with a white PTFE disc in its floor. It protects the shroud when stored, gives the white reference for calibration, and backs clear items in sun. Black PETG at 100 % infill, so no light passes; white PTFE sheet 3 mm thick.

**How to make it.**

1. Print the cap open end up: 46 mm across, 20 mm tall, 2 mm floor, 41.6 mm bore.
2. Cut a 41 mm disc from the PTFE sheet with a sharp knife against a template, and file the edge round.
3. Sand the top face matte with 400 grit paper, then do not touch it.
4. Press the disc into the cap, sanded face up, with a small drop of glue at the edge only.

**How it fits the parts next to it.**

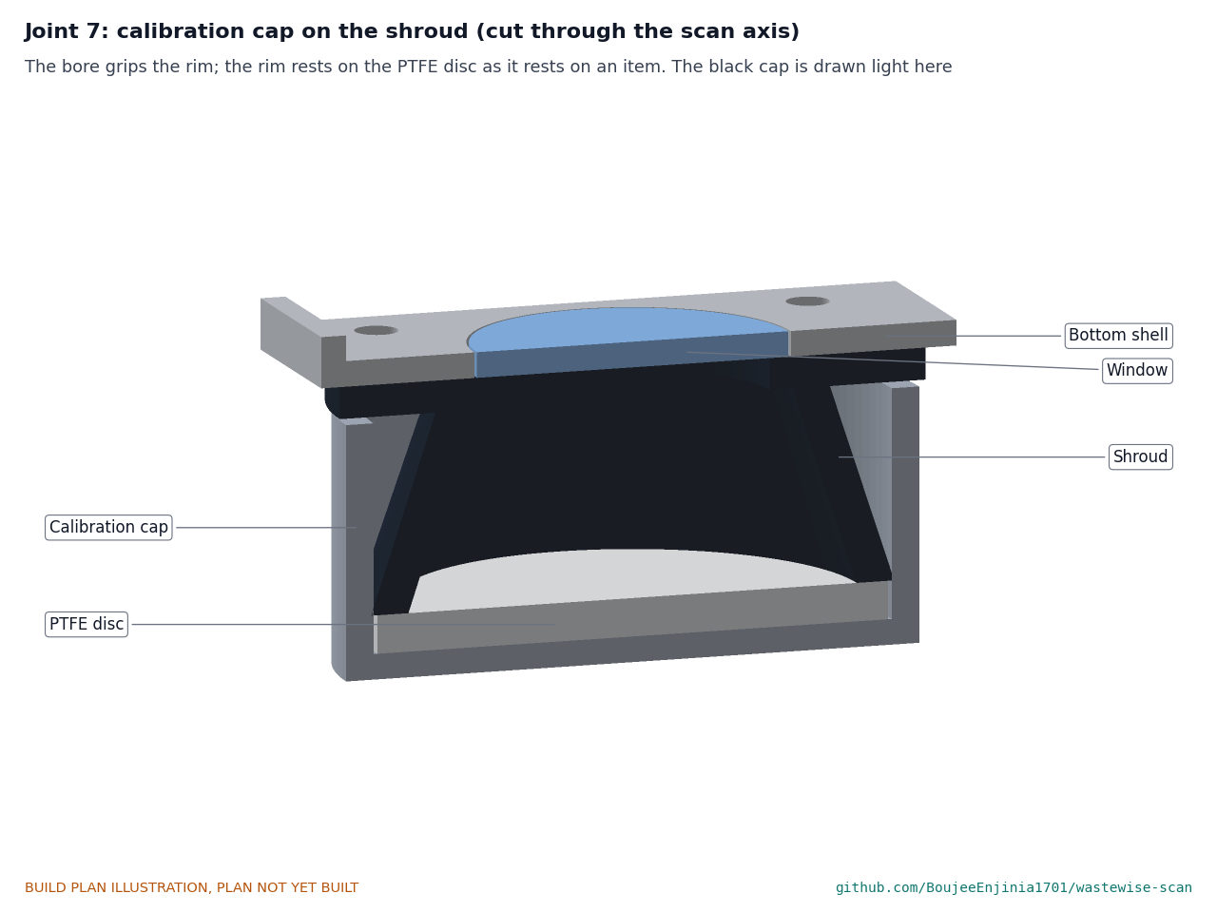
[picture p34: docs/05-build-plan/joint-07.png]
Figure 19. Joint 7: calibration cap on the shroud


*Figure 19. Joint 7: the bore grips the shroud rim; the rim rests on the disc, as it rests on an item when scanning; the cap mouth stops just short of the flange.*

**Check before moving on.** Pushed fully on, the rim touches the disc all round (check by eye through the gap at the flange) and the cap does not fall off when shaken.

### 3.10 Bought components

Buy to specification, not brand. Line numbers are those of the bill of materials.

- **Display board (line 2).** ESP32-S3 board with a 1.9 in display and an on-board lithium-ion charger, about 62 x 26 x 9.5 mm (T-Display-S3 class).
- **LEDs (line 3).** One each at 850, 940, 1,050, 1,200, 1,300, 1,450, 1,550 and 1,650 nm, in TO-46 cans 5.4 mm across. A band available only as a 5 mm lens LED needs its pocket opened to suit its 5.8 mm rim.
- **Photodiode (line 4).** InGaAs PIN, 1 mm active area, about 900 to 1,700 nm, TO-46 can.
- **Amplifier parts (line 5).** Low-noise op-amp, 47 kΩ feedback resistor, 24-bit converter on a breakout (ADS1220 class), eight constant-current LED switches.
- **Window (line 6).** Borosilicate disc 25 mm across, 2 mm thick, uncoated.
- **Cell (line 8).** One protected 18650 lithium-ion cell, 3,000 mAh, button top, about 69 mm long, from a named cell maker.
- **Cell contacts and USB-C board (line 9).** A spring and flat contact pair for 18650 cells with solder tabs; a power-only USB-C board about 10 x 12 mm.
- **Button and switch (line 11).** Sealed 16 mm panel-mount push button with an M16 thread and nut; panel slide switch with two M2 holes 15 mm apart.
- **Shell gasket (line 19).** Closed-cell EPDM foam tape 2.5 mm wide, 1.5 mm thick, about 0.45 m.
- **Fixings (line 16).** Stainless pan-head screws: 4 x M3 x 20, 3 x M3 x 10 with washers, 4 x M3 x 8, 2 x M3 x 25 low head, 2 x M2.5 x 6, 2 x M2 x 6 with nuts; 13 M3 and 2 M2.5 brass heat-set inserts; wire in the sizes of section 3.4.1; 0.5 mm foam tape; glue.

## 4. Putting it together

In each picture the parts already fitted are grey and the parts being fitted are in colour, with an arrow showing the way they go in.

### Step 1: heat-set inserts

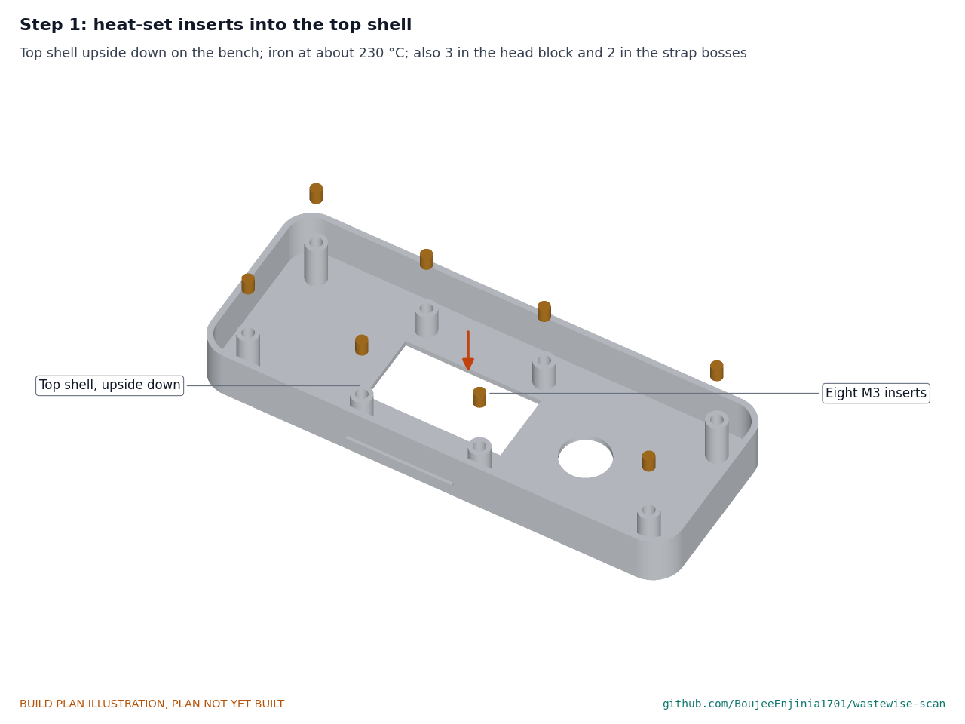
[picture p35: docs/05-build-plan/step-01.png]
Step 1


Top shell upside down on the bench. Press the eight M3 inserts in with the iron at about 230 °C, square and flush. Do the same for the three M3 and two M2.5 inserts in the head block and the two M3 inserts in the strap bosses of the bottom shell, if not already done.

### Step 2: LEDs and photodiode into the head block

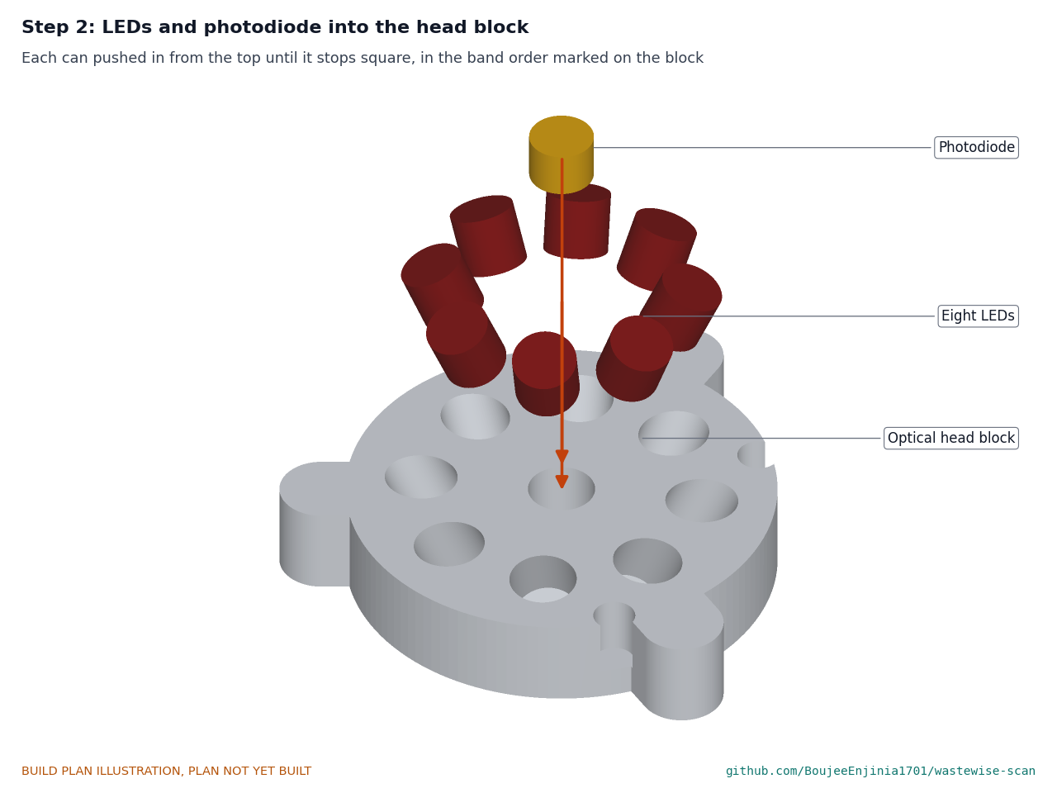
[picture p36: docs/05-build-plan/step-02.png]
Step 2


Each can pushed in from the top until it stops square, in the band order marked on the block.

### Step 3: amplifier board onto the head block

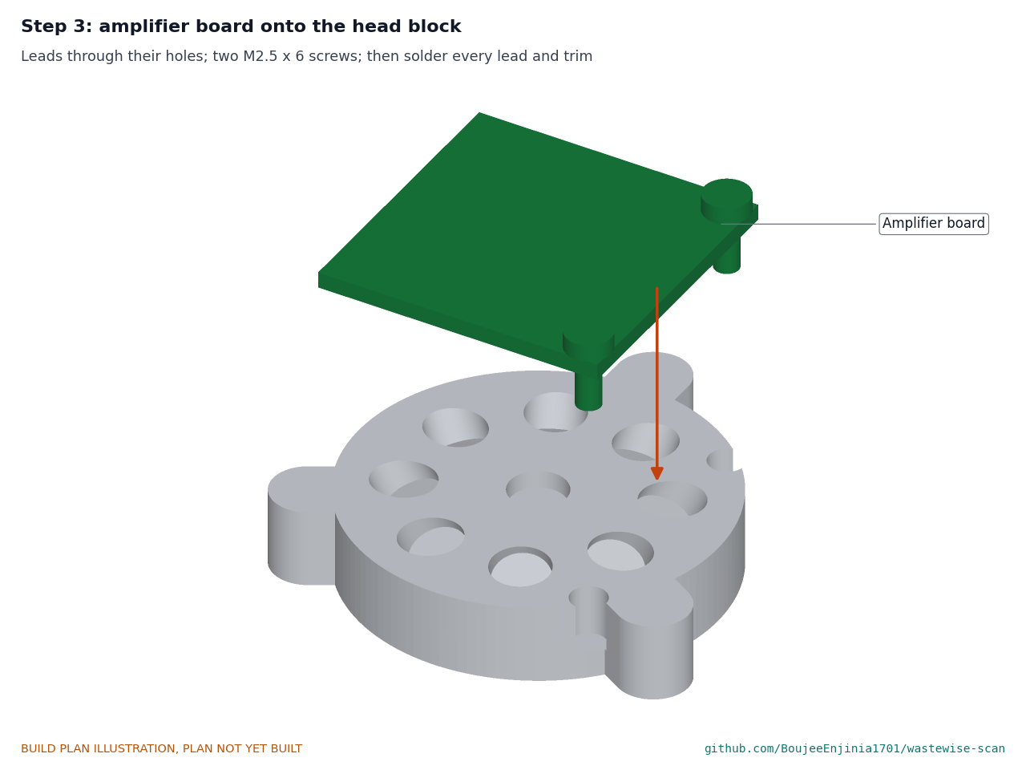
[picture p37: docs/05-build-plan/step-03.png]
Step 3


Thread the leads through their holes, fit two M2.5 x 6 screws, then solder every lead and trim. **Hold point:** the wiring checks of section 3.4 for the board pass before going on.

### Step 4: window and head block into the bottom shell

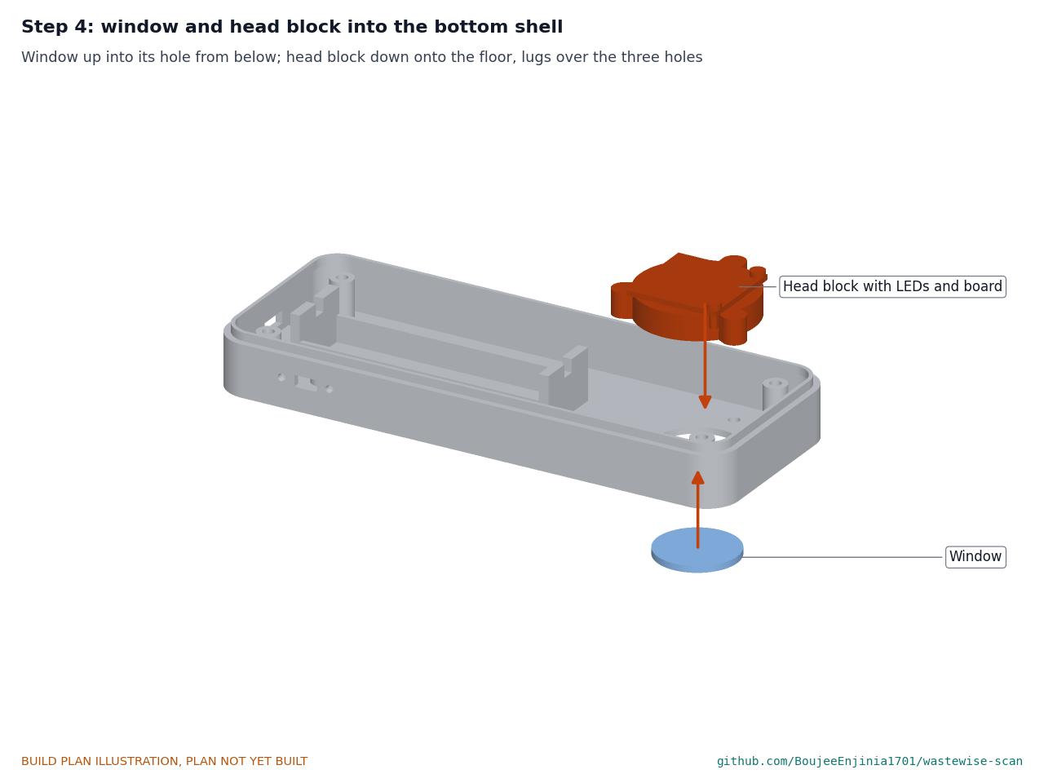
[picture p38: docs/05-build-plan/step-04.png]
Step 4


Clean the window and drop it into its hole from below; stand the head block on the floor with its lugs over the three holes, so the baffle tube rests on the glass.

### Step 5: shroud and head screws from below

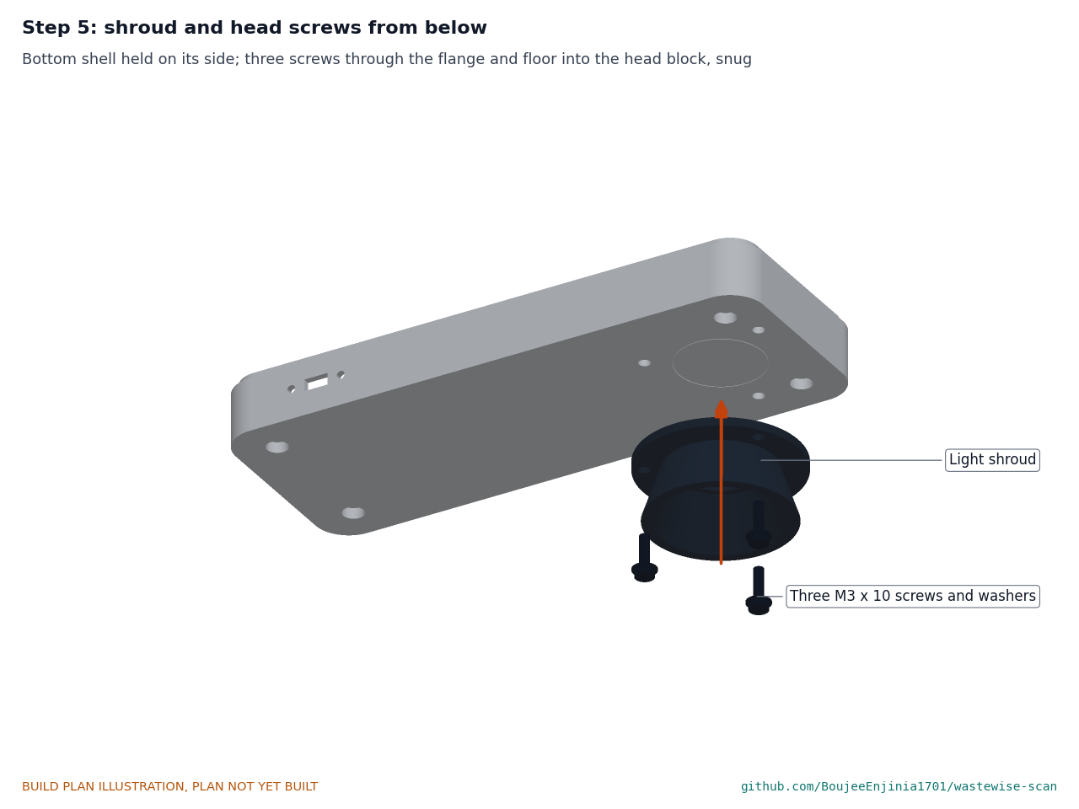
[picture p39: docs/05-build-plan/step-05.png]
Step 5


Hold the bottom shell on its side so the window cannot fall out. Three M3 x 10 screws with washers through the flange and floor into the head block, snug.

### Step 6: cell contacts, USB-C board and slide switch

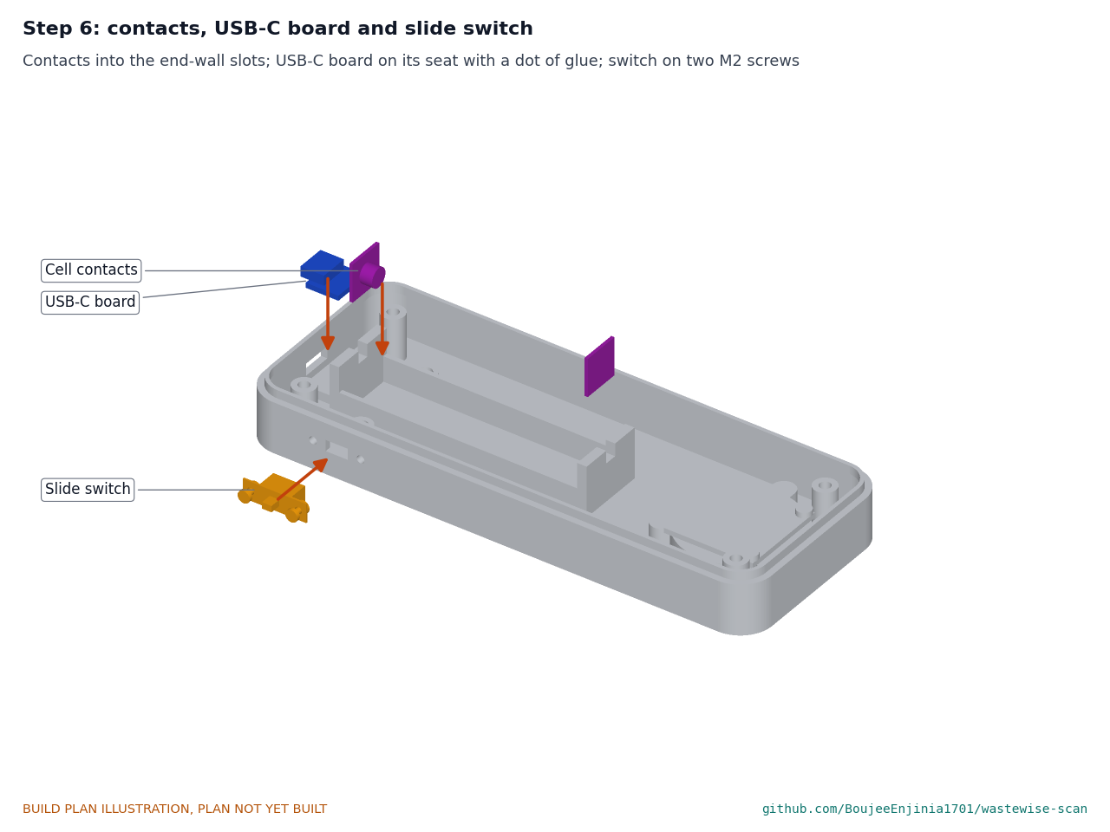
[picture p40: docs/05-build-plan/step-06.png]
Step 6


Push the contacts into the slots in the cradle end walls, spring at the tail end. Glue the USB-C board to its seat with its socket flush in the tail opening. Fit the switch with two M2 x 6 screws from outside and nuts inside.

### Step 7: display board and frame into the top shell

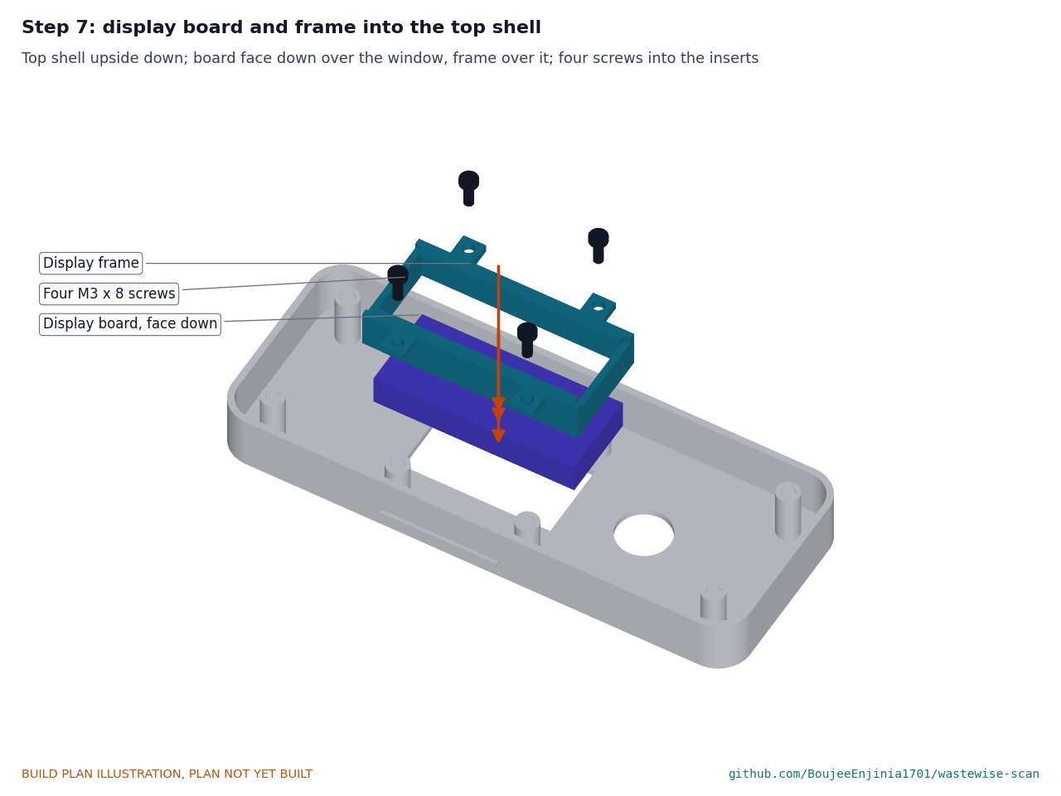
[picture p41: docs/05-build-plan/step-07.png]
Step 7


Top shell upside down. Lay the display board face down over the window, put the frame over it, and fit four M3 x 8 screws through the ears into the inserts.

### Step 8: scan button into the top shell

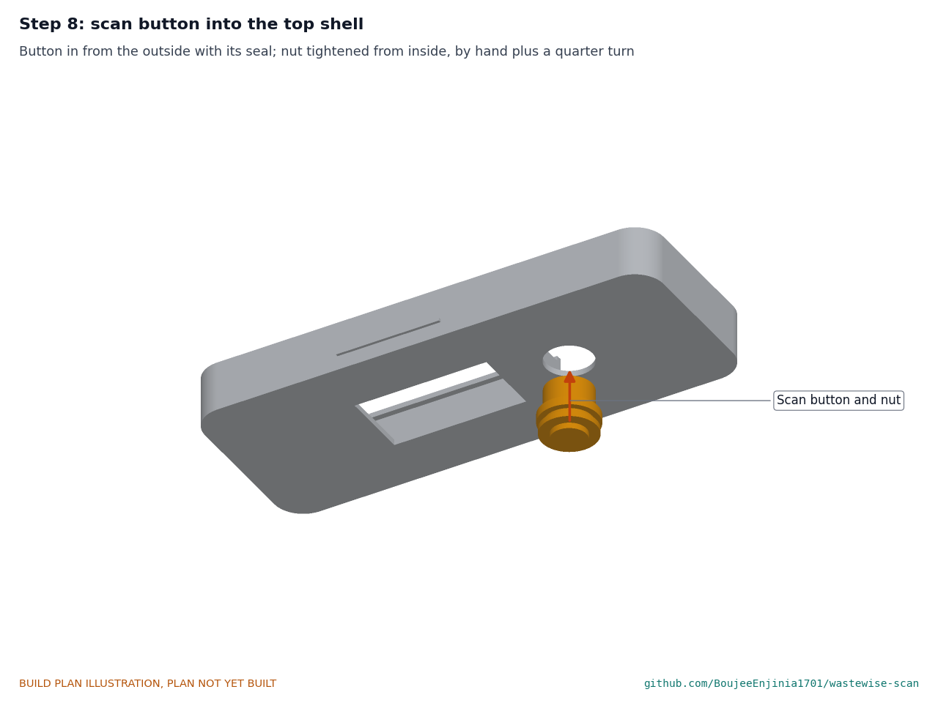
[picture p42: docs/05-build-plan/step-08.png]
Step 8


Button in from outside with its seal under the bezel; nut tightened from inside by hand plus a quarter turn. Then wire everything as section 3.4.1. **Hold point:** safety stops S1 to S4 in section 6 are passed before the cell goes in.

### Step 9: cell and strap

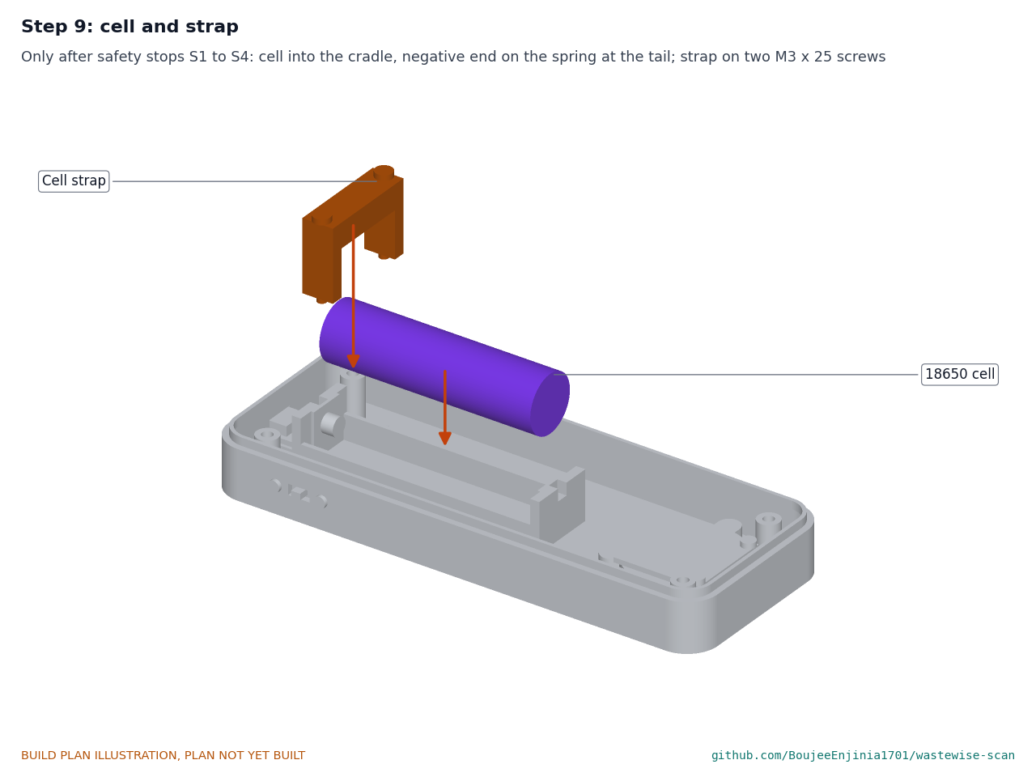
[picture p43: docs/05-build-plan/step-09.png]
Step 9


Switch off. Cell into the cradle with its flat (negative) end against the spring at the tail. Strap over the cell on two M3 x 25 screws.

### Step 10: gasket onto the rim

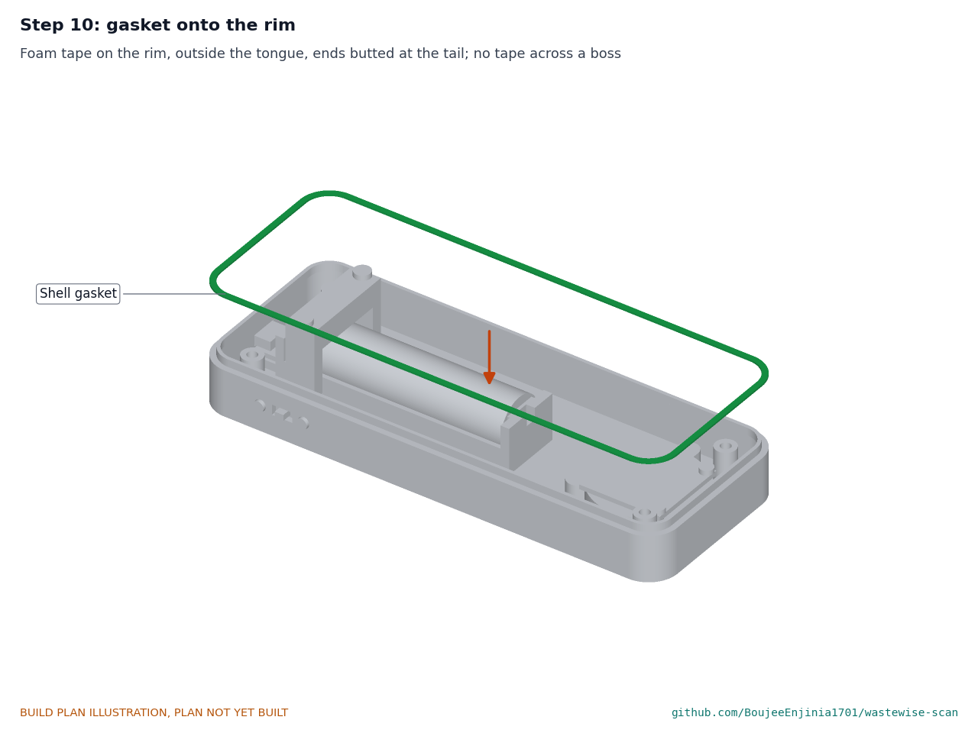
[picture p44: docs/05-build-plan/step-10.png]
Step 10


Stick the foam tape round the rim of the bottom shell, outside the tongue, starting and ending at the tail with the ends butted.

### Step 11: close the shells

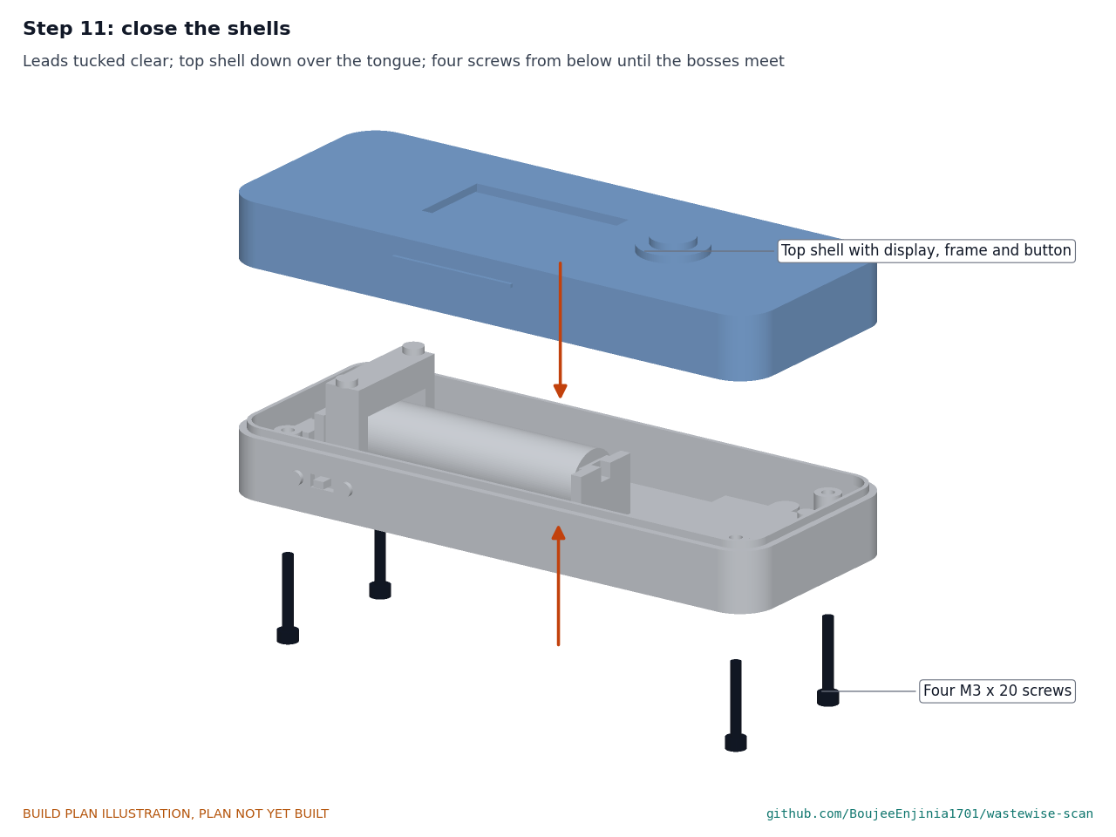
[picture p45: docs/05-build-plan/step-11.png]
Step 11


Fold the leads in clear of the rim, lower the top shell over the tongue and fit four M3 x 20 screws from below, tightening in a cross pattern until the bosses meet.

### Step 12: clip on the sun hood

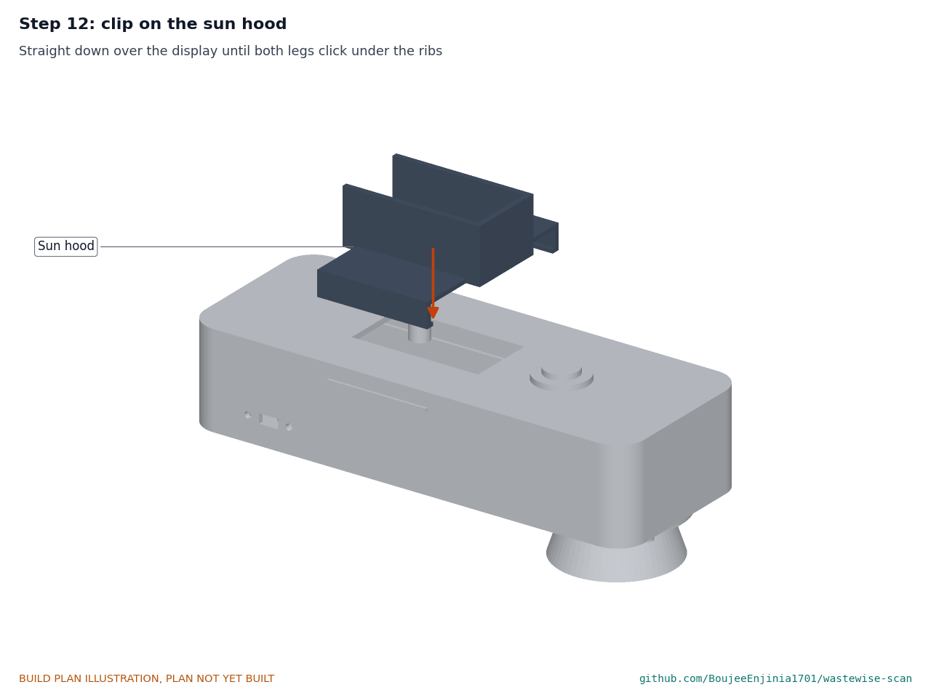
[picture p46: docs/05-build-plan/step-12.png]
Step 12


Straight down over the display until both legs click under the ribs.

### Step 13: calibration cap onto the shroud

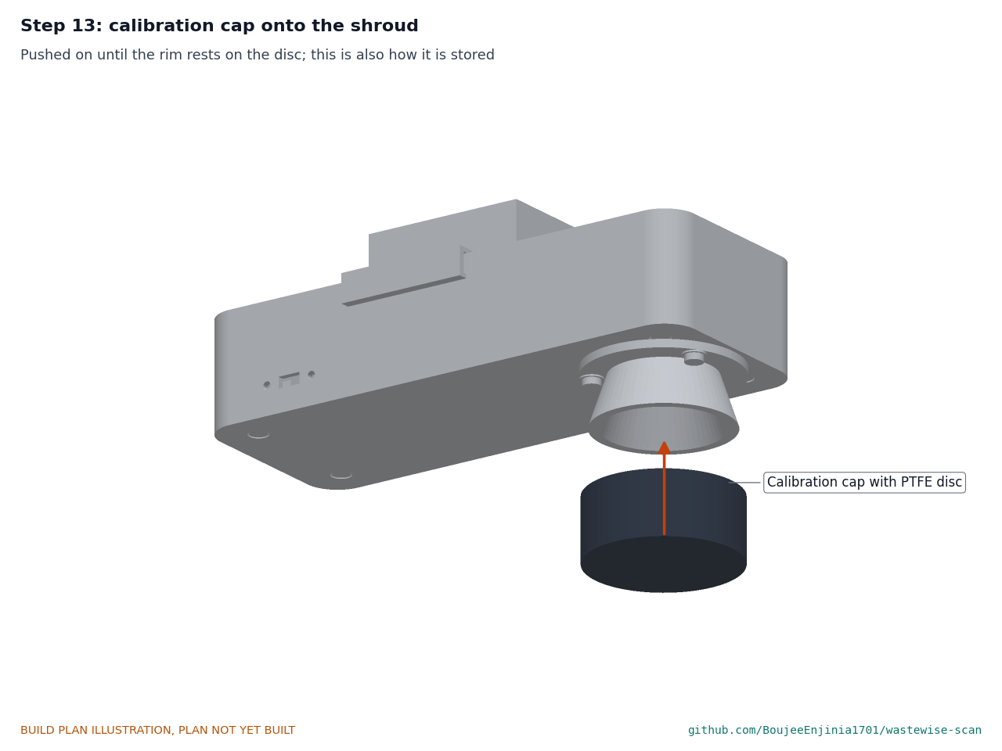
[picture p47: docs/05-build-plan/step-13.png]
Step 13


Push the cap on until the rim rests on the disc. This is how the scanner is stored and how it is calibrated.

## 5. First checks

These are the checks a TRL 4 test report would record; this plan only lists them. Requirement numbers are those of WSC-REQ-001.

*Table 2. First checks.*

| Check | Requirement | How | Pass when |
| --- | --- | --- | --- |
| Shells closed and sealed | R10 | Look along the joint under a lamp; feel for rocking | Even gasket line all round; bosses touching; no rocking |
| Optics seated | R1, R4 | Look into the shroud with the scanner off | Window clean and level; no gap round the flange |
| Mass | R6 | Weigh with and without the cap | Record both; the estimate is 238 g and 258 g |
| LED on-time limit | R14 | Bench supply in place of the cell, 300 mA limit; force one LED switch on from a test pin | The LED goes off within the hardware limit with the firmware stalled |
| First power | R5 | Bench supply at 3.7 V, 300 mA limit, in place of the cell | Current under 200 mA idle; the display starts |
| Charging | R5 | Cell fitted, USB-C supply, switch on; cell temperature checked | Charge current flows and stops at 4.2 V; cell stays under 45 °C |
| Scan time | R2 | Time from button press to result on a white card | 1.5 s or less (0.33 s estimated) |
| White reference | R11 | Calibration with the cap on | Readings on all eight bands, within the converter range |
| Shroud light seal | R4 | Scan an opaque item under a bright lamp, then in shade | Dark readings agree within 0.5 % of the signal |
| Display with the hood | R7 | Outdoors in sun, at several sun angles | Result readable where the hood shades the screen |
| Cap grip | R11 | Shake the scanner with the cap on | The cap stays on |

## 6. Safety stops

Stop at each point. Carry on only when everything listed is true.

- **S1. Before the cell comes into the workshop.** The cell is a protected 18650 from a named maker with a datasheet; voltage between 3.0 and 4.1 V; no dents, swelling or torn wrap. A charging spot is ready on a non-combustible surface (ceramic tile or steel tray) with a fire extinguisher for electrical fires within reach.
- **S2. Before first power.** Every wire checked end to end; the cell contacts read open to every other node; polarity at the contacts checked with a meter, not by wire colour. First power is from a bench supply at 3.7 V with a 300 mA limit in place of the cell.
- **S3. Before the LEDs are driven from the firmware.** The hardware on-time limit is shown to work (section 5). Nobody looks into the window while the scanner is powered; point the shroud at a matte surface.
- **S4. Before the cell goes in.** Switch off; S1 to S3 passed; no bare wire near the cradle or the strap screws.
- **S5. First charge.** Attended the whole time, on the charging spot, scanner open or with the cap off; cell temperature checked every 15 minutes. Stop if the cell passes 45 °C or swells, or the scanner smells hot.
- **S6. Before scanning real waste.** Gloves on; items rinsed; never back sharp, broken or contaminated items with the cap by hand; the scanner is never used to judge whether an item is safe to handle.

## 7. Tools, skills and workspace

**Tools.** 3D printer with a heated bed of at least 170 x 70 mm that prints PETG and TPU (a direct-drive extruder helps with TPU); temperature-controlled soldering iron with a heat-set insert tip; fine solder tip; pin vice and drills 2.2 to 5.6 mm; small files; sharp knife and steel rule; 400 grit paper; small screwdrivers for M2 to M3; wire strippers; multimeter; bench power supply with an adjustable current limit (0 to 6 V, 0 to 1 A); kitchen scale to 1 g; stopwatch; a phone camera that sees infrared.

**Skills.** No certified trade is needed. 3D printing in PETG and TPU, setting heat-set inserts, through-hole soldering on perfboard, safe use of a bench supply and care with lithium-ion cells. All circuits are extra-low voltage: 4.2 V at most at the cell and 5 V at the USB-C input. No mains wiring is part of this build; use a certified USB charger.

**Workspace.** A bench about 1.0 x 0.6 m with good light; a ventilated place for the printer; the charging spot of S1.

**Personal protective equipment.** Safety glasses when soldering, cutting PTFE and trimming leads; heat-resistant care with the iron; nitrile gloves when handling waste items for testing.

## 8. Where the numbers come from

- Model and constructability checks: `cad/src/model.py` (`python cad/src/model.py --check`, 312 checks); STEP and STL exports in `cad/step/` and `cad/stl/`.
- Pictures: `cad/src/build_plan_media.py`, using `.kit/build_views.py`; written to `docs/05-build-plan/` and `cad/drawings/WSC-DWG-101` to `WSC-DWG-109`.
- General arrangement: `cad/drawings/WSC-DWG-001.pdf`, Rev P4.
- Calculations: `docs/04-calcs/01-sizing.md` (WSC-CAL-001 v0.4) and `docs/04-calcs/sizing.py`; mass [A3], drop loads [J2], cell strap [J4], scan time [E2], LED exposure [H2], cost [K1], [K2].
- Bill of materials: `bom/bom.csv`.
- Decisions: `docs/decisions/0004-design-for-construction.md` (WSC-DDR-004), with WSC-DDR-001 to WSC-DDR-003.
- Requirements: `docs/03-requirements.md` (WSC-REQ-001 v0.5).

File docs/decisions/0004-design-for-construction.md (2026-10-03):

---
doc_id: WSC-DDR-004
title: WasteWise Scan design for construction
project: WasteWise Scan
doc_type: Design decision record
version: "0.3"
status: Draft
date: '2026-10-02'
author: Amish Chadha
license: CERN-OHL-S-2.0
revisions:
- version: "0.1"
  date: '2026-10-02'
  author: Amish Chadha
  change: Changes that make the concept physically buildable, with the reason for each; made under Amish's 2026-09-30 instruction and open for his review
- version: "0.2"
  date: '2026-10-02'
  author: Amish Chadha
  change: Accepted by Amish on 2026-10-02 (A2), with A1 decided as option (a)
- version: "0.3"
  date: '2026-10-02'
  author: Amish Chadha
  change: "Decision A1 carried into the model: 2.0 mm shell walls, 238 g and 258 g with the cap; record stays Draft"
---

# 0004: Design for construction

- **Date:** 2026-10-02
- **Status:** accepted. Amish, 2026-10-02: "APPROVED: The open decisions from the last wave (TremorTrace to ZeerBox) came in after the review and aren't on the page either." This approves the recommendation written for each open decision in the design decisions register (WSC-DEC-001 v0.1): the changes in Tables 1 and 2 are accepted as made (A2), and A1 is decided as recorded in Table 3. The record stays Draft.

## Context

On 2026-09-30 Amish asked for every repo to carry an illustrated build plan and wrote: "If you are realising that the design cannot be built as per concept - fix the design assumptions to match and be physically feasible as you draw the illustrations." The TRL 3 model of WasteWise Scan (WSC-DDR-003) showed what the scanner does, and its optics drove the calculation note, but most of its parts had no fixing, two parts overlapped, and two parts could not do their job as drawn. Checking the model with build123d (part overlaps, contacts and clearances) found the twelve problems below. Two of them (the button hole and the USB-C socket) had already been noted in the review of 2026-09-26.

The changes keep what the scanner does: the same body size (160 x 62 x 34 mm), the same optical geometry (detector 22 mm from the item, LEDs on a 20 mm circle tilted 23°, 25 mm window, 18 mm shroud with a 42 mm rim), the same electronics, cell, display, button position, sun hood walls and calibration method. Nothing here changes the pitch or the safety case. Every change is in `cad/src/model.py`, which now runs 312 constructability checks (`python cad/src/model.py --check`): no two of the 25 components overlap, the 25 contacts that must exist do exist, and 11 clearances hold. All 312 pass.

## Decision

*Table 1. Changes made to the model, the BOM and the calculations.*

| # | Problem in the concept | Change made | Why this way |
| --- | --- | --- | --- |
| P1 | The two shells had no fixing, no seal and nothing to line them up, although the BOM listed screws, inserts and a gasket. | Four M3 x 20 screws from below through counterbored bosses at 68 mm each side of centre and 20 mm out, into brass heat-set inserts in matching bosses in the top shell. A 2.5 mm strip of 1.5 mm closed-cell foam on the rim, squeezed to 0.6 mm; the top shell rim starts 0.6 mm higher so the body stays 34 mm tall. A 1.2 x 2.6 mm tongue on the bottom shell locates the top shell. | The bosses meet face to face, so tightening the screws cannot crush the gasket past 0.6 mm. Screws from below keep the top face clean for the display and hood. |
| P2 | The window sat in a 25.4 mm hole through the floor with no ledge: nothing held it in. | The window is pinched between the lip of the shroud flange (22 mm opening) below and the baffle tube of the head block above. | One clamp holds window, shroud and head block. The baffle tube already had to reach the glass to block crosstalk. |
| P3 | The shroud touched the underside of the body with no fixing. | A flange 47 mm across and 2.5 mm thick on the top of the shroud, held by three M3 x 10 screws with washers on a 40 mm circle, through the floor into inserts in the head block. | The circle is large enough that the screw heads and washers clear the cone; the shroud is a wear part and now comes off with three screws. |
| P4 | The LED holder floated 2.5 mm above nothing, and the amplifier board floated 1.2 mm above the holder. | The holder becomes an optical head block, 36 mm across and 7.2 mm tall, standing on the floor with the amplifier board on its top face: three lugs with M3 inserts, the baffle tube built in, a bore that seats the photodiode, LED pockets open at the top for the leads, and two M2.5 inserts for the board. | The block fills the gap the concept left, so every optical part is located by one printed part and clamped by P3. |
| P5 | The baffle bore (5.6 mm) was wider than the photodiode can (5.4 mm), so the can would drop onto the window. | A step 4 mm up the body with a 4 mm aperture below it; the can sits on the step. | The detector plane stays 4 mm up, 22 mm from the item, so the optics calculations are unchanged. |
| P6 | The cell cradle was an open trough sized for a 65 mm cell, with no contacts and nothing to stop the cell lifting or sliding out, while the BOM calls for a protected cell, which is about 69 mm long. | The cradle is printed with the bottom shell: two 1.5 mm rails and two end walls 75 mm apart that carry a bought spring and flat contact pair, for a 69 mm cell. A printed strap (10 x 8 mm PETG) across the cell, on two M3 x 25 screws into inserts in floor bosses. The cell moves 6 mm toward the head end. | The strap carries the 553 N corner-drop load at about 38 MPa, 1.3 times under the strength of printed PETG [J4]. It sits outside the display board, where there is room for its depth. Moving the cell makes room for P7. |
| P7 | The USB-C socket overlapped the tail wall and had no mount. | A small USB-C power board on a printed seat on the floor, its socket mouth in the tail wall opening, fixed with a dot of glue. | Uses the existing opening; no screws needed for a part that is only pushed on. |
| P8 | The display board floated under the ceiling with no fixing. | A printed display frame with lips under the board's long edges and four ears, held by four M3 x 8 screws into inserts in four top shell bosses; 0.5 mm foam tape on the lips. | The board has no mounting holes; the frame holds it by its edges and keeps the lips clear of the cell below. |
| P9 | The 16 mm button sat over a 13 mm hole and overlapped the shell. | A 16.2 mm hole for a panel-mount 16 mm button, with its nut tightened up against the ceiling inside. | Standard panel-mount fitting; seals with the button's own washer. |
| P10 | The slide power switch in BOM line 11 was not in the model. | A panel slide switch on the inside of the right-hand wall, 50 mm behind the centre, actuator through a 7 x 3.5 mm slot, two M2 screws and nuts. | Reachable by the thumb of the hand not holding the grip, and away from the cell and strap. |
| P11 | The sun hood was "clip-on" but had nothing to clip to. | Two clip legs 40 mm long down the sides of the top shell, each with a lip that snaps under a 1 x 1 mm rib printed on the shell side. The plate is trimmed to the legs and the frame round the display opening. | No tools; the walls that shade the screen are unchanged, so the legibility result [I3] stands. Width over the legs is 68.4 mm; R6 allows the hood beyond the body size. |
| P12 | The calibration cap (44 mm bore) was loose on the 42 mm rim, so nothing held it in storage, and it was 1 mm too deep, so the rim never touched the 38 mm PTFE disc, which was also narrower than the rim. | Cap 46 mm across and 20 mm tall with a 41.6 mm bore that grips the TPU rim; PTFE disc 41 mm. Pushed on, the rim rests on the disc and the cap mouth stops 0.5 mm short of the flange. | The white reference is now read at the same distance as an item, which is what the calibration needs, and the cap stays on in a pocket. |

*Table 2. Knock-on changes.*

| Item | Change | Reason |
| --- | --- | --- |
| Mass | 254 g, 274 g with the cap (was 209 g and 229 g) [A3]. R6 (250 g) moves from met to **not met**, 24 g over with the cap. | Bosses, cradle walls, display frame, strap and hood legs add about 25 g of PETG; the fixings allowance rises from 10 to 25 g for 17 steel screws and 15 brass inserts. |
| Cost | BOM lines 1, 3, 7, 9 to 14 and 16 respecified, lines 9, 10 and 16 repriced, lines 17 (display frame), 18 (cell strap) and 19 (shell gasket) added: USD 167.50. Value-engineering target USD 150 (`budget_usd`, unchanged): USD 17.50 over the target [K2]. | Parts added for construction, net USD 3.50. |
| Calculations | WSC-CAL-001 v0.3: masses from the new model volumes, fixings allowance, new line J4 (strap), cost against the value-engineering target [K2]. Optics, power, timing, sunlight and display results unchanged. | Follows the model. |
| Drawing | WSC-DWG-001 Rev P4; making sketches WSC-DWG-101 to 109 added. | Follows the model. |
| Documents | WSC-PRC-001 v0.5 and WSC-REQ-001 v0.5: mass, cost, components and R6 and R12 status updated. | Follows the model. |

*Table 3. Decided by Amish, 2026-10-02.*

| # | Question | Options | Recommendation |
| --- | --- | --- | --- |
| A1 | R6 is now not met: 274 g with the cap against 250 g (254 g without it). | (a) shell walls 2.0 mm instead of 2.5 mm, keeping the bosses and ribs (saves about 20 g; the drop case R10 is then checked at TRL 4); (b) count R6 without the cap, which stores on the shroud but can be left in a pocket (254 g, still 4 g over); (c) accept about 275 g and restate R6. | (a), and weigh the first prototype at TRL 4 before deciding on (b) or (c). **Decided by Amish, 2026-10-02: (a).** R6 stays not met (about 254 g with the cap, 4 g over) until the prototype is weighed; (b) is not used because the cap is carried for backing clear items. The 2.0 mm walls are now in the model (v0.3 of this record): 238 g, 258 g with the cap, 8 g over, because the shells saved 17 g rather than about 20 g (WSC-CAL-001 v0.4, A3). |
| A2 | Whether to accept the changes P1 to P12 as the constructable design. | Accept; accept with changes; reject. | Accept. **Decided by Amish, 2026-10-02: accepted as made.** |

*Table 4. Carried into the model, 2026-10-02 (A1).*

| Item | Change | Reason |
| --- | --- | --- |
| Shell walls | Both shells 2.0 mm (was 2.5 mm); bosses, ribs, tongue and gasket unchanged. The model's 314 checks pass, including a new check that the wall is at least 1.6 mm and the tongue fits inside it. | Decision A1, option (a) |
| Parts that follow | The display frame is 12 mm tall (was 11.5 mm) because the ceiling is 0.5 mm higher; the cell strap legs stand 0.5 mm taller; the shell prints with five perimeters. | The thinner floor and ceiling |
| Mass | Top shell 42 g, bottom shell 47 g (were 51 g and 56 g); scanner 238 g, 258 g with the cap [A3]. | Model volumes |
| Drawings | WSC-DWG-001 Rev P5; making sketches WSC-DWG-101 and 105 and the shell pictures regenerated. | Follows the model |
| Drop case | Cell load unchanged (about 550 N); thin shell corners checked in the drop test at TRL 4 (R10). | Decision A1 |

## Consequences

- `design_state: constructable` in `project.yaml`. The build plan WSC-BLD-001 shows every component and step in pictures generated from the model (`cad/src/build_plan_media.py`).
- Requirement status (WSC-CAL-001 v0.3): 1 not met (R6, mass), 3 at risk (R1, R7, R13), 2 not verifiable at TRL 3 (R3, R10), 7 met; R12 is reported against the value-engineering target, USD 17.50 over.
- The photoreal renders (`media/render-*.png`), `media/card.png` and `media/social-preview.png` and the appearance model `cad/src/product_model.py` differ from the constructable design where it shows from outside: the hood has no clip legs and the shell sides no ribs, and the cap is the concept's 48 x 24 mm. Their shroud flange and screw heads were appearance details that the design now carries. They need regenerating on Amish's Mac, where Blender is.
- Open questions about parts still to be bought are listed in the design decisions register, WSC-DEC-001.

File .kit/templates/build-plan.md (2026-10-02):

---
doc_id: PRJ-BLD-001
title: Project prototype build plan
project: Project name
doc_type: Build plan
version: "0.1"
status: Draft
date: YYYY-MM-DD
author: Amish Chadha
license: CERN-OHL-S-2.0
revisions:
  - version: "0.1"
    date: YYYY-MM-DD
    author: Amish Chadha
    change: First build plan; design made constructable
---

# Project prototype build plan

**Plan, not yet built.** How to build the first proof-of-concept prototype, component by component. Building and testing to it is TRL 4 work. Decisions still to be made are kept in the design decisions register (`docs/06-design-decisions.md`), not here.

## 1. What you are building

Every component, pulled apart and numbered in build order

One short paragraph: what the prototype is, how many components, which are made and which are bought, and the main ways they are made.

## 2. What changed to make it buildable

| Component | The concept had | The buildable design has | Why |
| --- | --- | --- | --- |

## 3. Making the components

### 3.1 Component name

Making sketch

**What it is and what it is made from.**

**How to make it.**

1. Mark out ...
2. Cut ...

**How it fits the parts next to it.**

Close-up of the joint

**Check before moving on.**

## 4. Putting it together

### Step 1: ...

Step 1

## 5. First checks

| Check | Requirement | How | Pass when |
| --- | --- | --- | --- |

## 6. Safety stops

## 7. Tools, skills and workspace

## 8. Where the numbers come from

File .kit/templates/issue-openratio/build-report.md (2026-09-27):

---
name: Build report
about: Tell us what happened when you built, printed or tested part of this design
title: "Build report: "
labels: build-report
---

This is a research and educational prototype, not a medical device. It is a TRL 3 concept and is not released for fabrication. If you build any part of it, you do so at your own risk. Reports help everyone.

**What you built** (part, sub-assembly or test)

**Materials, tools and settings**

**What worked**

**What did not work, with photos or measurements if you have them**

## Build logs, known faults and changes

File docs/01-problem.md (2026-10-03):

---
doc_id: WSC-PRB-001
title: WasteWise Scan problem statement
project: WasteWise Scan
doc_type: Problem statement
version: "0.4"
status: Draft
date: '2026-10-02'
author: Amish Chadha
license: CERN-OHL-S-2.0
revisions:
- version: "0.1"
  date: '2026-09-24'
  author: Amish Chadha
  change: Initial scaffold
- version: "0.2"
  date: '2026-09-25'
  author: Amish Chadha
  change: Populate to TRL 2 (problem, users, context, constraints, prior work)
- version: "0.3"
  date: '2026-09-25'
  author: Amish Chadha
  change: Citations checked and corrected (Neo et al. year, WIEGO wording, ASTM and WRAP links, trinamiX source); cost constraint per WSC-DDR-001 D2; open questions updated
- version: "0.4"
  date: '2026-10-02'
  author: Amish Chadha
  change: Partner, region and price-target questions answered by Amish's decisions of 2026-10-02 (WSC-DEC-001)
---

# WasteWise Scan problem statement

Resin type sets the price of a plastic item, but the people who sort most of the world's recycled plastic have no affordable way to measure it. They rely on the molded resin code, touch, sound and burn tests, and a wrong call either loses value or contaminates a whole bale.

## The problem

Mixed plastic is worth little; plastic sorted by resin (PET, HDPE, PP, PS, PVC) is worth several times more to a recycler, and a small share of the wrong resin can spoil a batch. PVC in a PET stream is the classic example, because it degrades at PET processing temperatures and discolors the melt. The informal sector carries most of this sorting work: one widely cited model estimates that the informal sector collects about 58 % of the plastic waste collected for recycling worldwide ([Lau et al. 2020, *Science*](https://doi.org/10.1126/science.aba9475), as cited in [ISWA, *A Seat at the Table*, 2022](https://www.iswa.org/wp-content/uploads/2022/09/A-Seat-at-the-Table.pdf)). Waste pickers' earnings vary widely between cities, and in many places they subsist on meager returns ([WIEGO, waste pickers](https://www.wiego.org/informal-economy/occupational-groups/waste-pickers)).

Sorting by eye is unreliable. The resin identification code molded into an item ([ASTM D7611/D7611M-21, *Standard Practice for Coding Plastic Manufactured Articles for Resin Identification*](https://store.astm.org/d7611_d7611m-21.html)) is often missing, worn or wrong, and many items look alike: a clear PP tray and a clear PET tray, or a white HDPE bottle and a white PP bottle. An ordinary camera sees color and shape, not chemistry, which is why the image model in the sibling project WasteWise-ml will struggle with exactly these pairs.

Industry solves this with near-infrared (NIR) spectroscopy. Polymers absorb short-wave infrared light at wavelengths set by their chemical bonds, mainly overtones of the C-H stretch near 1,150 to 1,250 nm and 1,650 to 1,750 nm, and those signatures differ between resins ([Neo et al. 2022, review, *Resources, Conservation and Recycling* 180](https://doi.org/10.1016/j.resconrec.2022.106217)). Materials recovery facilities use NIR optical sorters costing hundreds of thousands of dollars, and handheld NIR spectrometers for plastics (for example the [trinamiX mobile NIR system](https://trinamixsensing.com/products/mobile-nir-spectroscopy/), which works at 1,450 to 2,450 nm according to its [fact sheet](https://www.lc-oe.com/pdf/3900/factsheet_trinamix_nir_spectrometer%20vv21_10.pdf)) cost thousands of dollars plus subscriptions (price level is an estimate). None of this is within reach of a waste picker, a cooperative or a small aggregator.

## Prior work

- **Plastic Scanner** ([plasticscanner.com](https://plasticscanner.com/), [GitHub](https://github.com/Plastic-Scanner)), an open-source handheld that began as Jerry de Vos's graduation project at TU Delft ([Raspberry Pi news](https://www.raspberrypi.com/news/award-winning-plastic-scanner/)), shines discrete NIR LEDs from 850 to 1,650 nm on the item one at a time and reads the reflection with a single InGaAs photodiode ([Hackaday, 2021](https://hackaday.com/2021/12/13/an-open-source-detector-for-identifying-plastics/)). It is the closest prior work and shows that a discrete-band approach can separate common resins. WasteWise Scan builds on the same principle and adds a sunlight-readable display, local price grades, logging and a hand-off to WasteWise-ml.
- **Low-cost multispectral chips** such as the ams OSRAM AS7265x (18 channels from about 410 to 940 nm; [SparkFun Triad board](https://www.sparkfun.com/products/15050)) are cheap and easy to use, but stop short of the main polymer absorption bands. Above 940 nm only weak third-overtone features are available, so resin identification with such a chip alone is at risk (see WSC-PRC-001).
- **Black plastics** are a known limit of NIR sorting: most black packaging is colored with carbon black pigments, which do not allow it to be sorted by NIR ([WRAP, recyclability of black plastic packaging](https://www.wrap.ngo/resources/report/recyclability-black-plastic-packaging)).

## Users and context

| User | Need | Context |
| --- | --- | --- |
| Waste picker | Know which pile an item belongs in, and what it is worth, without reading or guessing | Streets, dumpsites and transfer points; sun, dust, rain; no power at work; low-cost phone at most |
| Cooperative or aggregator sorter | Check disputed items quickly; keep bales clean; train new members | Sorting shed or yard, hundreds to thousands of items per shift |
| Small recycler or buyer | Spot-check incoming bales before paying; reject PVC in PET | Receiving bay |
| Trainer, NGO or researcher | A shared, open reference for resin identification and a log of what is collected | Workshops, studies, WasteWise-ml data collection |

## Constraints

- Garage-buildable prototype from off-the-shelf modules and 3D-printed parts. $150 USD in parts is the volume target; the first prototype is accepted at about $163 (Amish, 2026-09-25, WSC-DDR-001 D2).
- One hand, one button, result in about a second, readable in direct sunlight.
- Works offline for a full shift with no mains power at the work site; charges from USB.
- Usable by people with limited literacy: color, icon and resin code on screen, local language.
- Rugged enough for dusty, wet and rough handling.
- Price grades are set locally by the user or cooperative, not by a remote service.

## Out of scope

- Black and very dark plastics (reported as unknown, not identified).
- Hazardous, medical or chemical-container waste. The scanner must never be used to decide whether such waste is safe to handle.
- Conveyor or automatic sorting (a possible later project).
- Identifying additives, food-contact grade or contamination.

## Open questions

- Which users to work with first, and through which partner (a waste picker organization, a cooperative, or a university lab)? Decided by Amish, 2026-10-02 (WSC-DEC-001): a member-owned waste picker cooperative; the first candidate to approach is SWaCH in Pune, India.
- Which region's resin mix and price structure should set the first classifier and price table? Decided by Amish, 2026-10-02: Pune, India (WSC-DEC-001).
- Is the $150 volume target the price a cooperative would pay, or should the target be lower for individual pickers? Decided by Amish, 2026-10-02: it is the price a cooperative pays for a shared scanner (WSC-DEC-001).

## User research and co-design

This design is for communities the author is not part of, so requirements come from the people who will use it.

- [ ] Identify a local partner organization (Helpful Engineering network, NGO or university)
- [ ] Run co-design sessions with intended users; record who, where and what was learned
- [ ] Validate load, distance, terrain and cost assumptions in the field
- [ ] Revise requirements (REQ) from findings before freezing the design

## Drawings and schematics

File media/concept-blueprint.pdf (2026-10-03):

CONCEPT, NOT FOR FABRICATION | WasteWise Scan · github.com/BoujeeEnjinia1701/wastewise-scan

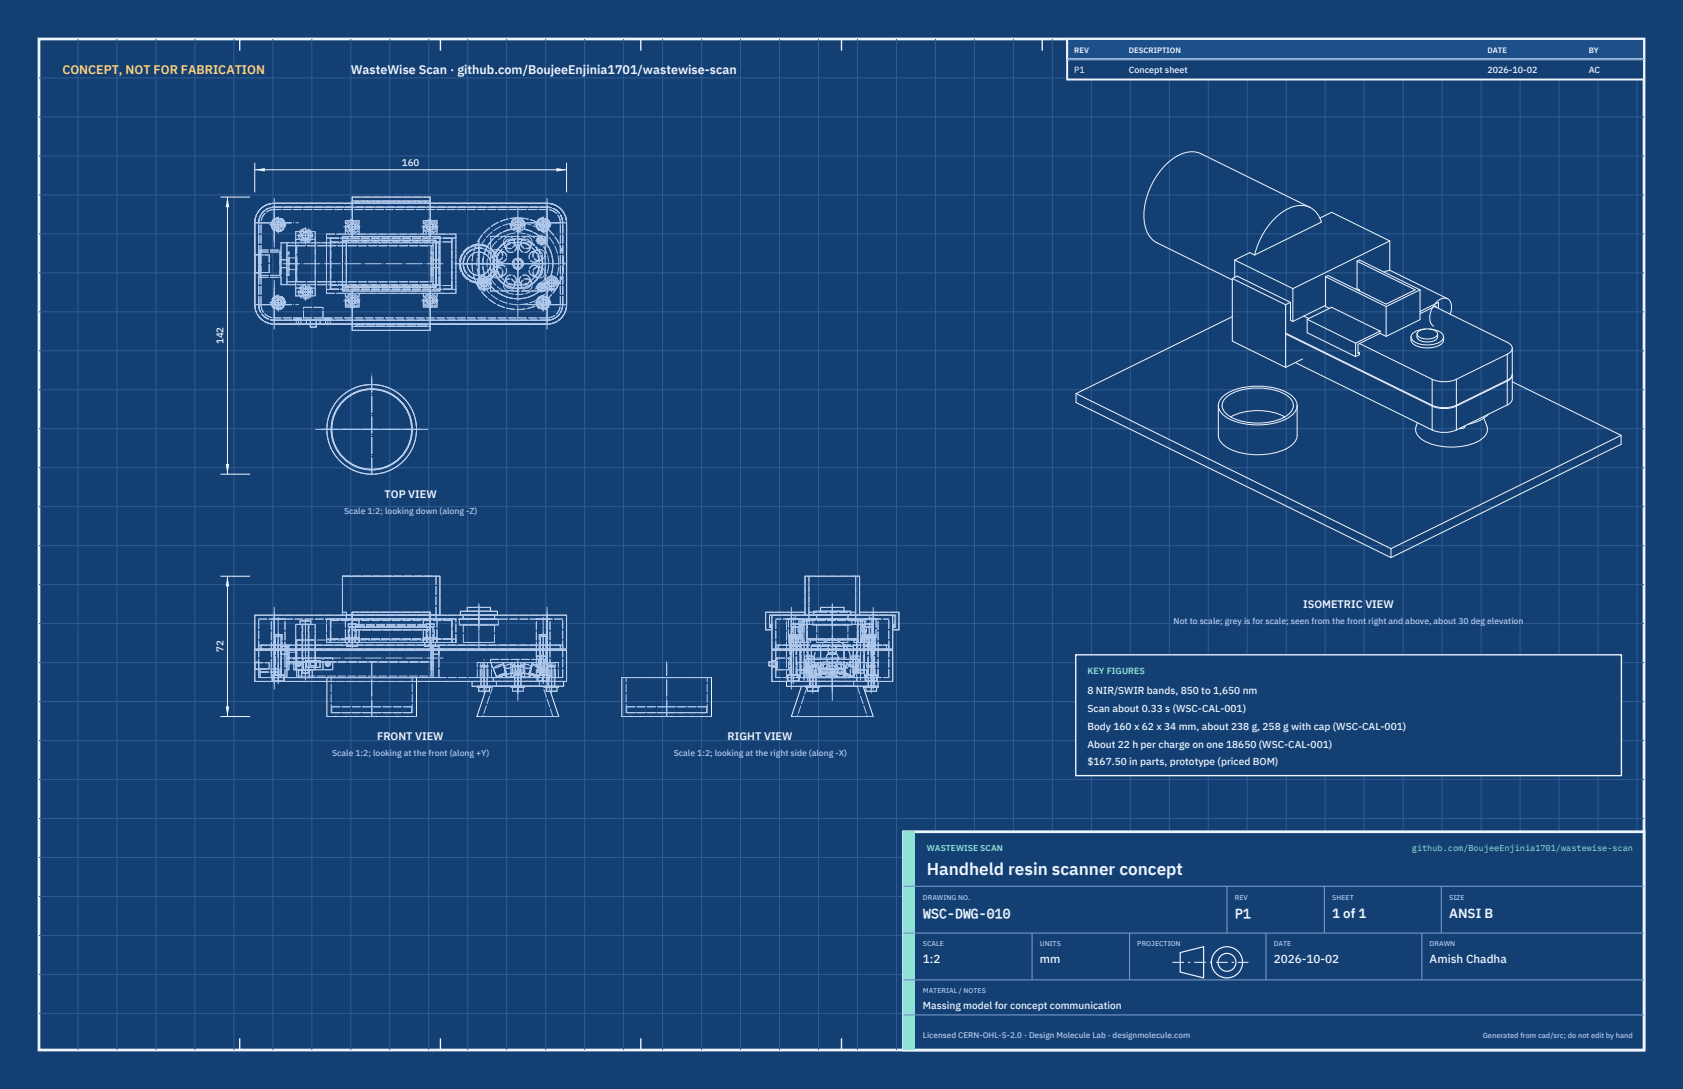
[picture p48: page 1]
FRONT VIEW; TOP VIEW; RIGHT VIEW; ISOMETRIC VIEW; REV; DESCRIPTION; DATE; Concept sheet; WASTEWISE SCAN; github.com/BoujeeEnjinia1701/wastewise-scan; DRAWING NO. WSC-DWG-010; REV P1; SHEET 1 of 1; SIZE ANSI B; SCALE 1:2; UNITS mm; PROJECTION; DRAWN Amish Chadha; Licensed CERN-OHL-S-2.0 · Design Molecule Lab · designmolecule.com; Generated from cad/src; do not edit by hand

Scale 1:2; looking down (along -Z)

Not to scale; grey is for scale; seen from the front right and above, about 30 deg elevation

KEY FIGURES
8 NIR/SWIR bands, 850 to 1,650 nm
Scan about 0.33 s (WSC-CAL-001)
Body 160 x 62 x 34 mm, about 238 g, 258 g with cap (WSC-CAL-001)
About 22 h per charge on one 18650 (WSC-CAL-001)
$167.50 in parts, prototype (priced BOM)

Scale 1:2; looking at the front (along +Y)

Scale 1:2; looking at the right side (along -X)

Handheld resin scanner concept

MATERIAL / NOTES
Massing model for concept communication

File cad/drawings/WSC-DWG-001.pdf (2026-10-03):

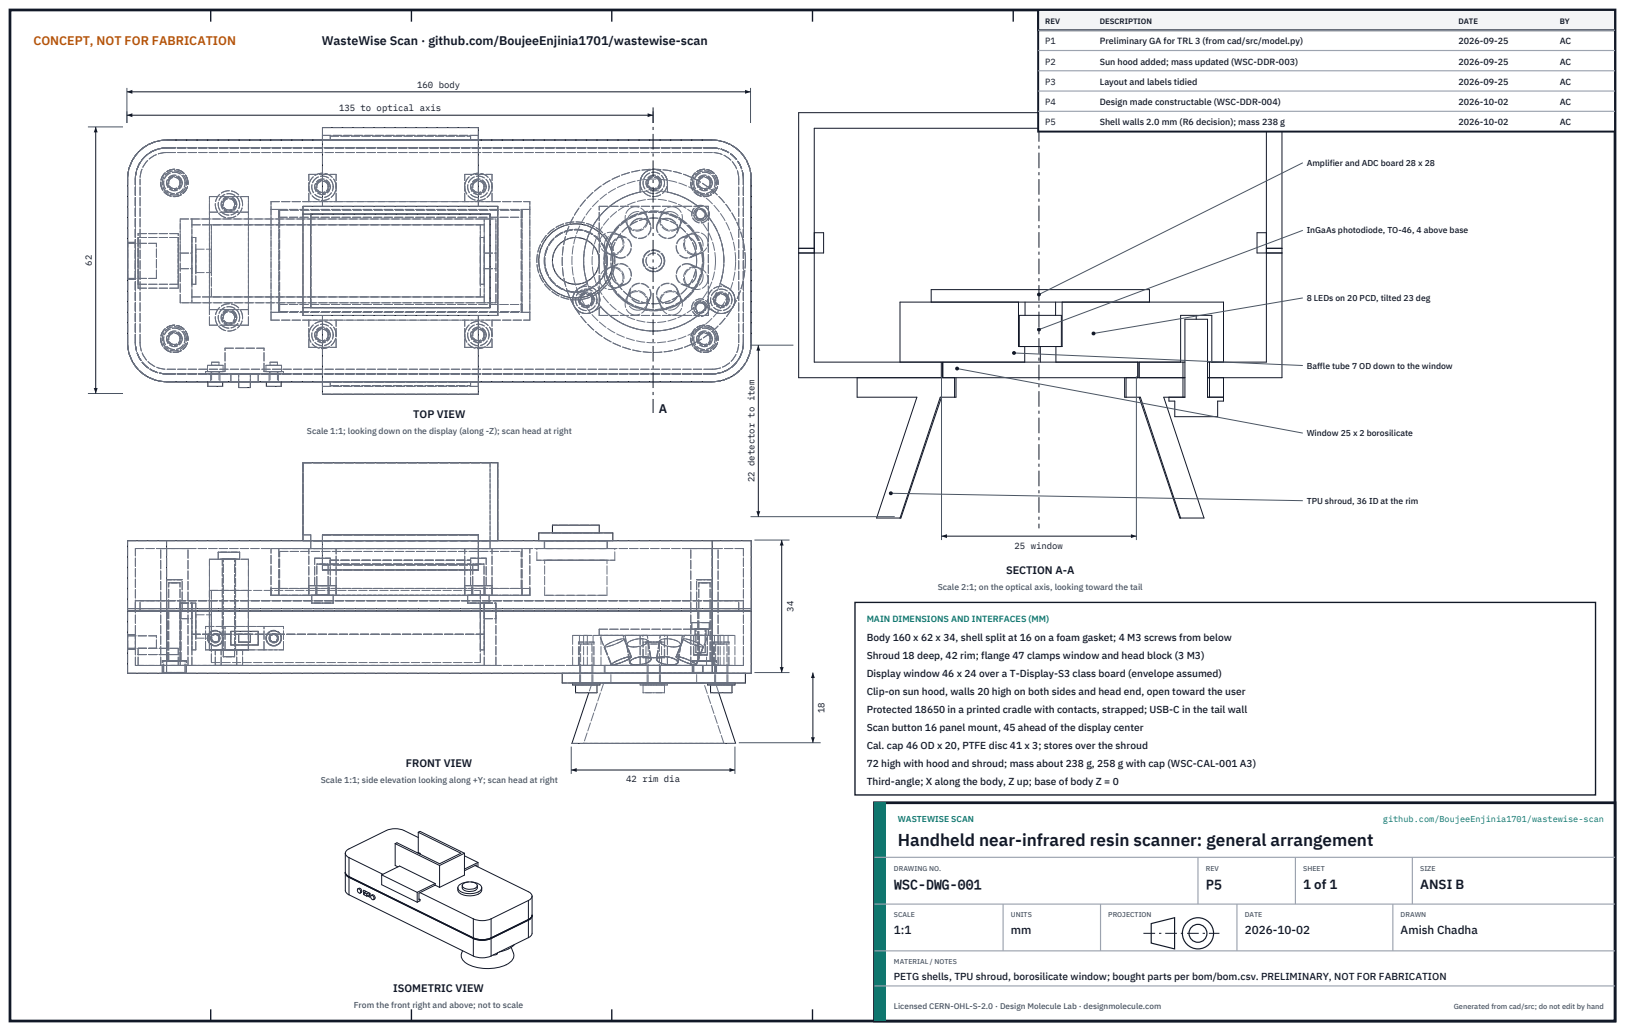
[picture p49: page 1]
CONCEPT, NOT FOR FABRICATION; WasteWise Scan · github.com/BoujeeEnjinia1701/wastewise-scan; TOP VIEW; FRONT VIEW; 160 body; 42 rim dia; SECTION A-A; 25 window; Window 25 x 2 borosilicate; ISOMETRIC VIEW; REV; DESCRIPTION; DATE; Preliminary GA for TRL 3 (from cad/src/model.py); Sun hood added; mass updated (WSC-DDR-003); Layout and labels tidied; Design made constructable (WSC-DDR-004); Shell walls 2.0 mm (R6 decision); mass 238 g; WASTEWISE SCAN; github.com/BoujeeEnjinia1701/wastewise-scan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

135 to optical axis

Amplifier and ADC board 28 x 28

InGaAs photodiode, TO-46, 4 above base

8 LEDs on 20 PCD, tilted 23 deg

Baffle tube 7 OD down to the window

22 detector to item

Scale 1:1; looking down on the display (along -Z); scan head at right

TPU shroud, 36 ID at the rim

Scale 2:1; on the optical axis, looking toward the tail

MAIN DIMENSIONS AND INTERFACES (MM)
Body 160 x 62 x 34, shell split at 16 on a foam gasket; 4 M3 screws from below
Shroud 18 deep, 42 rim; flange 47 clamps window and head block (3 M3)
Display window 46 x 24 over a T-Display-S3 class board (envelope assumed)
Clip-on sun hood, walls 20 high on both sides and head end, open toward the user
Protected 18650 in a printed cradle with contacts, strapped; USB-C in the tail wall
Scan button 16 panel mount, 45 ahead of the display center
Cal. cap 46 OD x 20, PTFE disc 41 x 3; stores over the shroud
72 high with hood and shroud; mass about 238 g, 258 g with cap (WSC-CAL-001 A3)
Third-angle; X along the body, Z up; base of body Z = 0

Scale 1:1; side elevation looking along +Y; scan head at right

Handheld near-infrared resin scanner: general arrangement

MATERIAL / NOTES
PETG shells, TPU shroud, borosilicate window; bought parts per bom/bom.csv. PRELIMINARY, NOT FOR FABRICATION

From the front right and above; not to scale

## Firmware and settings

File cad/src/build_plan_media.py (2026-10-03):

"""WasteWise Scan prototype build plan pictures (WSC-BLD-001, STANDARDS section 18).

Run from the repo root:  python cad/src/build_plan_media.py [overview|sheets|joints|steps|wiring ...]
A single picture can be drawn with  python cad/src/build_plan_media.py steps 5  (or joints 3, sheets 104).
With no argument it draws everything. Every picture is drawn from cad/src/model.py
(build_components), so the pictures and the model never disagree:
    docs/05-build-plan/overview.png        every component pulled apart, numbered in build order
    cad/drawings/WSC-DWG-101 to 109        making sketches for the printed and cut components
    docs/05-build-plan/joint-NN.png        close-ups of the joints that need explaining
    docs/05-build-plan/step-NN.png         one picture per assembly step
    docs/05-build-plan/wiring.png          block-level wiring with wire sizes (matplotlib)
Uses .kit/build_views.py. BUILD PLAN ILLUSTRATION, PLAN NOT YET BUILT.
"""
import sys
from pathlib import Path

ROOT = Path(__file__).resolve().parents[2]
sys.path[:0] = [str(ROOT / ".kit"), str(ROOT / "cad" / "src")]
import build_views as bv  # noqa: E402
from build_views import Part  # noqa: E402
from model import PARAMS as P, build_components, derived, cap_parts, cap_on_shroud  # noqa: E402

OUT = ROOT / "docs" / "05-build-plan"
DWG = ROOT / "cad" / "drawings"
DATE = "2026-10-02"
D = derived(P)
C = build_components(P)
CAP = cap_on_shroud(P)
HX = P["head_x"]

COL = {"bottom": "#9CA3AF", "top": "#CBD5E1", "head": "#C2410C", "leds": "#7F1D1D", "pd": "#D4A017",
       "afe": "#15803D", "window": "#93C5FD", "shroud": "#1F2937", "contacts": "#A21CAF", "usb": "#1D4ED8",
       "switch": "#F59E0B", "board": "#4338CA", "frame": "#0E7490", "button": "#F59E0B", "cell": "#7C3AED",
       "strap": "#B45309", "gasket": "#16A34A", "screw": "#111827", "hood": "#475569", "cap": "#374151",
       "ptfe": "#E5E7EB", "insert": "#B7791F"}


def _fuse(shapes):
    out = None
    for s in shapes:
        out = s if out is None else out + s
    return out


S = lambda *ks: _fuse([C[k] for k in ks])  # noqa: E731


def part(name, shape, color, explode=(0, 0, 0), alpha=1.0):
    return Part(name, shape, color, None, tuple(explode), alpha)


def inserts(which):
    """Brass heat-set inserts (drawn for the pictures; in the model they are the holes in the bosses)."""
    from build123d import Cylinder, Pos
    pts = []
    sx, sy = P["shell_screw_xy"]
    if which == "top":
        pts = [(a * sx, b * sy, P["z_split"] + 0.2) for a in (1, -1) for b in (1, -1)]
        pts += [(fx, s * fy, P["frame_z0"] + 2.6) for fx, fy in P["frame_screws"] for s in (1, -1)]
    elif which == "head":
        pts = [(x, y, D["holder_z0"] + 0.1) for x, y in D["head_screws"]]
    elif which == "strap":
        pts = [(P["strap_x"], s * D["strap_y"], P["wall"] + 0.1) for s in (1, -1)]
    return _fuse([Pos(x, y, z + 2.5) * Cylinder(1.95, 5.0) for x, y, z in pts])


# ----------------------------------------------------------------- named components, in build order
def made():
    return {
        "bottom": part("Bottom shell with cradle", C["bottom_shell"], COL["bottom"]),
        "top": part("Top shell", C["top_shell"], COL["top"]),
        "head": part("Optical head block", C["led_holder"], COL["head"]),
        "leds": part("Eight LEDs", C["leds"], COL["leds"]),
        "pd": part("Photodiode", C["photodiode"], COL["pd"]),
        "afe": part("Amplifier board", S("afe_board", "afe_screws"), COL["afe"]),
        "window": part("Window", C["window"], COL["window"]),
        "shroud": part("Light shroud", C["shroud"], COL["shroud"]),
        "contacts": part("Cell contacts", C["cell_contacts"], COL["contacts"]),
        "usb": part("USB-C board", C["usb_board"], COL["usb"]),
        "switch": part("Slide switch", S("switch", "switch_screws"), COL["switch"]),
        "board": part("Display board", C["display_board"], COL["board"]),
        "frame": part("Display frame", S("display_frame", "frame_screws"), COL["frame"]),
        "button": part("Scan button", C["button"], COL["button"]),
        "cell": part("18650 cell", C["cell"], COL["cell"]),
        "strap": part("Cell strap", S("cell_strap", "strap_screws"), COL["strap"]),
        "gasket": part("Shell gasket", C["gasket"], COL["gasket"]),
        "screws": part("Shell and shroud screws", S("shell_screws", "head_screws"), COL["screw"]),
        "hood": part("Sun hood", C["sun_hood"], COL["hood"]),
        "cap": part("Calibration cap", CAP["cal_cap"], COL["cap"]),
        "ptfe": part("PTFE reference disc", CAP["ptfe_disc"], COL["ptfe"]),
    }


ORDER = ["bottom", "top", "head", "leds", "pd", "afe", "window", "shroud", "contacts", "usb", "switch", "board",
         "frame", "button", "cell", "strap", "gasket", "screws", "hood", "cap", "ptfe"]


# ----------------------------------------------------------------- overview
def overview():
    M = made()
    off = {"bottom": (0, 0, 0), "top": (0, 0, 170), "head": (0, 0, 40), "leds": (0, 0, 62), "pd": (28, 0, 75),
           "afe": (0, 0, 98), "window": (0, 0, -30), "shroud": (0, 0, -62), "contacts": (0, -70, 20),
           "usb": (-30, -70, 0), "switch": (0, -70, -10), "board": (0, 0, 125), "frame": (0, 0, 105),
           "button": (0, 0, 215), "cell": (0, 0, 45), "strap": (0, 0, 75), "gasket": (0, 0, 145),
           "screws": (0, -75, -95), "hood": (0, 0, 240), "cap": (0, 0, -185), "ptfe": (0, 0, -128)}
    parts = []
    for k in ORDER:
        p = M[k]
        p.explode = off[k]
        parts.append(p)
    return bv.overview(parts, OUT / "overview.png", "WasteWise Scan prototype: every component, pulled apart",
                       subtitle="Numbered in build order. Seen from the front right and above; the scan head is at the right",
                       elev=20, azim=-62, size=(11, 9), dpi=150, key=True)


# ----------------------------------------------------------------- making sketches
def sheets(only=None):
    from build123d import Pos, Rot
    M = made()
    base = dict(project="WasteWise Scan", date=DATE)
    out = []

    def want(n):
        return only is None or str(n) in only

    if want(101):
        out.append(bv.component_sheet(
            Part("Bottom shell", C["bottom_shell"], COL["bottom"]), [M["shroud"], M["window"]],
            dwg_no="WSC-DWG-101", title="WasteWise Scan bottom shell: making sketch", material="PETG, 3D printed",
            inset_view=(40, -60),
            notes=["Print open side up, 0.2 mm layers, 5 perimeters (2.0 mm walls), 40 % infill.",
                   "Outside 160 x 62 x 16 mm, 10 mm corner radius; floor and walls 2.0 mm.",
                   "Tongue 1.2 x 2.6 mm stands up inside the rim; it locates the top shell.",
                   "Window hole 25.4 mm on the scan axis, 55 mm ahead of the centre.",
                   "Three 3.4 mm holes round it on a 40 mm circle for the shroud screws.",
                   "Four shell bosses 7 mm at 68 mm each side of centre, 20 mm out:",
                   "  3.4 mm through, 6.2 mm counterbore 3.2 mm deep from below.",
                   "Cell cradle: two 1.5 mm rails and two 3 mm end walls 75 mm apart.",
                   "Two strap bosses beside the cradle take M3 inserts (4 mm hole).",
                   "Tail wall: USB-C opening 9.5 x 3.8 mm, 8 mm up; seat inside for the board.",
                   "Right wall: switch slot 7 x 3.5 mm and two 2.4 mm holes 15 mm apart.",
                   "Check: the top shell drops over the tongue without force."],
            **base))
    if want(102):
        out.append(bv.component_sheet(
            Part("Top shell", C["top_shell"], COL["top"]), [M["bottom"], M["hood"]],
            dwg_no="WSC-DWG-102", title="WasteWise Scan top shell: making sketch", material="PETG, 3D printed",
            view_shape=Pos(0, 0, -D["top_z0"]) * C["top_shell"], inset_view=(28, -60),
            notes=["Print upside down (top face on the bed), same settings as the bottom shell.",
                   "Outside 160 x 62 x 17.4 mm; it sits on the gasket 16.6 mm up the body.",
                   "Display window 46 x 24 mm centred 10 mm behind the body centre.",
                   "Button hole 16.2 mm, 35 mm ahead of the body centre.",
                   "Four shell bosses reach down to meet the bottom shell bosses; they stop",
                   "  the gasket being squeezed below 0.6 mm. Press an M3 insert in each.",
                   "Four frame bosses at 30 mm behind and 10 mm ahead of centre, 19 mm",
                   "  out each side; press an M3 insert in each.",
                   "Two clip ribs 36 x 1 x 1 mm on the outside of the side walls, 28 mm up",
                   "  the body; the sun hood legs snap under them.",
                   "Inserts: soldering iron at about 230 C, push square, flush with the boss.",
                   "Check: each insert is square and flush; the ribs are unbroken."],
            **base))
    if want(103):
        out.append(bv.component_sheet(
            Part("Optical head block", C["led_holder"], COL["head"]), [M["bottom"], M["window"], M["afe"]],
            dwg_no="WSC-DWG-103", title="WasteWise Scan optical head block: making sketch", material="Black PETG, 3D printed",
            view_shape=Pos(-HX, 0, -D["holder_z0"]) * C["led_holder"], inset_view=(55, -60),
            notes=["Print in black PETG, top face on the bed, 0.1 mm layers, 100 % infill.",
                   "Disc 36 mm across, 7.2 mm tall, with three lugs for the shroud screws",
                   "  on a 40 mm circle; press an M3 insert into each lug from below.",
                   "Eight LED pockets 5.6 mm on a 20 mm circle, each tilted 23 degrees",
                   "  inward so the beams meet on the item; leads come out of the top.",
                   "Centre bore 5.6 mm for the photodiode can, with a step 4 mm up the",
                   "  body; below the step a 4 mm aperture and a baffle tube 7 mm across",
                   "  that stands 0.5 mm proud of the underside and rests on the window.",
                   "Two 3.5 mm holes 12 mm each side for M2.5 inserts (amplifier board).",
                   "Ream the LED pockets and the bore with a 5.6 mm drill by hand.",
                   "Check: each LED can slides in and stops square; the bore is black inside."],
            **base))
    if want(104):
        out.append(bv.component_sheet(
            Part("Light shroud", C["shroud"], COL["shroud"]), [M["bottom"], M["window"], M["head"]],
            dwg_no="WSC-DWG-104", title="WasteWise Scan light shroud: making sketch", material="Black TPU 95A, 3D printed",
            view_shape=Pos(-HX, 0, P["shroud_h"]) * C["shroud"], inset_view=(-35, -60),
            notes=["Print in black TPU 95A, flange on the bed, slow (about 20 mm/s).",
                   "Flange 47 mm across and 2.5 mm thick, with a 22 mm hole; the lip of the",
                   "  flange holds the window up into the body.",
                   "Cone 18 mm deep from the body: 30 mm across at the flange, 42 mm at the",
                   "  rim, 3 mm wall; 36 mm inside at the rim.",
                   "Three 3.4 mm holes on a 40 mm circle, at 90, 210 and 330 degrees",
                   "  (the first one toward the left side of the body).",
                   "Fit: three M3 x 10 screws with washers through the flange and the floor",
                   "  into the head block inserts. Snug only: TPU creeps if overtightened.",
                   "The shroud wears; it is replaced with the same three screws.",
                   "Check: the rim sits flat on a sheet of glass with no light under it."],
            **base))
    if want(105):
        out.append(bv.component_sheet(
            Part("Display frame", C["display_frame"], COL["frame"]), [M["top"], M["board"]],
            dwg_no="WSC-DWG-105", title="WasteWise Scan display frame: making sketch", material="PETG, 3D printed",
            view_shape=Pos(-P["board_x"], 0, -P["frame_z0"]) * C["display_frame"], inset_view=(-50, -60),
            notes=["Print with the lips and ears on the bed; the end walls bridge 26 mm.",
                   "Inside 62.4 x 26.4 mm, walls 2 mm, 12 mm tall to the shell ceiling.",
                   "Lips 2 mm wide under both long edges of the board, 1.75 mm thick.",
                   "Four ears 7 x 7 x 2.5 mm with 3.4 mm holes, 19 mm each side of the",
                   "  centre line, 30 mm behind and 10 mm ahead of the body centre.",
                   "Stick 0.5 mm foam tape on the lips so the board cannot rattle.",
                   "Fit: the display board drops in face up; the frame then goes into the",
                   "  upturned top shell with four M3 x 8 screws into the frame bosses.",
                   "The screen sits 0.25 mm under the shell ceiling, behind the window.",
                   "Check: the board drops in without force and the screen is centred."],
            **base))
    if want(106):
        out.append(bv.component_sheet(
            Part("Cell strap", C["cell_strap"], COL["strap"]), [M["bottom"], M["cell"]],
            dwg_no="WSC-DWG-106", title="WasteWise Scan cell strap: making sketch", material="PETG, 3D printed, 100 % infill",
            view_shape=Pos(-P["strap_x"], 0, -P["wall"] - 4.0) * C["cell_strap"], inset_view=(40, -60),
            notes=["Print on its side (the 10 mm face on the bed), 100 % infill.",
                   "A bridge 10 mm wide: top bar 33 x 8 mm, two legs 4 mm thick and",
                   "  14.75 mm tall, 29 mm apart between centres.",
                   "3.4 mm hole down through each leg and the bar.",
                   "Fit: the bar lies on top of the cell, 46 mm from the cell's spring end;",
                   "  the legs stand on the two strap bosses beside the cradle.",
                   "Two M3 x 25 low-head screws down through the strap into the inserts.",
                   "It holds the cell down in a drop: about 550 N at 1.3 times margin.",
                   "Check: the cell cannot lift and the screw heads are below 31 mm."],
            **base))
    if want(107):
        out.append(bv.component_sheet(
            Part("Sun hood", C["sun_hood"], COL["hood"]), [M["top"], M["bottom"], M["button"]],
            dwg_no="WSC-DWG-107", title="WasteWise Scan sun hood: making sketch", material="PETG, 3D printed",
            view_shape=Pos(-P["board_x"], 0, -P["body_h"]) * C["sun_hood"], inset_view=(30, -55),
            notes=["Print upside down on the wall tops, with support under the plate.",
                   "Plate 1.5 mm thick with the 46 x 24 mm display opening.",
                   "Walls 20 mm tall and 2 mm thick on both sides and the head end of the",
                   "  opening; the tail end is open toward the user.",
                   "Two clip legs 40 mm long, 2 mm thick, down both sides of the top shell;",
                   "  a lip on each leg snaps under the rib on the shell side.",
                   "Plate 68.4 mm across at the legs; legs 0.2 mm clear of the ribs.",
                   "Fit: press straight down until both lips click under the ribs. To take",
                   "  it off, spread the legs with the thumbs and lift.",
                   "Check: it does not lift when the scanner is shaken face down."],
            **base))
    if want(108):
        out.append(bv.component_sheet(
            Part("Calibration cap", S_cap(), COL["cap"]), [M["shroud"], M["bottom"]],
            dwg_no="WSC-DWG-108", title="WasteWise Scan calibration cap and PTFE disc: making sketch",
            material="Black PETG cap, 3D printed; PTFE sheet 3 mm",
            view_shape=Pos(-HX, 0, P["shroud_h"] + P["ptfe_t"] + 2.0) * S_cap(), inset_view=(20, -60),
            notes=["Cap: print open end up in black PETG, 100 % infill so no light passes.",
                   "46 mm across, 20 mm tall, floor 2 mm, bore 41.6 mm.",
                   "Disc: cut 41 mm from 3 mm white PTFE sheet with a knife and file;",
                   "  sand the top face matte with 400 grit; do not touch it after.",
                   "Press the disc into the cap, sanded face up; a drop of glue at the edge.",
                   "Fit: the cap pushes over the shroud; the bore grips the 42 mm rim and",
                   "  the rim rests on the disc, as it rests on an item when scanning.",
                   "The cap mouth stops 0.5 mm below the shroud flange.",
                   "Check: pushed fully on, the rim touches the disc all round."],
            **base))
    if want(109):
        out.append(bv.component_sheet(
            Part("Amplifier board", C["afe_board"], COL["afe"]), [M["head"], M["leds"], M["pd"]],
            dwg_no="WSC-DWG-109", title="WasteWise Scan amplifier board: making sketch", material="Perfboard, 2.54 mm pitch, 1.6 mm",
            view_shape=Pos(-HX, 0, -D["holder_z1"]) * C["afe_board"], inset_view=(45, -60),
            notes=["Cut 28 x 28 mm of perfboard; file the edges square.",
                   "Drill two 2.8 mm holes 12 mm from the scan axis toward the head end,",
                   "  12 mm each side, for M2.5 x 6 screws into the head block.",
                   "Hold the board on the head block with the LEDs and photodiode in their",
                   "  pockets and mark where every lead comes through; open those holes.",
                   "Build the amplifier, the 24-bit converter and the LED switches on the",
                   "  top face as the wiring picture shows; keep the photodiode input short.",
                   "The LED switches include a hardware limit on how long an LED can stay on.",
                   "Check: every lead passes through without bending the LED or photodiode."],
            **base))
    return out


def S_cap():
    return CAP["cal_cap"] + CAP["ptfe_disc"]


def joint_at(parts, pts, out, title, subtitle, elev, azim, size=(8, 6), dpi=160, cut=None):
    """bv.joint with the leader points given (one 3D point per part, on a face the camera sees)."""
    import numpy as np
    import matplotlib.pyplot as plt
    if cut:
        parts = bv._cut(parts, cut)
    W, H = int(size[0] * dpi), int(size[1] * dpi * bv.PIC_HEIGHT)
    img, proj, verts = bv._raster([(p, p.color, p.alpha, (0, 0, 0)) for p in parts], elev, azim, W, H)
    fig, ax = bv._frame(size, dpi, title, subtitle)
    ax.imshow(img, interpolation="bilinear")
    bv._draw_labels(ax, proj, [np.asarray(q, float) for q in pts], [p.name for p in parts], W, H)
    fig.savefig(out, facecolor="white"); plt.close(fig)
    return out


# ----------------------------------------------------------------- joints
def win(sh, x0, x1, y0, y1, z0, z1):
    from build123d import Box, Pos
    return sh & (Pos((x0 + x1) / 2, (y0 + y1) / 2, (z0 + z1) / 2) * Box(x1 - x0, y1 - y0, z1 - z0))
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

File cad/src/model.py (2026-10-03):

"""WasteWise Scan parametric model (build123d), TRL 3.
Rev P2 (2026-09-25): clip-on sun hood over the display added (WSC-DDR-003).
Rev P3 (2026-10-02): made constructable (WSC-DDR-004): shell screws, bosses, tongue and gasket;
optical head block clamped by the shroud flange; window clamped between flange and baffle;
cradle with end walls and cell contacts for a protected cell, cell strap; display frame;
panel-mount button; slide switch; USB-C board seat; clip legs on the sun hood; calibration cap
sized so the shroud rim rests on the PTFE disc.

Run from the repo root:  python cad/src/model.py          exports STEP and STL
                         python cad/src/model.py --check  runs the constructability checks
Exports STEP and STL into cad/step and cad/stl. PRELIMINARY, NOT FOR FABRICATION.

Axes: X along the body (scan head at +X), Y across the body, Z up. The underside of the
bottom shell is Z = 0. The shroud rim rests on the item being scanned at Z = -shroud_h.

The calculation note WSC-CAL-001 (docs/04-calcs/sizing.py) imports PARAMS, derived() and
the part solids from this file, so the numbers there follow any change made here.
"""
import sys
from math import atan2, cos, degrees, radians, sin
from pathlib import Path

# Top-level parameters (mm). Edit these, not the geometry below.
PARAMS = {
    # body
    "body_l": 160.0,          # body length
    "body_w": 62.0,           # body width
    "z_split": 16.0,          # top of the bottom shell rim
    "gasket_t": 0.6,          # foam gasket squeezed thickness; the top shell rim starts above it
    "body_h": 34.0,           # top of body
    "wall": 2.0,              # shell wall and floor thickness (2.0 mm decided 2026-10-02, R6)
    "corner_r": 10.0,         # plan corner radius
    "tongue_t": 1.2,          # locating tongue on the bottom shell, inside the top shell wall
    "tongue_h": 2.6,          # height of the tongue above the bottom shell rim
    "shell_screw_xy": (68.0, 20.0),   # four M3 shell screws at (+-x, +-y), from below
    "boss_d": 7.0,            # screw boss diameter
    "insert_d": 4.0,          # hole for an M3 heat-set insert
    # scan head (optical axis)
    "head_x": 55.0,           # optical axis position along the body
    "window_d": 25.0,         # borosilicate window diameter
    "window_t": 2.0,          # window thickness
    "shroud_h": 18.0,         # shroud depth below the body
    "shroud_rim_d": 42.0,     # outer diameter at the rim (item side)
    "shroud_top_d": 30.0,     # outer diameter at the body
    "shroud_wall": 3.0,
    "flange_d": 47.0,         # shroud clamping flange, against the underside of the body
    "flange_t": 2.5,
    "flange_id": 22.0,        # flange aperture; the flange lip holds the window from below
    "head_screw_r": 20.0,     # three M3 head screws on this radius, at 90, 210 and 330 deg
    # optics
    "pd_can_d": 5.4,          # photodiode TO-46 can diameter (1 mm active area)
    "pd_can_h": 4.0,
    "pd_z": 4.0,              # underside of the photodiode can (detector plane)
    "baffle_od": 7.0,         # baffle tube under the photodiode, down onto the window
    "baffle_id": 4.0,
    "led_n": 8,               # number of LED bands
    "led_can_d": 5.4,         # TO-46 SWIR LED can diameter (some bands are 5 mm T-1 3/4)
    "led_can_h": 5.0,
    "led_ring_r": 10.0,       # LED pitch circle radius
    "led_z": 5.5,             # LED can center height
    "holder_od": 36.0,        # printed optical head block (LED holder)
    "holder_id": 5.6,         # bore that takes the photodiode can
    "afe_w": 28.0,            # amplifier and ADC board, square
    "afe_t": 1.6,
    "afe_z": 10.5,            # board center height; the board sits on top of the head block
    "afe_screw": (12.0, 12.0),  # two M2.5 screws at (+x, +-y) from the optical axis
    # electronics and power
    "board_l": 62.0,          # ESP32-S3 display board (T-Display-S3 class), assumed envelope
    "board_w": 26.0,
    "board_h": 9.5,
    "board_x": -10.0,
    "board_z": 26.5,
    "frame_wall": 2.0,        # printed display frame around the board
    "frame_z0": 20.0,         # underside of the display frame lips and ears
    "frame_screws": ((-30.0, 19.0), (10.0, 19.0)),  # four M3 screws at (x, +-y)
    "disp_win_l": 46.0,       # display window in the top shell
    "disp_win_w": 24.0,
    # sun hood over the display (WSC-DDR-003 D10): clip-on, three walls, open toward the user (tail, -X)
    "hood_h": 20.0,           # wall height above the top shell
    "hood_wall": 2.0,
    "hood_base_t": 1.5,       # frame plate that sits on the top shell
    "hood_leg_l": 40.0,       # clip legs down both sides of the top shell
    "rib_z": 28.0,            # underside of the clip ribs on the top shell sides
    "cell_d": 18.5,           # protected 18650 cell (button top, about 69 mm long)
    "cell_l": 69.0,
    "cell_x": -24.0,
    "cell_z": 12.0,
    "cradle_end_t": 3.0,      # cradle end walls that carry the contacts (side rails 1.5 mm)
    "spring_l": 4.0,          # spring contact, compressed length
    "strap_x": -54.0,         # cell strap across the cell, outside the display board
    "strap_w": 10.0,
    "strap_t": 8.0,
    "usb_x": -76.0,           # USB-C socket at the tail wall
    "switch_x": -50.0,        # slide power switch in the right-hand side wall (-Y)
    "switch_z": 9.0,
    "button_x": 35.0,
    "button_d": 16.0,         # sealed 16 mm panel-mount push button (thread diameter)
    "button_bezel_d": 19.0,
    "button_h": 4.0,          # height above the top shell (bezel and cap)
    # calibration cap (stored on the shroud)
    "cap_od": 46.0,
    "cap_h": 20.0,
    "cap_wall": 2.2,
    "ptfe_d": 41.0,
    "ptfe_t": 3.0,
}
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

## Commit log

2026-09-25 Initial scaffold with portfolio kit v1.1.4: Circular Materials area, TRL 2
    Claude-Session: https://claude.ai/code/session_01XuhhSU4W6fYhgCfURbrkut
    [bom.csv]
2026-09-25 Adopt portfolio kit v1.3.0: session commands, scale figure, 3D viewer, flow diagrams
    Adds .claude/commands (/populate, /advance-trl3, /rein-in, /refresh-media)
    so every Claude Code session starts from the standard prompts, and extends
    concept media with a 1.75 m scale figure, an interactive glTF viewer and
    system or energy flow diagrams. TRL cap 3 unchanged.
    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
2026-09-25 Kit v1.3.1: renderer fixes from the TremorTrace pilot
    Context scale parts for small objects, cutaway exclusions, and text
    labels in flow diagrams.
    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
2026-09-25 Populate wastewise-scan to a strong TRL 2 with concept media (batch 7)
    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
    [bom.csv]
2026-09-25 Advance wastewise-scan to TRL 3 (batches 7 and 8)
    Decisions approved by Amish 2026-09-25 recorded in DDR-001. TRL 4 is on hold.
    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
    [bom.csv, wastewise-scan-assembly.step, wastewise-scan-bottom-shell.step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]
2026-09-26 Accept all recommendations (DDR-002), switch footer to designmolecule.com, add README write-up with new inspiration point
    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
    [bom.csv, wastewise-scan-assembly.step, wastewise-scan-bottom-shell.step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]
2026-09-26 Product appearance model and photoreal renders (pilot); kit 1.4.0 drawings name project and repository
    Adds cad/src/product_model.py and Blender renders (media/render-hero.png,
    media/render-exploded.png). The GA title names the device, view labels state
    the viewing direction and a product render replaces the line isometric.
    Kit 1.4.0: project and repository on every sheet and render, overall
    dimensions, ISO centre lines, 300 dpi PNG.
    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
    [product_model.py]
2026-10-01 Image quality pass: legible exploded views, flow diagrams and drawing sheets
    Kit 1.6.1 image layout: the parts list sits in its own column, number bubbles sit on visible parts and never overlap, small parts get a leader, pictures are cropped to the subject, flow labels keep numbers with their units, and sheet captions and the revision table no longer overprint. Concept images, blueprint and general arrangement sheet regenerated; repo-specific labels moved clear of other text and lines.
    [sheets.py]
2026-10-02 Kit 1.7.0: constructable design, illustrated build plan and design decisions register
    The design is now constructable: every part can be made and fits its neighbours, with each change recorded in a Design for construction decision record (made under Amish's 2026-09-30 instruction; ope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
    FlexHand also credits Dr. Geeti Chadha as a contribut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
    [bom.csv, wastewise-scan-assembly.step, wastewise-scan-bottom-shell.step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]
2026-10-03 Carry approved follow-ups into the design and redo photoreal renders
    Amish approved the follow-up actions from the open-decision sign-off ("APPROVED CHANGES, COMPLETE THESE", 2026-10-02), the design-for-construction change tables in ten repos, the last wave's open dec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
    [bom.csv, wastewise-scan-assembly.step, wastewise-scan-bottom-shell.step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]
2026-10-28 Kit 1.9.1 upgrade: pipeline documents and detailed CAD for every option
    Kit 1.9.1 installed (.kit, CLAUDE.md, .claude/commands). Kit 1.8 pipeline: STEM check with fixes under the 2026-10-23 standing instruction, concept options with the current design as option A, URS, PRS, generated RTM, REG, FEA, RSK with design FMEA, MKT, PLN and DDR; kit 1.9 D3 model of every option passing cad/fidelity.json; independent review recorded in the STEM check. Amish's 2026-10-25 decisions recorded where he approved a recommendation; all others proposed, awaiting Amish. Product renders and the options picture follow in a later commit where not yet included.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

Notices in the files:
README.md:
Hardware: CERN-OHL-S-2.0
